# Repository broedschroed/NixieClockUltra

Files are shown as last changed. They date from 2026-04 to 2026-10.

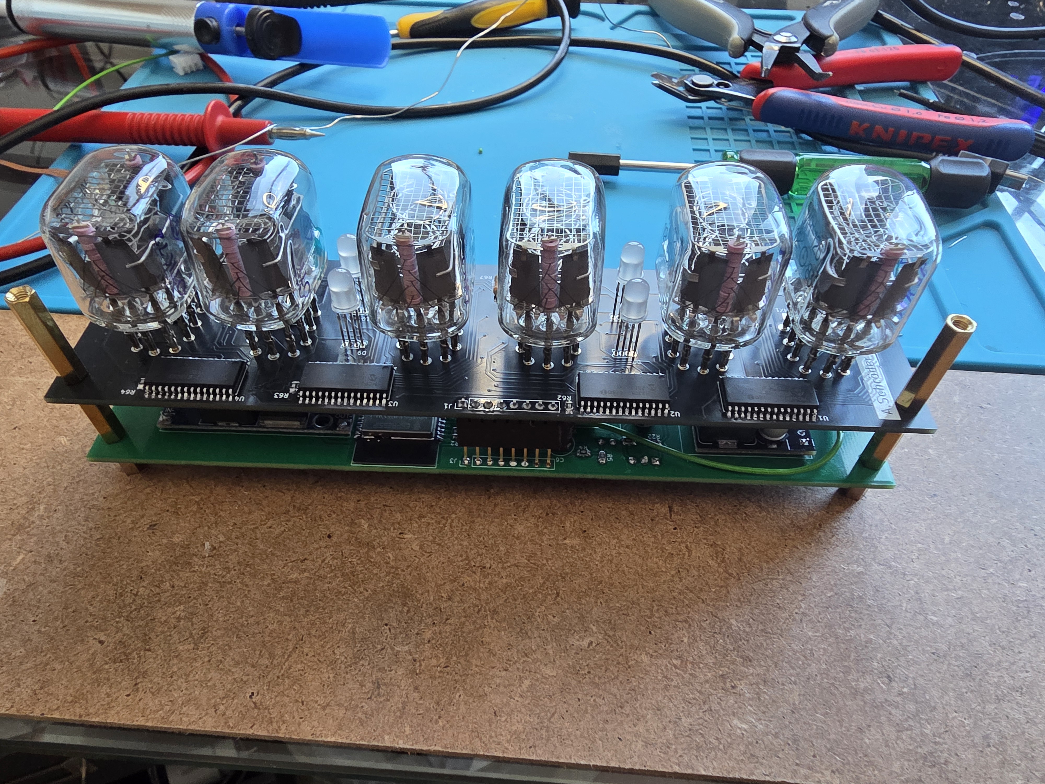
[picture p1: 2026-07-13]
docs/website/img/gallery/10 Chassis montiert.jpg

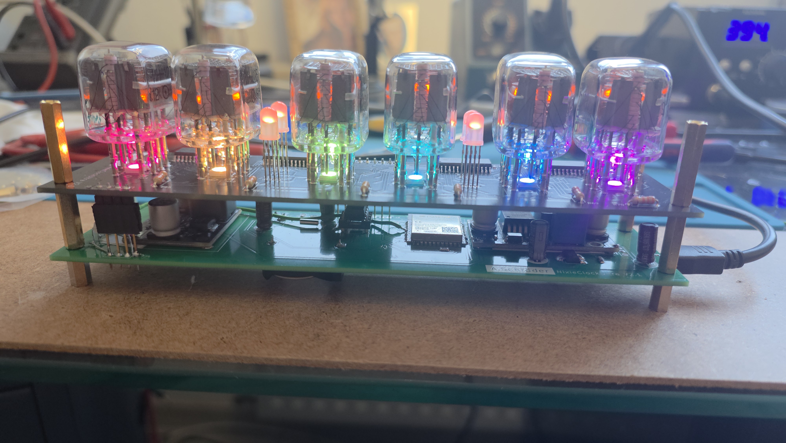
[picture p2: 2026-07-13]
docs/website/img/gallery/16 Chassis im Betrieb 3.jpg

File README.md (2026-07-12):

# Nixie Clock Ultra

A handcrafted Nixie tube clock built around an ESP32-S3, combining the warm,
unmistakable glow of six IN-12A Nixie tubes with modern connectivity: a full
web interface, IR remote, RGB ambient lighting, and automatic NTP time sync.

**🌐 Project website:** https://broedschroed.github.io/NixieClockUltra/

## Highlights

- **Direct drive, zero ghosting** — every cathode is switched by its own
  transistor (via MCP23017 I/O expanders), so there's no multiplexing and no
  flicker or ghosting between digits.
- **Web interface** — full control from any browser on the local network, no
  app required.
- **IR remote** — seven learnable functions (set time, brightness, animation,
  slot effect, colon toggle, ...).
- **RGB ambient lighting** — 10x WS2812B NeoPixels with rainbow, static, and
  pulse animation modes, plus a slot-machine digit-shuffle effect.
- **Night mode** — dims the tubes via hardware PWM on the anode voltage,
  triggered by a schedule or an onboard light sensor (LDR).
- **Soft digit transitions** — smooth crossfade between digits instead of an
  abrupt switch.
- **DS1302 RTC** with automatic NTP sync when connected to WiFi.

## Hardware

- ESP32-S3 (native USB)
- 6x IN-12A Nixie tubes, driven directly through 4x MCP23017 I2C expanders
- ~170V HV supply for the tubes, switched via a TLP627 opto-coupler for
  hardware-PWM dimming
- DS1302 RTC
- 10x WS2812B NeoPixels
- VS1838 IR receiver
- 4 physical buttons (Set / Up / Down / Light)

KiCad sources for the logic board and the Nixie display board are included
under `docs/system/`.

## Repository layout

- `*.ino` / `*.h` — firmware (Arduino/ESP32 sketch)
- `test/` — host-side unit tests for the fade math
- `docs/manual/` — user manual
- `docs/system/` — system documentation and KiCad hardware sources
- `docs/website/` — source of the project website (deployed via GitHub Pages)

## Building

Open the sketch in the Arduino IDE (or arduino-cli) with the ESP32 core
installed, board set to an ESP32-S3 module with **USB CDC on Boot: Enabled**,
and the required libraries (ArduinoJson, ESPAsyncWebServer, IRremoteESP8266,
Adafruit NeoPixel). Flash and connect to the `NixieClockCS` WiFi hotspot (or
your home network once configured) to reach the web interface.

## License

Released under the [MIT License](LICENSE).

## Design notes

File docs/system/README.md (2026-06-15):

# Nixie Clock Ultra – Systemdokumentation

Die Nixie Clock Ultra ist eine ESP32-S3-basierte Röhrenuhr mit 6 IN-12A Nixie-Röhren.
Die Hardware verteilt sich auf zwei Platinen: das **Logic Board** (ESP32-S3, RTC, HV-Versorgung)
und das **Nixie Display Board** (4× MCP23017 I²C-Expander, 60 NPN-Transistoren, NeoPixel-LEDs).
Die Nixie-Röhren werden direkt ohne Multiplexing angesteuert — jede Kathode hat einen
eigenen Transistor, was Ghosting vollständig eliminiert.

## Zweiplatinenübersicht

| Platine | KiCAD-Projekt | Hauptfunktion |
|---|---|---|
| Logic Board | nixieclocklogic_V2 | ESP32-S3, DS1302 RTC, HV-Modul, Taster, IR, USB |
| Nixie Display Board | nixieclockin12_V2 | 4× MCP23017, 6× IN-12A, 60× NPN, WS2812B |

Die Boards sind über zwei Steckverbinder verbunden:
- **J3 ↔ J1** (8-polig „Logic"): 3,3 V, GND, I²C (SDA/SCL), NeoPixel-Daten
- **J4 ↔ J2** (4-polig „HV"): ~170 V Anodenversorgung + HV-GND

## Systemblockschaltbild

```mermaid
flowchart TD
    subgraph PWR["Stromversorgung"]
        USB["5V USB / Netzteil"]
        LDO["AMS1117 → 3,3V"]
        HV["HV-MOD → ~170V DC"]
    end

    subgraph LB["Logic Board – ESP32-S3-WROOM-1"]
        ESP["ESP32-S3 Kern"]
        RTC_IC["DS1302 RTC\nIO=GPIO4 CLK=GPIO5 CE=GPIO2"]
        IR_IC["VS1838B IR-Empfänger\nGPIO48"]
        BTNS["Taster SET/UP/DOWN/LIGHT\nGPIO13–16"]
        NVS["NVS Flash\nPreferences"]
        WIFI["WiFi-Stack AP + STA"]
    end

    subgraph DB["Nixie Display Board"]
        MCP["4× MCP23017\nI²C-Adressen 0x20–0x23"]
        NPN["60× SMBTA42 NPN\nKathodenschalter"]
        NX["6× IN-12A Nixie-Röhren"]
        NEO["10× WS2812B NeoPixel\nGPIO21"]
    end

    NTP["NTP pool.ntp.org"]
    BROWSER["Web-Browser\nhttp://192.168.4.1"]

    USB --> LDO & HV
    LDO --> LB & DB
    HV -- "Anoden ~170V (via J4↔J2)" --> NX

    ESP -- "I²C SDA=GPIO8 SCL=GPIO9\n(via J3↔J1)" --> MCP
    MCP -- "64 GPIO-Ausgänge\n(je 16 pro IC)" --> NPN
    NPN -- "Kathoden auf GND ziehen" --> NX
    ESP -- "GPIO21 NeoPixel-Daten\n(via J3↔J1)" --> NEO
    ESP <-->|"ThreeWire"| RTC_IC
    IR_IC -->|"demoduliertes IR-Signal"| ESP
    BTNS -->|"INPUT_PULLUP"| ESP
    ESP <--> NVS
    ESP <--> WIFI
    WIFI -->|"einmalig bei STA-Verbindung"| NTP
    WIFI <-->|"HTTP /api/*"| BROWSER
```

## Bibliotheksabhängigkeiten

Alle Bibliotheken über den Arduino Library Manager installieren:

| Bibliothek | Autor / Quelle | Zweck |
|---|---|---|
| Adafruit NeoPixel  | Adafruit | WS2812B-Ansteuerung (GRB + RGB) |
| Rtc by Makuna | Michael C. Miller | DS1302 RTC über ThreeWire |
| AsyncTCP | me-no-dev | Async-TCP-Basis für ESP32 |
| ESPAsyncWebServer  | me-no-dev | Nicht-blockierender HTTP-Server |
| ArduinoJson | Benoit Blanchon | JSON-Serialisierung (v6.x, nicht v7) |
| IRremoteESP8266 | David Conran | IR-Empfang (NEC, Samsung, RC5 …) |

## Weiterführende Dokumente

- **Hardware-Details:** [hardware.md](hardware.md)
- **Firmware-Architektur:** [firmware.md](firmware.md)
- **Bedienungsanleitung:** [../manual/nixie-clock-ultra-bedienungsanleitung.html](../manual/nixie-clock-ultra-bedienungsanleitung.html)

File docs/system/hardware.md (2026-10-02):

# Hardware-Dokumentation

## PCB 1 – Logic Board

**KiCAD-Projekt:** `nixieclocklogic_V2-2` · Rev 2.1 · 2026-07-25

Das Logic Board beherbergt den Mikrocontroller, die Echtzeituhr, die Hochspannungserzeugung
und alle Nutzerschnittstellen (Taster, IR, USB). Es versorgt das Nixie Display Board
über zwei dedizierte Steckverbinder.

### Hauptkomponenten

| Ref  | Bauteil | Funktion |
|---|---|---|
| U1 | ESP32-S3-WROOM-1 | Mikrocontroller, WiFi/BT, 4 MB Flash |
| U2 | DS1302N+ (DIP-8) | Batteriegepufferte Echtzeituhr |
| U3 | VS1838B | IR-Empfänger/-Demodulator 38 kHz |
| U4 | HV-MOD | Boost-Converter, erzeugt ~170 V DC für Nixie-Anoden |
| U5 | AMS1117-3.3 (SOT-223)| LDO-Linearregler 5V → 3,3V |
| U7 | TLP627 (DIP-4) | Optokoppler schaltet Anodenspannung per Hardware-PWM (Nacht-Modus-Dimmung) |
| U22  | USBLC6-2SC6 (SOT-23-6)| USB-ESD-/TVS-Schutz |
| BT1  | CR2032 | RTC-Backup-Batterie |
| Y1 | 32,768 kHz Quarz | RTC-Taktquelle |
| SW1  | SET | Taster: Einstellmodus starten / Zeit speichern  |
| SW2  | UP | Taster: Wert erhöhen |
| SW3  | DOWN | Taster: Wert verringern |
| SW4  | LIGHT | Taster: Helligkeit / Trennpunkte |
| SW5  | BOOT | ESP32-Bootmodus (Programmierung) |
| J2 | USB Micro-B | 5V-Einspeisung und Firmware-Upload |
| J3 | Logic (8-polig) | Inter-Board: Logik-Signale → Nixie Display |
| J4 | HV (4-polig) | Inter-Board: ~170V Anodenversorgung → Display |
| J5 | LDR (2-polig) | Helligkeitssensor, bestückt: LDR→VCC, 100 kΩ→GND, Messung an GPIO6 |

### Versorgungsschienen

| Schiene | Spannung  | Quelle | Verbraucher |
|---|---|---|---|
| VCC | 5V | J2 USB | U4 HV-MOD, U5 AMS1117 |
| +3,3V | 3,3V | U5 | ESP32-S3, DS1302, VS1838B, Pull-ups  |
| HV | ~170V DC  | U4 | Nixie-Anoden (via J4) |
| HVgnd | GND (HV)  | U4 | HV-Rückleiter (galvanisch getrennt)  |

---

## PCB 2 – Nixie Display Board

**KiCAD-Projekt:** `nixieclockin12_V2-1` · Rev 2.01 · 2026-07-25

Das Display Board enthält die eigentliche Anzeigeelektronik. Die vier MCP23017 treiben
je 16 NPN-Transistoren, die die Nixie-Kathoden individuell auf GND schalten. Die Anoden
aller Röhren liegen gemeinsam an der über J4 eingespeisten Hochspannung (~170V), die
auf dem Logic Board per TLP627-Hardware-PWM gedimmt werden kann (siehe Nacht-Modus in
[firmware.md](firmware.md)).

**Optional:** Statt des einen gemeinsamen Schalters auf dem Logic Board kann jede Anode
über einen eigenen TLP627-Schalter auf dem Display Board unabhängig gedimmt werden
(6× TLP627 statt 1×, siehe Komponententabelle unten). Das ermöglicht einen weichen
Ziffernwechsel pro Röhre, bei dem unveränderte Ziffern nicht mitblinken. Aktiviert wird
das per `HV_PER_TUBE_DIMMER`-Compile-Switch in der Firmware
([firmware.md](firmware.md#wichtige-defines)) — ohne bestückte Zusatzschalter bleibt der
gemeinsame Schalter aktiv. Der gemeinsame Logic-Board-Schalter sollte bei dieser Umrüstung
entfernt oder dauerhaft überbrückt werden; die Firmware hält sein Steuersignal (GPIO7) bei
aktiviertem HV_PER_TUBE_DIMMER zur Sicherheit dauerhaft auf HIGH (offen), falls er nicht
ausgebaut wird.

### Hauptkomponenten

| Ref | Bauteil | Anzahl | Funktion |
|---|---|---|---|
| U1–U4 | MCP23017-E/SO (SOIC-28) | 4 | 16-bit I²C GPIO-Expander; je 16 Ausgänge |
| Q1–Q60 | SMBTA42 (TSOT-23) | 60 | NPN-Transistor 300V als Kathoden-Schalter |
| NX1–NX6  | IN-12A | 6 | Numerische Nixie-Röhre (Aufsicht, 10 Kathoden)  |
| D1 | WS2812B-SMD (×6) | 6 | Hintergrundbeleuchtung (Pixel 0–5, GRB) |
| D2–D6 | WS2812B-SMD | 5 | Zusätzliche LEDs / Trennpunkte (SMD) |
| D7–D9 | WS2812B-THT (YF923)  | 3 | Trennpunkt-LEDs (Durchsteck, RGB) |
| R1–R64 | 3,3 kΩ (0805) | 64 | Basis-Vorwiderstände für Q1–Q60 |
| R65–R70  | 22 kΩ (THT, axial) | 6 | Anodenwiderstände (Strombegrenzung je Röhre, ~1,5 mA bei ~175 V) — nicht kleiner wählen, sonst steigt die 5-V-Stromaufnahme über 1 A (Brownouts) |
| C1–C4 | 100 nF (0805) | 4 | Abblockkondensatoren je MCP23017 |
| J1 | Logic (8-polig) | 1 | Inter-Board: Logik-Signale ← Logic Board |
| J2 | HV (4-polig) | 1 | Inter-Board: ~170V ← Logic Board |
| U5–U10 | TLP627 (DIP-4) | 6 (optional) | Pro-Röhre-Anodenschalter — ersetzt bei Bestückung den gemeinsamen Logic-Board-Schalter für unabhängiges Dimmen jeder Röhre |

### MCP23017 I²C-Adressen und Röhrenzuordnung

Die Adresspins A2, A1, A0 der MCP23017 sind durch Pull-ups auf GND oder VCC verdrahtet:

| IC  | I²C-Adresse | A2 | A1 | A0 | Zuständige Röhre(n) |
|-----|---|----|----|----|---|
| U1  | 0x20 | 0  | 0  | 0  | Tube 0 (Stundenzehner), Tube 1 Bits 10–15 |
| U2  | 0x21 | 0  | 0  | 1  | Tube 1 Bits 0–3, Tube 2 (Minutenzehner) |
| U3  | 0x22 | 0  | 1  | 0  | Tube 3 (Minuteneiner), Tube 4 Bits 10–15|
| U4  | 0x23 | 0  | 1  | 1  | Tube 4 Bits 0–3, Tube 5 (Sekundeneiner) |

Jeder MCP23017 hat 16 Ausgänge (GPA0–7, GPB0–7). Die Tube-zu-Bit-Zuordnung ist
im Firmware-Modul `nixie_driver.ino` als `digitPin[6][10]`-Lookup-Tabelle implementiert
(→ [firmware.md](firmware.md#nixie-ansteuerung)).

### WS2812B NeoPixel-Konfiguration

Die 10 LEDs sind als verkettete Kette an GPIO21 angeschlossen:

| Pixel | Typ | Position | Farbreihenfolge |
|---|---|---|---|
| 0–5 | WS2812B-SMD | Röhrenhintergrund | GRB |
| 6–9 | WS2812B-THT | Trennpunkte | RGB |

> Die unterschiedliche Farbreihenfolge (GRB vs. RGB) der SMD- und THT-Varianten
> wird in der Firmware durch separate Farbberechnungen berücksichtigt.

---

## Inter-Board-Verbindungen

### J3 (Logic Board) ↔ J1 (Nixie Display Board) — 8-polig „Logic"

> Exakte Pin-Reihenfolge aus `nixieclocklogic_V2_BPHL.pdf` verifizieren.

| Signal  | Richtung | Beschreibung |
|---|---|---|
| VCC | Logic → Display | 3,3V Logikversorgung |
| GND | — | Digitalmasse |
| SDA | ESP32 ↔ MCP23017  | I²C Daten (GPIO8) |
| SCL | ESP32 → MCP23017  | I²C Takt (GPIO9) |
| NEO | ESP32 → D1 | WS2812B Datenleitung (GPIO21) |
| — | — | (reserviert) |

### J4 (Logic Board) ↔ J2 (Nixie Display Board) — 4-polig „HV"

| Signal | Richtung | Beschreibung |
|---|---|---|
| HV | Logic → Display | ~170V DC Anodenversorgung (×2 Pins) |
| HVgnd  | — | HV-Rückleiter (×2 Pins) |

---

## ESP32-S3 Pin-Belegung (vollständig)

| GPIO | Signal | Peripheral / Funktion |
|---|---|---|
| 2 | RTC_CE | DS1302 Chip Enable (ThreeWire) |
| 4 | RTC_IO | DS1302 Data (ThreeWire) |
| 5 | RTC_CLK | DS1302 Clock (ThreeWire) |
| 6 | LDR_ADC | LDR-Helligkeitssensor (ADC1, LDR→VCC, 100 kΩ→GND) |
| 7 | HV_SWITCH | TLP627-Optokoppler: Hardware-PWM (100 Hz, LEDC) schaltet Anodenspannung für Nacht-Modus-Dimmung |
| 8 | I2C_SDA | I²C Daten → 4× MCP23017 |
| 9 | I2C_SCL | I²C Takt → 4× MCP23017 |
| 10 | BTN_LIGHT | Taster LIGHT (INPUT_PULLUP, aktiv LOW) |
| 11 | BTN_DOWN  | Taster DOWN (INPUT_PULLUP, aktiv LOW)  |
| 12 | BTN_UP | Taster UP (INPUT_PULLUP, aktiv LOW) |
| 13 | BTN_SET | Taster SET (INPUT_PULLUP, aktiv LOW) |
| 15 | HV_TUBE_PIN_2 | *(optional)* Pro-Röhre-TLP627 Minutenzehner (nur bei `HV_PER_TUBE_DIMMER`) |
| 16 | HV_TUBE_PIN_3 | *(optional)* Pro-Röhre-TLP627 Minuteneiner (nur bei `HV_PER_TUBE_DIMMER`) |
| 17 | HV_TUBE_PIN_4 | *(optional)* Pro-Röhre-TLP627 Sekundenzehner (nur bei `HV_PER_TUBE_DIMMER`) |
| 18 | HV_TUBE_PIN_5 | *(optional)* Pro-Röhre-TLP627 Sekundeneiner (nur bei `HV_PER_TUBE_DIMMER`) |
| 21 | NEO_DATA  | WS2812B DIN (10 LEDs in Kette) |
| 38 | HV_TUBE_PIN_0 | *(optional)* Pro-Röhre-TLP627 Stundenzehner (nur bei `HV_PER_TUBE_DIMMER`) |
| 47 | HV_TUBE_PIN_1 | *(optional)* Pro-Röhre-TLP627 Stundeneiner (nur bei `HV_PER_TUBE_DIMMER`) |
| 48 | IR_RECV | VS1838B demodulierter Ausgang |

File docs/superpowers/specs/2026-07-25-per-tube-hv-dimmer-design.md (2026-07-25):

# Design: Pro-Röhre-HV-Dimmer für weichen Ziffernwechsel

## Kontext

Die IN-12-Leiterkarte wird so umgebaut, dass jede der 6 Nixie-Anoden optional
einen eigenen TLP627-Optokoppler-Schalter bekommt, statt sich (wie heute) einen
einzigen gemeinsamen Schalter (`HV_SWITCH_PIN`, GPIO7) zu teilen. Die neue
Bestückung ist optional — bestehende, unmodifizierte Uhren müssen sich nach
dem Firmware-Update exakt wie zuvor verhalten.

**Heutiges Verhalten:** Beim weichen Ziffernwechsel (`digit_fade.ino`) wird die
gemeinsame Anodenspannung aller 6 Röhren ab- und wieder aufgeblendet — auch für
Röhren, deren Ziffer sich gar nicht ändert (z. B. blinken beim Sekundentakt
Stunden/Minuten sichtbar mit).

**Ziel:** Mit den 6 separaten Schaltern soll nur die Röhre abblenden, deren
Ziffer sich tatsächlich ändert; unveränderte Röhren bleiben durchgehend hell.
Der weiche Übergang soll außerdem auch im gedimmten Nacht-Modus laufen (aktuell
nur bei `NIGHT_NORMAL`), dort zwischen Minimal-Duty und der reduzierten
Ziel-Helligkeit (`hvDimPct`) statt bis 100 %.

Ein Compile-Time-`#define` schaltet zwischen Alt- und Neu-Verhalten, da die
Hardware optional bestückt wird.

## 1. Pin-Belegung

Neue Defines in `NixieClockUltra.ino`, nur wirksam wenn `HV_PER_TUBE_DIMMER`
aktiviert ist:

```cpp
// Bei bestücktem Pro-Röhre-HV-Schalter (6× TLP627) einkommentieren:
// #define HV_PER_TUBE_DIMMER
#define HV_TUBE_PIN_0  38   // Stundenzehner (HZ)
#define HV_TUBE_PIN_1  47   // Stundeneiner  (HE)
#define HV_TUBE_PIN_2  15   // Minutenzehner (MZ)
#define HV_TUBE_PIN_3  16   // Minuteneiner  (ME)
#define HV_TUBE_PIN_4  17   // Sekundenzehner(SZ)
#define HV_TUBE_PIN_5  18   // Sekundeneiner (SE)
```

Ausgewählt unter Vermeidung von: Strapping-Pins (0, 3, 45, 46), nativem USB
(19, 20), JTAG (39–42), PSRAM/Octal-Flash-Bereich (26–37), sowie GPIO 1 und 14
(vom Nutzer für einen externen USB-Treiber reserviert) und allen bereits
belegten Pins (RTC 2/4/5, LDR 6, HV_SWITCH_PIN 7, I²C 8/9, Buttons 10–13,
NeoPixel 21, IR 48).

**Offener Punkt:** Vor dem Verdrahten gegenchecken, dass die konkrete
WROOM-1-Variante keine PSRAM/Flash-Sonderfunktion auf einem der 6 vorgeschlagenen
Pins hat.

## 2. Hardware-Abstraktion (`hv_dimmer.ino`)

Zwei API-Funktionen statt bisher einer, mit `#ifdef`-Zweig komplett isoliert in
dieser einen Datei:

```cpp
#ifdef HV_PER_TUBE_DIMMER
static const uint8_t hvTubePin[6] = {
  HV_TUBE_PIN_0, HV_TUBE_PIN_1, HV_TUBE_PIN_2,
  HV_TUBE_PIN_3, HV_TUBE_PIN_4, HV_TUBE_PIN_5
};

void hvDimmerInit() {
  for (uint8_t i = 0; i < 6; i++) {
    ledcAttach(hvTubePin[i], HV_PWM_FREQ_HZ, 8);
    ledcWrite(hvTubePin[i], 255);
  }
}
void hvDimmerSetDutyAll(uint8_t duty) {
  for (uint8_t i = 0; i < 6; i++) ledcWrite(hvTubePin[i], duty);
}
void hvDimmerSetDutyTube(uint8_t tube, uint8_t duty) {
  ledcWrite(hvTubePin[tube], duty);
}

#else  // heutige Hardware: ein gemeinsamer Schalter
void hvDimmerInit() {
  ledcAttach(HV_SWITCH_PIN, HV_PWM_FREQ_HZ, 8);
  ledcWrite(HV_SWITCH_PIN, 255);
}
void hvDimmerSetDutyAll(uint8_t duty) { ledcWrite(HV_SWITCH_PIN, duty); }
void hvDimmerSetDutyTube(uint8_t /*tube*/, uint8_t duty) { ledcWrite(HV_SWITCH_PIN, duty); }
#endif
```

Im Alt-Zweig ignoriert `hvDimmerSetDutyTube()` den Röhrenindex und steuert den
gemeinsamen Schalter an — dadurch bleibt das heutige Verhalten (alle dimmen
gemeinsam bei jeder Änderung) automatisch erhalten, ohne dass `digit_fade.ino`
selbst ein `#ifdef` braucht.

LEDC-Kanäle: 1 (Alt-Zweig) bzw. 6 (Neu-Zweig), beide Zweige schließen sich
gegenseitig aus — bleibt klar unter dem Limit von 8 Kanälen des ESP32-S3.

## 3. Fade-Logik (`digit_fade.ino` + `digit_fade_math.h`)

Neue reine, host-testbare Helfer-Funktion in `digit_fade_math.h`:

```cpp
inline uint8_t computeChangedMask(const uint8_t oldDigits[6], const uint8_t newDigits[6]) {
  uint8_t mask = 0;
  for (uint8_t i = 0; i < 6; i++) if (oldDigits[i] != newDigits[i]) mask |= (1 << i);
  return mask;
}
```

`display.ino`s `commitDigits()` berechnet die Maske **vor** dem Überschreiben
von `displayDigits` und reicht sie an `startDigitFade(newDigits, mask, fadeMs)`
durch.

Fade-Zustand bleibt ein **gemeinsamer** Schritt-Zähler (kein Bedarf an 6
unabhängigen Timern, da alle aktuellen Trigger — Sekundentakt, manuelles
Setzen, Datumsanzeige — Ziffern immer gemeinsam committen). Zusätzlich zum
bisherigen Zustand:

- `fadeMask` — welche Röhren-Bits betroffen sind
- `fadeMaxDuty` — Ziel-Helligkeit oben, einmalig beim Fade-Start ermittelt:
  `255` bei `NIGHT_NORMAL`, `hvDimPct * 255 / 100` bei `NIGHT_DIM`

`updateDigitFade()`: iteriert pro Schritt nur über die in `fadeMask` gesetzten
Bits und ruft `hvDimmerSetDutyTube(i, duty)` auf — unveränderte Röhren werden
nie angefasst.

**Verhaltensänderung:** Die Trigger-Bedingung in `commitDigits()` wechselt von
`nightState == NIGHT_NORMAL` zu `nightState != NIGHT_DARK`, damit der weiche
Wechsel jetzt auch im Dimm-Modus läuft. In `NIGHT_DARK` bleibt es beim harten
Umschalten (Anodenspannung ist ohnehin aus, ein Fade wäre unsichtbar).

`cancelDigitFade()` / `fadeFinishImmediately()`: setzen beim vorzeitigen
Abbruch nur die Röhren aus der aktuellen `fadeMask` auf `fadeMaxDuty` zurück
(nicht mehr pauschal alle 6) — verhindert ein falsches Aufblitzen auf 100 % bei
einem Nacht-Modus-Wechsel während eines laufenden Fades.

## 4. Anpassungen bestehender Aufrufstellen

Reines Rename `hvDimmerSetDuty(...)` → `hvDimmerSetDutyAll(...)`, keine
Logikänderung, an:

- `NixieClockUltra.ino` — Nacht-Zustands-Switch (~Zeile 413–415)
- `tube_test.ino` — Röhrentest erzwingt volle Helligkeit (~Zeile 17) und eigener
  Nacht-Zustands-Switch (~Zeile 43–45)
- `web_server.ino` — Live-Update von `hvDimPct` während `NIGHT_DIM` (~Zeile 746)

## 5. Test-Plan

- `test/digit_fade_math_test.cpp` erweitert um Fälle für `computeChangedMask()`:
  keine Änderung (`mask == 0`), eine Röhre geändert, alle 6 geändert, Bit-Position
  entspricht Röhren-Index (0 = HZ … 5 = SE).
- Bestehende `fadeDutyForStep()`-Tests bleiben unverändert gültig.
- Hardware-Test auf echtem Board:
  1. `HV_PER_TUBE_DIMMER` **aus**: Sekunden-/Minuten-/Stundenwechsel, Nacht-Modus,
     Röhrentest durchklicken — nichts darf sich gegenüber heute verändert haben.
  2. `HV_PER_TUBE_DIMMER` **an** (mit bestückter Hardware): nur wechselnde
     Ziffern blenden ab, unveränderte bleiben durchgehend hell; Fade funktioniert
     auch im Dimm-Modus.

## 6. Doku-Updates

- `docs/system/hardware.md` — neuer Abschnitt zu den 6 optionalen TLP627 in der
  Pin-Belegungstabelle und bei „Nixie Display Board"; Hinweis auf Optionalität.
- `docs/system/firmware.md` — Modulübersicht (`hv_dimmer.ino`-Zeile), neue
  Defines, `hvDimmerSetDutyAll()`/`hvDimmerSetDutyTube()` statt
  `hvDimmerSetDuty()`, Nacht-Modus-Logik-Abschnitt.
- `docs/manual/nixie-clock-ultra-bedienungsanleitung.html` — Hinweis im
  Hardware-Kapitel, dass der weiche Ziffernwechsel bei bestückter
  Pro-Röhre-Option jetzt nur die wechselnde Ziffer abblendet (ohne
  Bauteilnamen im Fließtext, gemäß bisherigem Schreibstil).
- `docs/website/aufbau.html` / `docs/website/features.html` — TLP627-Erwähnung
  um „optional pro Röhre nachrüstbar" ergänzen, Feature-Beschreibung des weichen
  Ziffernwechsels aktualisieren.

## Out of Scope

- Keine Laufzeit-Umschaltung (NVS/Web-UI) zwischen Alt- und Neu-Hardware —
  bewusst Compile-Time-`#define`, da die Hardware-Variante pro gebauter Uhr fest
  ist.
- Keine unabhängigen Timer pro Röhre — aktuell kein Anwendungsfall, der
  zeitlich versetzte Fades einzelner Röhren bräuchte.

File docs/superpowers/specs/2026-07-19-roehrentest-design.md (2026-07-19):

# NixieClockUltra – Röhrentest

**Datum:** 2026-07-19
**Status:** Genehmigt
**Branch:** neu anzulegen von `master`

---

## Überblick

Diagnose-Feature für die Nixie-Röhren: Ein Web-UI-Button zeigt auf
allen 6 Röhren gleichzeitig nacheinander jede Ziffer 0–9 für je 2
Sekunden an (20s Gesamtlaufzeit). Zweck: optisch prüfen, ob jede
Ziffer in jeder Röhre sauber leuchtet (defekte Kathode, kalte
Lötstelle an Transistor/MCP23017) – die bestehende Slot-Machine-
Animation reicht dafür nicht, da sie pro Röhre nur kurz durchrollt
und nie alle Röhren synchron auf derselben Ziffer stehen bleiben.

Kein neues physisches Bedienelement, keine IR-Anbindung – ausschließlich
über die Web-UI, ergänzt in der bestehenden Karte "Slot-Animation".

---

## 1. State-Machine (neues Modul `tube_test.ino`)

Analog zu `updateSlotAnimation()` / `updateDigitFade()`: non-blocking,
angetrieben von `updateTubeTest()` in `loop()`.

```cpp
bool     tubeTestActive    = false;
uint8_t  tubeTestDigit     = 0;      // 0–9, aktuell angezeigte Ziffer
uint32_t tubeTestStepStart = 0;
#define  TUBE_TEST_STEP_MS 2000

void startTubeTest() {
  cancelDigitFade();
  slotActive     = false;   // laufende Slot-Animation abbrechen
  dateShowActive = false;   // laufende Datumsanzeige abbrechen
  editState      = EDIT_NONE;   // Einstellmodus verlassen

  tubeTestActive    = true;
  tubeTestDigit     = 0;
  tubeTestStepStart = millis();

  hvDimmerSetDuty(255);   // volle Helligkeit erzwingen, unabhängig von Nacht-Modus

  uint8_t d[6] = {0,0,0,0,0,0};
  memcpy(displayDigits, d, 6);
  nixieWrite(displayDigits);   // sofort hart, kein Fade
}

void updateTubeTest() {
  if (!tubeTestActive) return;
  if (millis() - tubeTestStepStart < TUBE_TEST_STEP_MS) return;

  tubeTestDigit++;
  if (tubeTestDigit > 9) {
    stopTubeTest();
    return;
  }
  tubeTestStepStart = millis();
  uint8_t d[6] = {tubeTestDigit, tubeTestDigit, tubeTestDigit,
                  tubeTestDigit, tubeTestDigit, tubeTestDigit};
  memcpy(displayDigits, d, 6);
  nixieWrite(displayDigits);
}

void stopTubeTest() {
  if (!tubeTestActive) return;
  tubeTestActive = false;

  // HV-Duty passend zum aktuellen Nacht-Modus-Zustand wiederherstellen
  switch (nightState) {
    case NIGHT_DARK:   hvDimmerSetDuty(0);                    break;
    case NIGHT_DIM:    hvDimmerSetDuty(hvDimPct * 255 / 100); break;
    case NIGHT_NORMAL: hvDimmerSetDuty(255);                  break;
  }
  prevNightState = nightState;   // verhindert doppelte Duty-Anwendung im nächsten loop()

  setDisplayTime(curHour, curMin, curSec);   // Uhrzeit sofort wieder anzeigen
}
```

**Re-Start-Verhalten:** Aufruf von `startTubeTest()` während der Test
bereits läuft ist erlaubt und setzt ihn einfach auf Ziffer 0 zurück
(kein Fehlerfall). `stopTubeTest()` ohne aktiven Test ist ein No-op.

**Doppelte Nacht-Modus-Duty-Anwendung:** `NixieClockUltra.ino::loop()`
erkennt Nacht-Modus-Wechsel über `nightState != prevNightState` und
setzt dann die Duty. `stopTubeTest()` setzt `prevNightState` explizit
mit, damit dieser Vergleich direkt danach nicht erneut anschlägt und
die gerade gesetzte Duty nicht überschreibt.

---

## 2. Integration `NixieClockUltra.ino::loop()`

Bestehende Blöcke werden um `!tubeTestActive`-Guards ergänzt, damit
die normale Uhr während des Tests nicht dazwischenschreibt:

```cpp
// RTC-Lese-Block: Sekundentakt-Update / Slot-Trigger nur außerhalb Test
if (editState == EDIT_NONE && millis() - lastRtcRead >= 500) {
  lastRtcRead = millis();
  readRTC();
  if (curSec != lastSec) {
    lastSec = curSec;
    if (!tubeTestActive) {
      // ... bestehende Slot-Trigger-/setDisplayTimeSoft-Logik unverändert
    }
  }
}

// Slot-Animation-Update: unverändert, da slotActive bereits durch
// startTubeTest() auf false gesetzt wird

// Einstellmodus: während des Tests pausiert, damit ein SET-Tastendruck
// nicht parallel den Editiermodus startet
if (!tubeTestActive) handleEditMode();

updateTubeTest();   // neu, an der Stelle von updateDigitFade()
```

Der bestehende `nightState != prevNightState`-Block (HV-Duty bei
Nacht-Modus-Wechsel) bleibt unverändert – er greift während des Tests
nicht, weil `stopTubeTest()` `prevNightState` synchron mitführt (siehe
oben); ein Nacht-Modus-Wechsel *während* eines laufenden Tests würde
aber weiterhin die Duty umschalten (Testabbruch durch Nacht-Modus ist
nicht vorgesehen – vernachlässigbarer Edge-Case, Test läuft nur 20s
und wird typischerweise manuell direkt am Gerät ausgelöst).

---

## 3. Web-UI

### 3.1 Karte (bestehende "🎰 Slot-Animation", umbenannt)

```html
<div class="card">
  <h2>🎰 Slot-Animation &amp; Röhrentest</h2>
  <!-- ... bestehende Slot-Intervall/Geschwindigkeit/Trigger-Reihen unverändert ... -->

  <div class="row">
    <button id="tubeTestBtn" onclick="toggleTubeTest()">Röhrentest starten</button>
    <span class="badge" id="tubeTestStatus">bereit</span>
  </div>
</div>
```

### 3.2 JavaScript

```js
let tubeTestRunning = false;

async function toggleTubeTest(){
  if (tubeTestRunning) await api('/api/tubetest/stop', {});
  else                 await api('/api/tubetest/start', {});
}
```

`refreshClock()` (bestehendes 1s-Polling von `/api/status`) wird
erweitert:

```js
if (d.tubeTest !== undefined) {
  tubeTestRunning = d.tubeTest;
  document.getElementById('tubeTestBtn').textContent =
    tubeTestRunning ? 'Abbrechen' : 'Röhrentest starten';
  document.getElementById('tubeTestStatus').textContent =
    tubeTestRunning ? `Ziffer ${d.tubeTestDigit}/9` : 'bereit';
}
```

### 3.3 Neue Endpunkte (`web_server.ino`)

```cpp
server.on("/api/tubetest/start", HTTP_POST, [](AsyncWebServerRequest *req){
  startTubeTest();
  req->send(200, "application/json", "{\"ok\":true}");
});

server.on("/api/tubetest/stop", HTTP_POST, [](AsyncWebServerRequest *req){
  stopTubeTest();
  req->send(200, "application/json", "{\"ok\":true}");
});
```

### 3.4 `/api/status` Erweiterung

```cpp
doc["tubeTest"]      = tubeTestActive;
doc["tubeTestDigit"] = tubeTestDigit;
```

`StaticJsonDocument<384>` auf `448` erhöhen (zwei zusätzliche Felder).

---

## 4. Nicht Teil dieser Änderung

- Kein physischer Tasten- oder IR-Trigger (nur Web-UI).
- Keine Konfigurierbarkeit der Anzeigedauer (fest 2s) oder Ziffernfolge
  über die Web-UI.
- Kein automatischer Abbruch bei Nacht-Modus-Wechsel während eines
  laufenden Tests (siehe Edge-Case-Hinweis in Abschnitt 2).
- Keine Änderung an NeoPixel-Verhalten während des Tests.

---

## 5. Testplan (manuell, auf Hardware)

- **Normalablauf:** Röhrentest starten → alle 6 Röhren zeigen
  synchron 0,1,2…9 für je ~2s, danach automatische Rückkehr zur
  aktuellen Uhrzeit. Button-Beschriftung/Badge wechseln währenddessen
  korrekt zwischen "Röhrentest starten"/"Abbrechen" und
  "bereit"/"Ziffer n/9".
- **Abbruch:** Während des Tests auf "Abbrechen" klicken → sofortige
  Rückkehr zur Uhrzeit, kein Hängenbleiben.
- **Neustart während laufendem Test:** Start-Endpoint erneut aufrufen
  → Test beginnt sichtbar wieder bei Ziffer 0.
- **Interaktion Nacht-Modus:** Test im `NIGHT_DIM`/`NIGHT_DARK`-Zustand
  starten → Röhren leuchten während des Tests mit voller Helligkeit;
  nach Testende kehrt die Dimmung korrekt zum vorherigen Zustand
  zurück (kein dauerhaftes "hängenbleiben" bei 100%).
- **Interaktion Einstellmodus/Slot:** Test während laufender
  Slot-Animation bzw. während SET-Taste gedrückt/Editiermodus aktiv
  auslösen → beide werden sauber abgebrochen, kein doppeltes
  Beschreiben der Röhren.

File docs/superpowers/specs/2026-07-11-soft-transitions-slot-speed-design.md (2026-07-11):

# NixieClockUltra – Weicher Ziffernwechsel & Slot-Machine-Geschwindigkeit

**Datum:** 2026-07-11
**Status:** Genehmigt
**Branch:** neu anzulegen von `master` (nach Commit `0516472`)

---

## Überblick

Zwei unabhängige, kleine Firmware-Erweiterungen, gemeinsam auf einem
Branch umgesetzt:

1. **Weicher Ziffernwechsel** – nutzt den bestehenden HV-Dimmer
   (`hv_dimmer.ino`, TLP627 auf `HV_SWITCH_PIN`) für einen kurzen
   Crossfade der gesamten Anodenspannung beim Wechsel zwischen
   Zeit- und Datumsanzeige, sowie optional bei jedem Sekundentakt.
2. **Slot-Machine-Geschwindigkeit** – ein Web-UI-Regler skaliert die
   Roll- und Stopp-Zeiten der bestehenden Slot-Animation
   (`updateSlotAnimation()`).

Beide Features sind per Web-UI ein-/ausschaltbar bzw. einstellbar und
persistieren ihre Einstellung in NVS (`Preferences`), analog zu allen
bestehenden Einstellungen im Projekt.

---

## 1. Weicher Ziffernwechsel

### 1.1 Scope

- Betrifft **ausschließlich** zwei Übergänge, jeweils per eigenem
  Web-UI-Toggle:
  - **Sekundentakt** (`softFadeSecondEnabled`, NVS-Key `sfSecEn`,
    Default `false`): jeder reguläre Zeit-Update-Aufruf
    (`curSec != lastSec`, außerhalb Slot-Animation/Datumsanzeige).
    Fade-Dauer: **100ms**.
  - **Zeit↔Datum-Wechsel** (`softFadeDateEnabled`, NVS-Key `sfDateEn`,
    Default `false`): Übergang Slot-Ende→Datumsanzeige und
    Datumsanzeige-Ende→Zeit. Fade-Dauer: **200ms**.
- **Nicht** betroffen: Slot-Machine-Animation selbst (rollt bereits
  schneller als eine Fade-Dauer), Editiermodus-Blinken
  (`buttons.ino`, ruft `nixieWrite()` direkt), Initialisierung/NTP-Sync.
- Der Effekt ist **nur im Zustand `NIGHT_NORMAL`** aktiv (volle
  Anodenspannung). Im Dimm-/Dunkel-Zustand bleibt der Ziffernwechsel
  hart, wie bisher – wird zentral erzwungen, nicht nur an den
  Aufrufstellen geprüft (siehe 1.3).
- Minimalhelligkeit während des Fades: **5%** Duty (≈13 von 255),
  fest codiert (`#define DIGIT_FADE_MIN_DUTY 13`).

### 1.2 Warum ein globaler Fade (kein Pro-Röhre-Crossfade)

Der TLP627 dimmt die Anodenspannung aller 6 Röhren gemeinsam über
einen einzigen LEDC-Kanal – es gibt keine Pro-Röhre-Dimmung. Ein Fade
betrifft daher immer das komplette Display, nicht nur die sich
ändernde Ziffer. Eine echte Pro-Röhre-Überblendung (zwei Kathoden
gleichzeitig an einer Röhre, Duty-Cycle-Verschiebung) wurde als
Alternative erwogen, aber verworfen: sie erfordert eine Prüfung, ob
der Anoden-Vorwiderstand doppelten Kathodenstrom verträgt, und
nähert sich konzeptionell der Mehrfach-Ansteuerung an, die beim
Anti-Ghosting-Umbau (Mai/Juni 2026) bewusst vermieden wurde. Nicht
Teil dieser Spec.

### 1.3 Neues Modul `digit_fade.ino`

Non-blocking State-Machine, angetrieben von `updateDigitFade()` in
`loop()` (wie `updateSlotAnimation()`):

```cpp
#define DIGIT_FADE_MIN_DUTY   13   // ~5% von 255
#define DIGIT_FADE_STEP_MS    5    // Schrittintervall

enum FadeState { FADE_IDLE, FADE_DOWN, FADE_UP };
static FadeState fadeState = FADE_IDLE;
static uint8_t   fadeTargetDigits[6];
static uint32_t  fadeLastStepMs;
static uint8_t   fadeStepsTotal;
static uint8_t   fadeStepsDone;

// Schließt einen laufenden Fade sofort ab (Zielziffern schreiben,
// Duty auf 255). Wird aufgerufen, wenn ein neuer Fade angefordert
// wird während einer noch läuft, oder wenn sich nightState während
// eines Fades ändert (verhindert Race mit der Nacht-Modus-Duty-
// Steuerung in NixieClockUltra.ino).
static void fadeFinishImmediately();

void startDigitFade(uint8_t newDigits[6], uint16_t fadeMs);
void updateDigitFade();   // in loop() aufrufen
void cancelDigitFade();   // von NixieClockUltra.ino bei nightState-Wechsel aufgerufen
```

**Ablauf pro Fade:**
1. `fadeStepsTotal = max(1, (fadeMs / 2) / DIGIT_FADE_STEP_MS)`
   (100ms → 10 Schritte runter + 10 rauf; 200ms → 20 + 20).
2. `FADE_DOWN`: pro Schritt Duty linear von 255 auf 13 interpolieren,
   `hvDimmerSetDuty()`.
3. Bei letztem Runter-Schritt: `nixieWrite(fadeTargetDigits)` (Ziffer
   bei Minimalhelligkeit umschalten), Zustand → `FADE_UP`.
4. `FADE_UP`: Duty linear von 13 zurück auf 255, letzter Schritt setzt
   exakt 255 und Zustand → `FADE_IDLE`.

### 1.4 Integration `display.ino`

`setDisplayTime()`/`setDisplayDate()` bleiben unverändert als
"sofort hart schreiben"-Funktionen (Startup, Editiermodus-Bestätigung
etc. nutzen weiterhin genau diese, unverändertes Verhalten). Beide
Funktionen und ihre neuen Soft-Varianten laufen über eine gemeinsame
interne Funktion:

```cpp
static void commitDigits(uint8_t newDigits[6], uint16_t fadeMs) {
  bool changed = memcmp(newDigits, displayDigits, 6) != 0;
  memcpy(displayDigits, newDigits, 6);
  if (!changed) return;
  if (fadeMs > 0 && nightState == NIGHT_NORMAL) {
    startDigitFade(newDigits, fadeMs);
  } else {
    nixieWrite(displayDigits);
  }
}

void setDisplayTime(uint8_t h, uint8_t m, uint8_t s);              // commitDigits(d, 0)
void setDisplayTimeSoft(uint8_t h, uint8_t m, uint8_t s, uint16_t fadeMs);
void setDisplayDate();                                              // commitDigits(d, 0)
void setDisplayDateSoft(uint16_t fadeMs);
```

### 1.5 Aufrufstellen `NixieClockUltra.ino`

Drei Stellen in `loop()` werden angepasst (fadeMs jeweils `0`, wenn
das zugehörige Toggle aus ist – identisch zum heutigen Verhalten):

- Sekundentakt (aktuell `setDisplayTime(curHour, curMin, curSec)`
  im `if (!slotActive && !dateShowActive)`-Zweig) →
  `setDisplayTimeSoft(curHour, curMin, curSec, softFadeSecondEnabled ? 100 : 0)`.
- Slot-Ende → Datumsanzeige (aktuell `setDisplayDate()`) →
  `setDisplayDateSoft(softFadeDateEnabled ? 200 : 0)`.
- Datumsanzeige-Ende → Zeit (aktuell `setDisplayTime(curHour, curMin, curSec)`) →
  `setDisplayTimeSoft(curHour, curMin, curSec, softFadeDateEnabled ? 200 : 0)`.

Zusätzlich: im bestehenden `nightState != prevNightState`-Block
(vor dem Setzen der nacht-modus-abhängigen Duty) wird
`cancelDigitFade()` aufgerufen, damit ein laufender Fade nicht mit
der Nacht-Modus-Duty-Steuerung kollidiert.

### 1.6 Web-UI & NVS

Neue Karte "Weicher Ziffernwechsel" mit zwei Checkboxen
("Bei Sekundentakt", "Bei Zeit/Datum-Wechsel"). Neuer Endpunkt
`/api/softfade`, GET (Status) + POST (Toggle setzen), Muster analog
zu `/api/nightmode`:

```cpp
server.on("/api/softfade", HTTP_GET, [](AsyncWebServerRequest *req) {
  // JSON: { sec: bool, date: bool }
});
server.on("/api/softfade", HTTP_POST, ...,
  // { sec?: bool, date?: bool } – nur übergebene Felder ändern
  // prefs.putBool("sfSecEn", ...) / prefs.putBool("sfDateEn", ...)
);
```

Laden beim Boot in `setup()` (analog zu `hvDimPct`):
```cpp
softFadeSecondEnabled = prefs.getBool("sfSecEn", false);
softFadeDateEnabled   = prefs.getBool("sfDateEn", false);
```

---

## 2. Slot-Machine-Geschwindigkeit

### 2.1 Scope

Neuer Regler in der Web-UI (bestehende Animations-Karte, neben
"Slot-Intervall"), Bereich **20%–100%**, Default **100%** (= aktuelles
Verhalten unverändert). Werte unter 100% verlangsamen die Animation,
keine Beschleunigung über die heutige Geschwindigkeit hinaus.

### 2.2 Variable & Persistenz

```cpp
uint8_t slotSpeedPct = 100;   // 20–100, NVS-Key "slotSpeed"
```

Laden in `setup()`:
```cpp
slotSpeedPct = (uint8_t)constrain((int)prefs.getUChar("slotSpeed", 100), 20, 100);
```

### 2.3 Anwendung in `display.ino`

Die beiden heute fest codierten Timing-Konstanten in
`updateSlotAnimation()` (Roll-Intervall 60ms, Stopp-Zeitplan
`600 + i*180`ms) werden **einmalig bei Animationsstart** skaliert und
zwischengespeichert – nicht pro Frame neu berechnet, damit ein
Reglerwechsel während einer laufenden Animation diese nicht
"ruckeln" lässt. Die neue Geschwindigkeit greift erst bei der
nächsten Animation.

```cpp
uint16_t slotRollIntervalMs;   // = 60 * 100 / slotSpeedPct
uint16_t slotStopMs[6];        // = (600 + i*180) * 100 / slotSpeedPct

void startSlotAnimation(uint8_t h, uint8_t m, uint8_t s) {
  slotRollIntervalMs = 60UL * 100 / slotSpeedPct;
  for (int i = 0; i < 6; i++) slotStopMs[i] = (600UL + i * 180) * 100 / slotSpeedPct;
  // ... bestehender Rest unverändert (slotTarget/slotCurrent/slotActive/slotStartMs)
}

void updateSlotAnimation() {
  // ... elapsed wie bisher
  // stopTime = slotStopMs[i]  statt  600 + i*180
  // Rollbedingung: (millis() % slotRollIntervalMs) < (slotRollIntervalMs / 2)
  //   statt  (millis() % 60) < 30
}
```

Bei 20%: Roll-Intervall 300ms, letzte Röhre stoppt nach 7,5s statt
1,5s. Bei 100%: unverändert.

### 2.4 Web-UI & NVS

Neuer Regler (`<input type="range" min="20" max="100">`), Endpunkt
`/api/slotspeed` (POST `{val}`), Muster analog zu `/api/neobright`.
Aktueller Wert zusätzlich in `/api/status` (`doc["slotSpeed"]`),
damit der Regler beim Laden der Seite korrekt initialisiert wird.

```cpp
server.on("/api/slotspeed", HTTP_POST, [](AsyncWebServerRequest *req){}, ...,
  [](AsyncWebServerRequest *req, uint8_t *data, size_t len, ...) {
    // JSON {val: int}
    slotSpeedPct = (uint8_t)constrain(doc["val"].as<int>(), 20, 100);
    prefs.putUChar("slotSpeed", slotSpeedPct);
    req->send(200, "application/json", "{\"ok\":true}");
  });
```

---

## 3. Testplan (manuell, auf Hardware)

- **Weicher Ziffernwechsel Sekundentakt:** Toggle an, `NIGHT_NORMAL`,
  beobachten dass jede Sekunde ein kurzes Abdunkeln/Aufhellen aller
  Röhren sichtbar ist (~100ms). Toggle aus → sofortiger Wechsel wie
  bisher.
- **Weicher Ziffernwechsel Zeit/Datum:** Slot-Intervall auf `SLOT_10S`
  stellen, warten bis Slot-Animation endet und Datumsanzeige startet
  → 200ms-Fade beobachten; nach 5s Rückwechsel zur Zeit → ebenfalls
  200ms-Fade.
- **Interaktion mit Nacht-Modus:** Während eines Sekundentakt-Fades
  in den Dimm-Zustand wechseln (LDR abdecken oder Zeitbereich
  triggern) → kein hängender Zwischenzustand, Duty landet korrekt auf
  Dimm-Helligkeit.
- **Slot-Speed:** Regler auf 20% stellen, Slot-Animation auslösen
  (manueller Trigger-Button in Web-UI) → deutlich langsameres Rollen,
  letzte Röhre stoppt nach ~7,5s. Regler zurück auf 100% → Verhalten
  wie vor dieser Änderung.
- Reboot nach jedem Test: alle vier neuen Einstellungen
  (`sfSecEn`, `sfDateEn`, `slotSpeed`, und ggf. Regler-Position in der
  UI) bleiben erhalten (NVS-Persistenz).

---

## Nicht Teil dieser Änderung

- Pro-Röhre-Crossfade (Dual-Kathoden-Technik, siehe 1.2).
- Konfigurierbarkeit von Fade-Dauer (100/200ms) oder Minimalhelligkeit
  (5%) über die Web-UI – fest codiert.
- Geschwindigkeiten über 100% (schneller als heute) für die
  Slot-Animation.

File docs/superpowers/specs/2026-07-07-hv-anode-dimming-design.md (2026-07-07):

# NixieClockUltra – Hardware-Dimmung der Anodenspannung (TLP627)

**Datum:** 2026-07-07
**Status:** Genehmigt
**Branch:** `feature/hv-anode-dimming` (abgezweigt von `master` nach Commit `a50de45`)

---

## Überblick

Ersatz der bisherigen Software-PWM-Dimmung der Nixie-Röhren (zyklisches
Kathoden-Blanking über die MCP23017, nur im Nacht-Modus aktiv) durch
echtes Hardware-PWM auf der Anodenspannung. Ein neuer GPIO steuert über
einen TLP627-Optokoppler direkt die Anodenspannung – der
Photodarlington-Ausgang des TLP627 ist laut Datenblatt
(„Recommended Operating Conditions“, Supply Voltage max. 200V) für die
~170V-Anodenspannung ausreichend spannungsfest, ein zusätzlicher
HV-Schalter ist nicht nötig.

**Scope:** Ausschließlich Ersatz von `NIGHT_DIM`/`NIGHT_DARK` für die
Nixie-Röhren. Volle Helligkeit (`NIGHT_NORMAL`) bleibt fest an. Die
NeoPixel-Dimmung im Nacht-Modus (`NIGHT_DIM_NEO_PCT`, per-Pixel
`scaleColor()`) ist unverändert und nicht Teil dieser Änderung.

Bereits in der Nacht-Modus-Spec vom 2026-06-21 als Option B vermerkt
(„Hardware-PWM für Nixie – kann später nachgerüstet werden“).

---

## 1. Hardware-Interface

### 1.1 GPIO

```cpp
#define HV_SWITCH_PIN  7   // unbenutzt, kein Strapping-Pin, neben LDR (GPIO6)
```

### 1.2 Signal-Vertrag

- **Aktiv-Pegel:** HIGH-Duty = Anode an (nicht invertiert).
- **PWM:** ESP32-S3 LEDC-Hardware-Peripherie, 8-Bit-Auflösung (Duty 0–255).
- **Frequenz:** 200 Hz (`#define HV_PWM_FREQ_HZ 200`) – deutlich über der
  Flimmerschwelle, aber im Bereich, den ein TLP627-getriebener
  HV-Schalter (Photodarlington-Schaltzeiten typisch einige zehn µs)
  sauber nachbilden kann. Bei Bedarf nach Hardware-Aufbau per
  Oszilloskop verifizieren und `#define` anpassen.

### 1.3 Downstream-Hinweis (nicht Teil dieser Firmware-Änderung)

Der TLP627-Photodarlington-Ausgang liegt direkt in Reihe mit der
Anodenspannung (kein zusätzlicher HV-Schalter nötig). Zwei Punkte, die
bei der analogen Dimensionierung zu beachten sind (Hardware-Sache des
Users, nicht Gegenstand dieser Spec):
- **Collector Current max. 120mA** – Summe des Anodenstroms aller 6
  Röhren muss darunter bleiben.
- **Forward Current typ. 16mA** – bestimmt den Vorwiderstand von
  GPIO7 zur TLP627-LED.

---

## 2. Neues Modul `hv_dimmer.ino`

```cpp
void hvDimmerInit();                      // ledcAttach(HV_SWITCH_PIN, HV_PWM_FREQ_HZ, 8) + volle Helligkeit
void hvDimmerSetDuty(uint8_t duty0to255); // ledcWrite(HV_SWITCH_PIN, duty0to255)
```

Kapselt die LEDC-Details (Core-3.x-API: `ledcAttach(pin, freq, resolution)`
statt der alten `ledcSetup()`/`ledcAttachPin()`-Kombination) an einer
Stelle.

`hvDimmerInit()` wird in `setup()` nach `strip.begin()`-Block aufgerufen
und setzt initial volle Helligkeit (Duty 255).

---

## 3. Integration in Nacht-Modus (`NixieClockUltra.ino`)

### 3.1 Entfernter Code

Der komplette bisherige Software-PWM-Block in `loop()` entfällt:
- `nixiePwmOn` (Variable + Logik)
- `lastPwmToggle`
- zyklisches `nixieWrite(blank)` / `nixieWrite(displayDigits)`-Umschalten
- `#define NIGHT_DIM_PWM_PERIOD` und `#define NIGHT_DIM_DUTY_PCT`

Die Röhren zeigen im Nacht-Modus durchgehend die echten Ziffern
(`nixieWrite(displayDigits)` wie tagsüber) – ohne Anodenspannung
leuchtet nichts, ein Blank-Schreiben ist überflüssig.

### 3.2 Neue Logik beim Zustandswechsel

```cpp
if (nightState != prevNightState) {
  prevNightState = nightState;
  switch (nightState) {
    case NIGHT_DARK:   hvDimmerSetDuty(0);                     break;
    case NIGHT_DIM:    hvDimmerSetDuty(hvDimPct * 255 / 100);  break;
    case NIGHT_NORMAL: hvDimmerSetDuty(255);                   break;
  }
}
```

### 3.3 Neue Konfigurationsvariable

```cpp
uint8_t hvDimPct = 25;   // Dimm-Helligkeit in %, NVS-Key "hvDimPct", Range 5–95
```

Ersetzt die feste `NIGHT_DIM_DUTY_PCT`-Konstante. Wird zusätzlich neu
angewendet, wenn der Slider im Web-UI während `nightState == NIGHT_DIM`
verändert wird (kein Zustandswechsel nötig).

---

## 4. Web-UI (`web_server.ino`)

### 4.1 Karte „🌙 Nacht-Modus“ – neues Element

Neuer Slider zwischen „Modus“-Dropdown und „Lichtsensor aktiv“:

```html
<div class="row"><label>Dimm-Helligkeit</label>
  <input type="range" id="hvDimPct" min="5" max="95" value="25"
    oninput="document.getElementById('hvDimPctVal').textContent=this.value">
  <span id="hvDimPctVal">25</span>%</div>
```

Wird wie die übrigen Nacht-Modus-Felder beim Klick auf „Übernehmen“ per
`saveNightMode()` mitgeschickt.

### 4.2 API-Erweiterung

**`GET /api/nightmode`** – zusätzliches Feld `"hvDimPct": 25`.

**`POST /api/nightmode`** – akzeptiert zusätzlich `hvDimPct` (uint8,
5–95, `constrain()`), persistiert via `prefs.putUChar("hvDimPct", ...)`.

### 4.3 NVS-Keys (Namespace `"nixie"`, Ergänzung zur bestehenden Tabelle)

| Key | Typ | Bedeutung |
|---|---|---|
| `hvDimPct`| uint8 | Röhren-Dimm-Helligkeit in % (5–95)  |

---

## 5. Dateien-Übersicht

| Datei | Änderung |
|---|---|
| `hv_dimmer.ino` | **Neu** – LEDC-Kapselung (`hvDimmerInit()`, `hvDimmerSetDuty()`) |
| `NixieClockUltra.ino`  | `HV_SWITCH_PIN`/`HV_PWM_FREQ_HZ` #defines, `hvDimPct` Global + NVS-Laden, `hvDimmerInit()` in `setup()`, Software-PWM-Block in `loop()` entfernt und durch `hvDimmerSetDuty()`-Aufrufe ersetzt |
| `web_server.ino` | Neuer Slider in Nacht-Modus-Karte, `/api/nightmode` GET+POST um `hvDimPct` erweitert |

---

## 6. Verifikation

Kein Compiler/Hardware-Zugriff in dieser Umgebung verfügbar – die
Implementierung ist code-vollständig, aber ungetestet abzunehmen.
Manueller Testablauf nach Hardware-Aufbau:

1. **Isoliert (ohne HV):** GPIO7-Signal mit Oszilloskop/Logic-Analyzer
   prüfen – 200 Hz, korrekter Duty bei jedem `nightState`-Übergang
   (0 / `hvDimPct` / 255) und bei Slider-Änderung.
2. **TLP627-Stufe separat:** LED-Vorwärtsstrom und sauberes Schalten
   der Anodenspannung am TLP627-Ausgang messen, bevor die Röhren
   dranhängen.
3. **Am fertigen Gerät:** Nacht-Modus-Zeitfenster testweise aktivieren,
   `hvDimPct`-Slider 5–95% durchfahren → sichtbares, flackerfreies
   Dimmen. Dunkel-Modus prüfen → Röhren komplett aus, kein Nachglühen.
4. **Regressionscheck:** `NIGHT_NORMAL` weiterhin volle, stabile
   Helligkeit; Taster/IR-Bedienung unverändert; NeoPixel-Nachtdimmung
   (unverändert im Code) weiterhin korrekt.

---

## 7. Nicht im Scope

- Mehrstufige/stufenlose Röhren-Helligkeit außerhalb des Nacht-Modus
  (der Web-UI-„Nixie-Helligkeit“-Dropdown bleibt wirkungslos für die
  Röhren, wie bisher).
- Änderungen an der NeoPixel-Dimmung.
- Dimensionierung des LED-Vorwiderstands am GPIO7/TLP627 sowie Prüfung
  des Anodenstroms gegen die 120mA-Collector-Current-Grenze – reine
  Hardware-Aufgabe des Users.
- Nicht-blockierendes WiFi-Connect (separates, bereits besprochenes Thema).

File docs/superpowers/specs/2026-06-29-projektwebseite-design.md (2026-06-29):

# Design-Spec: Nixie Clock Ultra – Projektwebseite

**Datum:** 2026-06-29
**Status:** Genehmigt, bereit zur Implementierung

---

## Ziel

Mehrseitige, lokale Projektwebseite für die Nixie Clock Ultra. Technologie: reines
HTML/CSS/JS (statisch, kein Build-Schritt). Steampunk-Ästhetik: dunkel-industriell,
Messing-/Goldakzente, Nixie-Orangeglühen, gravierte Typografie. Später direkt auf
Webserver oder GitHub Pages übertragbar.

---

## Dateistruktur

```
docs/website/
├── index.html            Startseite
├── features.html         Features & Werbetext
├── aufbau.html           Hardware-Aufbau, PCBs, Schematics
├── geschichte.html       Entwicklungshistorie & Problemlösungen
├── dokumentation.html    Downloads (Systemdoku, Anleitung)
├── galerie.html          Fotogalerie
├── css/
│   └── style.css         Globales Stylesheet (Steampunk-Theme)
├── js/
│   ├── nav.js            Gemeinsamer Header + Footer (per JS injiziert)
│   └── lightbox.js       Galerie-Lightbox (Vanilla JS)
├── img/
│   ├── hero.jpg          Hero-Foto Startseite (vom Nutzer bereitgestellt)
│   ├── gallery/          Alle Galeriefotos (vom Nutzer bereitgestellt)
│   └── pcb/              PCB-Bilder (symlink/kopie aus docs/system/assets/)
└── downloads/
    ├── NixieClockUltra-Systemdokumentation.odt
    ├── NixieClockUltra-Systemdokumentation.pdf
    └── NixieClockUltra-Bedienungsanleitung.pdf
```

---

## Design-System

### Farbpalette (CSS Custom Properties)

```css
--bg-base:        #0e0a05   /* Seitenhintergrund, tiefstes Schwarz-Braun */
--bg-panel:       #1c1408   /* Inhalts-Panels, leicht erhöht */
--bg-panel-hover: #241a0a   /* Panel-Hover-Zustand */
--text-primary:   #e8d5a3   /* Haupttext, Pergament-Creme */
--text-muted:     #a08c6a   /* Gedämpfter Text, Beschriftungen */
--accent-gold:    #c8961a   /* Primärakzent, Messing-Gold */
--accent-copper:  #cd7f32   /* Sekundärakzent, Kupfer */
--accent-nixie:   #ff8c00   /* Nixie-Glühen, für Highlights */
--border-dim:     #3a2a10   /* Ruhige Rahmenlinie */
--border-gold:    #6b4f12   /* Goldener Rahmen */
```

### Typografie

- **Überschriften:** Cinzel (Google Fonts) — graviert-klassisch
- **Fließtext:** Crimson Text (Google Fonts) — warm, antiquarisch
- **Code/Technisch:** Liberation Mono / Courier New

### Dekorelemente

- **Zahnrad-Divider:** SVG-Inline-Elemente als horizontale Trennlinien zwischen Sektionen
- **Niet-Ecken:** CSS-Pseudo-Elemente (::before / ::after) an Panel-Ecken als kleine Kreise
- **Nav-Tabs:** Rechteckige Messing-Schilde, aktive Seite gold hinterlegt
- **Download-Buttons:** Geniete Metallplatten-Optik, Hover-Effekt mit Kupfer-Glow

---

## Globales Layout

Jede Seite besteht aus vier Zonen, die `nav.js` per `innerHTML` injiziert:

```
<body>
  <div id="site-header">  ← nav.js injiziert
  <nav id="site-nav">     ← nav.js injiziert, aktive Seite per data-page markiert
  <main id="content">     ← seitenspezifischer Inhalt
  <footer id="site-footer"> ← nav.js injiziert
```

**Header:** Schmales dunkles Band. Links kleines Zahnrad-SVG, mittig
„NIXIE CLOCK ULTRA" in Cinzel 28pt gold, darunter „broed digital media · 2026"
in Crimson Text 11pt gedämpft, rechts spiegelverkehrtes Zahnrad-SVG.

**Navigation:** Horizontale Leiste direkt unter Header. Sechs Tabs:
Startseite · Features · Aufbau · Geschichte · Dokumentation · Galerie.
Aktiver Tab: goldener Hintergrund, schwarzer Text. Hover: Kupfer-Glow.
Auf Mobilgeräten (< 768px): Hamburger-Icon, aufklappbares Dropdown.

**Content-Bereich:** max-width 1100px, zentriert, padding 2rem.

**Footer:** Schmale dunkle Leiste. Oben ein Niet-Separator (horizontale Linie
mit kleinen Kreisen). Text: „© 2026 broed digital media · Nixie Clock Ultra".

---

## Seiten im Detail

### 1. Startseite (`index.html`)

**Hero-Sektion (volle Viewport-Breite):**
- Hintergrundbild: `img/hero.jpg`, `object-fit: cover`, Höhe 70vh
- Dunkles Overlay: `rgba(0,0,0,0.55)` gradient
- Darüber zentriert:
  - „NIXIE CLOCK ULTRA" — Cinzel 52pt, gold
  - „wenn Zeit leuchtet" — Crimson Text 18pt, italic, kupfer
  - „→ Mehr erfahren"-Button (Link auf features.html)

**Highlight-Kacheln (3 Stück, Flex-Row):**
Unter dem Hero, jede Kachel: dunkles Panel, goldene Überschrift, ein Satz Text.
Inhalte: „Direct Drive — kein Ghosting", „WiFi & Web-Interface",
„Nacht-Modus & Lichtsensor".

**Teaser-Text:**
Erster Absatz aus Werbetext (`NixieClockUltra-Werbetext.odt`), max 250 Wörter.
Abschluss: Link „Alle Features →" zu features.html.

---

### 2. Features (`features.html`)

**Seitentitel:** „Features" in Cinzel h1, Zahnrad-Divider darunter.

**Fließtext-Block:** Vollständiger Werbetext (alle fünf Absätze).

**Feature-Gruppen:** Fünf dunkle Panels untereinander:
- Anzeige · Beleuchtung · Konnektivität & Bedienung · Nacht-Modus · Technik
- Jedes Panel: goldene Gruppenüberschrift (h3), Bullet-Liste mit „›"-Bullet in
  Nixie-Orange, Text in Crimson Text.

---

### 3. Aufbau (`aufbau.html`)

**Seitentitel:** „Aufbau & Hardware"

**Abschnitt Logic Board:**
Zweispaltig (auf Mobile einspaltig): links `img/pcb/logic_sch-1.png` +
`img/pcb/logic_pcb-1.png` als klickbare Thumbnails (öffnen Lightbox),
rechts Text: Rev 2.1, Komponenten-Highlights (ESP32-S3, DC-DC, HV-MOD, LDR),
USB-CDC-Warnung als farbige Hinweisbox.

**Abschnitt Nixie Display Board:**
Gleiche Zweispalten-Struktur mit `nixie_sch-1.png` + `nixie_pcb-1.png`,
Text: MCP23017 Direct Drive, 60 SMBTA42-Transistoren, kein Ghosting.

**Abschnitt Spannungsversorgung:**
SVG-Flussdiagramm: USB 5V → DC-DC (U6) → 10V → HV-MOD (U4) → 170V (Nixie-Anoden)
                    USB 5V → AMS1117 (U5) → 3,3V (Logik)
Goldene Pfeile, dunkle Beschriftungsboxen.

---

### 4. Geschichte (`geschichte.html`)

**Seitentitel:** „Entwicklungsgeschichte"

**Timeline-Layout:**
Vertikale goldene Linie mittig (auf Desktop links-mittig), Messing-Punkte als
Meilenstein-Marker. Jeder Eintrag: Datum in Nixie-Orange, Titel in Cinzel,
Kurztext in Crimson Text. Basis: Inhalt aus `docs/ENTWICKLUNGSHISTORIE.md`,
manuell als HTML aufbereitet.

**Probleme & Lösungen:**
CSS-only Akkordeon (checkbox-hack): Überschrift mit „▶"-Pfeil, Klick klappt
Lösungstext auf. Keine JS-Abhängigkeit.

---

### 5. Dokumentation (`dokumentation.html`)

**Seitentitel:** „Dokumentation & Downloads"

**Zwei Download-Karten** (Flex-Row, auf Mobile gestapelt):

*Karte 1 — Systemdokumentation:*
Icon (Zahnrad-SVG), Titel, Kurztext (2 Sätze), zwei Buttons:
„ODT herunterladen" + „PDF herunterladen" → `downloads/`

*Karte 2 — Bedienungsanleitung:*
Icon (Buch-SVG), Titel, Kurztext (2 Sätze), Button:
„PDF herunterladen" → `downloads/`

**Hinweis-Box:** „ODT-Dateien können mit LibreOffice geöffnet werden."

---

### 6. Galerie (`galerie.html`)

**Seitentitel:** „Galerie"

**Masonry-Grid:** CSS columns (3 Spalten Desktop, 2 Tablet, 1 Mobile).
Jedes Bild: dunkler Rahmen 3px `--border-gold`, leichter Box-Shadow,
Hover: leicht aufhellen + Kupfer-Glow.

**Lightbox (`lightbox.js`):**
- Klick auf Bild → Overlay mit schwarzem Hintergrund, Bild zentriert, max 90vw/90vh
- Navigation: Pfeil links/rechts (Tastatur + Klick)
- Schließen: Klick außerhalb oder ESC-Taste
- Kein externes Framework, ~60 Zeilen JS

---

## Responsive Breakpoints

| Breakpoint | Verhalten |
|---|---|
| > 1100px  | Volle Breite, max-width 1100px zentriert |
| 768–1100px | Zweispalten-Layouts bleiben, kleinere Schrift |
| < 768px | Alles einspaltig, Hamburger-Nav, Hero 50vh |

---

## Assets die vom Nutzer bereitgestellt werden

- `img/hero.jpg` — Hauptfoto der fertigen Uhr (für Hero-Sektion)
- `img/gallery/*.jpg` — Alle Galeriefotos

PCB-Bilder werden aus `docs/system/assets/` in `img/pcb/` kopiert.
Downloads werden aus bestehenden Docs-Ordnern in `downloads/` kopiert.

---

## Nicht im Scope

- Kein Server-Side-Rendering
- Kein CMS
- Kein CSS-Framework (Bootstrap, Tailwind etc.)
- Kein TypeScript / Build-Tool
- Keine Suchfunktion
- Keine Mehrsprachigkeit

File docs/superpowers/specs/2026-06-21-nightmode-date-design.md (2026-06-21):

# NixieClockUltra – Nacht-Modus & Datum-Anzeige

**Datum:** 2026-06-21  
**Status:** Genehmigt

---

## Überblick

Zwei unabhängige Erweiterungen, die zusammen implementiert werden:

1. **Nacht-Modus** – Nixie-Röhren und NeoPixel gedimmt oder abgeschaltet, ausgelöst durch Zeitfenster und/oder LDR-Sensor.
2. **Datum-Anzeige** – DS1302 liefert volles Datum; Anzeige für 5 Sekunden nach jeder Slot-Animation; editierbar per Taster und Web-UI.

---

## 1. Nacht-Modus

### 1.1 Zustände

```
enum NightState { NIGHT_NORMAL, NIGHT_DIM, NIGHT_DARK };
NightState nightState = NIGHT_NORMAL;
```

### 1.2 Trigger-Logik (Priorität: Zeitbereich > LDR)

**Zeitbereich** (konfigurierbar via Web-UI):
- `nightTimeEnabled` (bool)
- `nightStart`, `nightEnd` (uint8_t, 0–23)
- `nightTimeMode` (uint8_t, 0 = DIM, 1 = DARK)
- Mitternacht-Übergang wird unterstützt: `nightStart > nightEnd` → Bereich gilt wenn `h >= nightStart || h < nightEnd`

**LDR-Sensor** (nur DIM, nie DARK):
- `ldrEnabled` (bool)
- `ldrThreshold` (uint16_t, 0–4095; höherer Wert = Dimmen bei hellerer Umgebung)
- Pin: GPIO 6 (ADC1-Channel 5, funktioniert mit WiFi)
- Abtastung alle 500 ms, 4 ADC-Samples gemittelt
- ADC-Wert ≤ ldrThreshold → Dimmen (niedriger ADC-Wert = dunkle Umgebung, LDR hochohmig, Spannung am Pin sinkt)

**Priorität:**
```
if (nightTimeEnabled && timeInRange(curHour))
    nightState = (nightTimeMode == 1) ? NIGHT_DARK : NIGHT_DIM;
else if (ldrEnabled && ldrReading <= ldrThreshold)
    nightState = NIGHT_DIM;
else
    nightState = NIGHT_NORMAL;
```

### 1.3 Nixie-Dimming (Software-PWM)

Definiert in `NixieClockUltra.ino`:

```cpp
#define NIGHT_DIM_DUTY_PCT    25   // Nixie Ein-Anteil in % (~25 % Helligkeit)
#define NIGHT_DIM_PWM_PERIOD  20   // PWM-Periode in ms (= 50 Hz)
#define NIGHT_DIM_NEO_PCT     15   // NeoPixel-Helligkeit im Dimm-Modus in % der Normalhelligkeit
```

PWM-Gate in `loop()` (nur aktiv wenn `nightState == NIGHT_DIM`):
- `nixiePwmOn` toggled via `millis()`-Vergleich
- Toggle-Zeitpunkte: `lastPwmToggle + (nixiePwmOn ? onTime : offTime)`
  - `onTime  = NIGHT_DIM_PWM_PERIOD * NIGHT_DIM_DUTY_PCT / 100`
  - `offTime = NIGHT_DIM_PWM_PERIOD - onTime`
- Bei Toggle → `nixieWrite(displayDigits)` oder `nixieWrite(blank[6]={10,…})`

Bei `NIGHT_DARK`: einmalig `nixieWrite(blank)` beim Zustandswechsel.

### 1.4 NeoPixel-Dimming

In `updateNeoPixel()` vor der Pixel-Berechnung temporäre Skalierung (kein NVS-Schreiben):
- `NIGHT_NORMAL`: `neoBright` / `colonBright` unverändert
- `NIGHT_DIM`:    `neoBright * NIGHT_DIM_NEO_PCT / 100`, `colonBright * NIGHT_DIM_NEO_PCT / 100`
- `NIGHT_DARK`:   `neoBright = 0`, `colonBright = 0` (lokal, Original bleibt erhalten)

### 1.5 Neue Datei: `night_mode.ino`

Enthält:
- Globale Variablen (Konfiguration + Zustand)
- `updateNightMode()` – wird in `loop()` aufgerufen

### 1.6 NVS-Keys (Namespace `"nixie"`)

| Key | Typ | Bedeutung |
|---|---|---|
| `ntEn` | bool | Zeitbereich aktiv |
| `ntFrom` | uint8 | Startzeit (Stunde) |
| `ntTo` | uint8 | Endzeit (Stunde) |
| `ntMode` | uint8 | 0 = DIM, 1 = DARK |
| `ldrEn`  | bool | LDR aktiv |
| `ldrThr` | uint16  | ADC-Schwellwert (0–4095) |

### 1.7 Web-UI – Neue Karte „🌙 Nacht-Modus"

Position: zwischen Slot-Animation und IR-Fernbedienung.

Elemente:
- Toggle: Zeitbereich aktiv
- Zahlenfeld: Von (0–23), Bis (0–23)
- Dropdown: Modus (Gedimmt / Dunkel)
- Toggle: LDR-Sensor aktiv
- Slider: Schwellwert (0–4095; 0 = nur bei Totaldunkel dimmen, 4095 = immer gedimmt)
- Badge: aktueller Zustand (Normal / Gedimmt / Dunkel) – aus `/api/status`

### 1.8 Neue API-Endpunkte

**`GET /api/nightmode`** – liefert alle Nacht-Modus-Parameter.

**`POST /api/nightmode`** – setzt Parameter:
```json
{ "ntEn": true, "ntFrom": 23, "ntTo": 7, "ntMode": 1,
  "ldrEn": true, "ldrThr": 512 }
```

**`GET /api/status`** – erhält zusätzlich `"nightState": 0/1/2`.

---

## 2. Datum-Anzeige

### 2.1 Neue globale Variablen

```cpp
uint8_t curDay = 1, curMonth = 1, curYear = 24;  // Jahr zweistellig (00–99)
```

### 2.2 RTC-Anpassungen (`rtc.ino`)

**`readRTC()`**: liest zusätzlich `Day()`, `Month()`, `Year() % 100`.

**`writeRTC()`**: ersetzt hardcodierten `2024-1-1` durch `curDay`, `curMonth`, `curYear + 2000`.

### 2.3 Datum-Anzeige-Funktion (`display.ino`)

```cpp
void setDisplayDate() {
    displayDigits[0] = curDay   / 10;
    displayDigits[1] = curDay   % 10;
    displayDigits[2] = curMonth / 10;
    displayDigits[3] = curMonth % 10;
    displayDigits[4] = curYear  / 10;
    displayDigits[5] = curYear  % 10;
    nixieWrite(displayDigits);
}
```

Format: **TT MM JJ** (Tag-Monat-Jahr zweistellig), von links nach rechts.

### 2.4 Datum-Anzeige nach Slot-Animation

Neue Variablen in `NixieClockUltra.ino`:
```cpp
bool     dateShowActive = false;
uint32_t dateShowStart  = 0;
#define  DATE_SHOW_MS   5000
```

Ablauf in `loop()`:
- Wenn `slotActive` → false wechselt: `dateShowActive = true; dateShowStart = millis();`
- Solange `dateShowActive && millis() - dateShowStart < DATE_SHOW_MS`: `setDisplayDate()` aufrufen (alle 500 ms, synchron mit RTC-Read-Takt)
- Danach: `dateShowActive = false` → zurück zur Uhrzeitanzeige

`dateShowActive` verhindert gleichzeitig, dass ein neuer Slot oder RTC-Update das Display überschreibt.

### 2.5 Taster-Editiermodus – Erweiterung

```cpp
enum EditState {
    EDIT_NONE,
    EDIT_HOUR, EDIT_MIN, EDIT_SEC,
    EDIT_DAY, EDIT_MONTH, EDIT_YEAR
};
```

Erweiterte Sequenz:
```
SET → Stunde → SET → Minute → SET → Sekunde →
SET → Tag    → SET → Monat  → SET → Jahr    → SET (speichern)
```

- Tag: 1–31, Monat: 1–12, Jahr: 0–99 (zweistellig)
- Blinken der aktiven Stelle wie bei Uhrzeit (Röhrenpaar blinkt aus)
- `writeRTC()` wird erst beim letzten SET aufgerufen

### 2.6 Web-UI – Erweiterung der Zeit-Karte

Karte umbenannt: **„⏱ Zeit & Datum stellen"**

Neue Felder:
- Tag (1–31), Monat (1–12), Jahr (0–99)

„Browser-Zeit"-Button synchronisiert zusätzlich `new Date().getDate()`, `.getMonth()+1`, `.getFullYear() % 100`.

**`POST /api/settime`** – erweitert um optionale Felder `d`, `mo`, `y` (rückwärtskompatibel; wenn nicht übergeben bleibt das Datum unverändert).

**`GET /api/status`** – erhält zusätzlich `"date": "TT.MM.JJ"`.

### 2.7 NTP-Sync

Bereits korrekt: `RtcDateTime ntpTime(year, month, day, ...)` setzt volles Datum. Nach dem Sync liest `readRTC()` das Datum zurück (sobald es date-fähig ist).

---

## 3. Dateien-Übersicht

| Datei | Änderung |
|---|---|
| `NixieClockUltra.ino`  | Neue Globals, #defines, NVS-Ladevorgänge, Loop-Erweiterungen |
| `night_mode.ino` | **Neu** – Night-Mode-Logik, LDR-Abtastung, `updateNightMode()`  |
| `rtc.ino` | `readRTC()` + `writeRTC()` mit Datum |
| `display.ino` | `setDisplayDate()`, dateShowActive-Logik |
| `buttons.ino` | EditState um EDIT_DAY/MONTH/YEAR erweitert |
| `neo_animation.ino` | Temporäre Helligkeitsskalierung per NightState |
| `web_server.ino` | Neue Karte, neue API-Endpunkte, Status-Erweiterungen |

---

## 4. Nicht im Scope

- Wochentag-Anzeige
- Sommerzeit-Umschaltung (läuft bereits über NTP_TZ)
- Alarm-Funktion
- Hardware-PWM für Nixie (kann später als Option B nachgerüstet werden)

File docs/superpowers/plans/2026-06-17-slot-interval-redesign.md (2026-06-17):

# Slot-Machine Intervall & Animationstrennung — Implementierungsplan

> **For agentic workers:** REQUIRED SUB-SKILL: Use superpowers:subagent-driven-development (recommended) or superpowers:executing-plans to implement this plan task-by-task. Steps use checkbox (`- [ ]`) syntax for tracking.

**Goal:** `ANIM_SLOTS` aus dem Animationsmodus entfernen, Slot-Machine-Intervall als eigenständige Einstellung (Aus/10Sek/1Min/15Min/1Std) einführen, colonBright-Default von 15 auf 80 anheben.

**Architecture:** `SlotInterval`-Enum als neue globale Variable neben `animMode`. NeoPixel-Slot-Effekt als Override-Schicht nach dem Animations-Switch. Web-UI bekommt ein separates Intervall-Dropdown in der Slot-Karte.

**Tech Stack:** Arduino/ESP32-S3, Adafruit NeoPixel, ESPAsyncWebServer, ArduinoJson, Preferences (NVS)

**Compile-Befehl:** Arduino IDE → Sketch → Verify/Compile (Strg+R). Kein Unit-Test-Framework verfügbar; Verifikation erfolgt durch Compile-Check + Hardware-Test nach dem Flashen.

---

## Betroffene Dateien

| Datei | Was ändert sich |
|---|---|
| `NixieClockUltra.ino` | `AnimMode` kürzen, `SlotInterval` enum + Variable, NVS-Laden, Loop-Trigger, colonBright-Default |
| `neo_animation.ino` | `ANIM_SLOTS` case entfernen, Slot-Override-Block hinzufügen |
| `web_server.ino` | HTML: Slot-Card + Animation-Select; C++: `/api/status`, neuer `/api/slotinterval` Endpoint; JS: `setSlotInterval()`, `refreshClock()` |

---

## Task 1: Datenmodell & Loop-Logik (NixieClockUltra.ino)

**Files:**
- Modify: `NixieClockUltra.ino`

- [ ] **Schritt 1: AnimMode kürzen**

Zeile 121 — `ANIM_SLOTS` entfernen:

```cpp
// ALT:
enum AnimMode { ANIM_RAINBOW, ANIM_STATIC, ANIM_PULSE, ANIM_SLOTS, ANIM_COUNT };

// NEU:
enum AnimMode { ANIM_RAINBOW, ANIM_STATIC, ANIM_PULSE, ANIM_COUNT };
```

- [ ] **Schritt 2: SlotInterval-Enum und Variable einfügen**

Direkt nach der `AnimMode`-Zeile (nach Zeile 122) einfügen:

```cpp
enum SlotInterval { SLOT_OFF, SLOT_10S, SLOT_1MIN, SLOT_15MIN, SLOT_1HR };
SlotInterval slotInterval = SLOT_OFF;
```

- [ ] **Schritt 3: NVS-Laden in setup() anpassen**

Zeile 240 — `animMode`-Laden ersetzen und `slotInterval` + Migration hinzufügen:

```cpp
// ALT:
animMode    = (AnimMode)prefs.getUChar("animMode", 0);

// NEU:
uint8_t savedAnim = prefs.getUChar("animMode", 0);
animMode     = (savedAnim < (uint8_t)ANIM_COUNT) ? (AnimMode)savedAnim : ANIM_RAINBOW;
slotInterval = (SlotInterval)prefs.getUChar("slotIval", 0);
```

- [ ] **Schritt 4: colonBright-Default anheben**

Zeile 239 — Default von 15 auf 80:

```cpp
// ALT:
colonBright = prefs.getUChar("colonBright", 15);

// NEU:
colonBright = prefs.getUChar("colonBright", 80);
```

- [ ] **Schritt 5: Loop-Trigger ersetzen**

Zeilen 325–330 — alten Slot-Trigger ersetzen:

```cpp
// ALT:
if (animMode == ANIM_SLOTS && curSec % 10 == 0) {
  // Alle 10 Sekunden Slot-Animation
  startSlotAnimation(curHour, curMin, curSec);
} else if (!slotActive) {
  setDisplayTime(curHour, curMin, curSec);
}

// NEU:
bool triggerSlot = false;
switch (slotInterval) {
  case SLOT_10S:   triggerSlot = (curSec % 10 == 0); break;
  case SLOT_1MIN:  triggerSlot = (curSec == 0); break;
  case SLOT_15MIN: triggerSlot = (curSec == 0 && curMin % 15 == 0); break;
  case SLOT_1HR:   triggerSlot = (curSec == 0 && curMin == 0); break;
  default: break;
}
if (triggerSlot && !slotActive) startSlotAnimation(curHour, curMin, curSec);
else if (!slotActive) setDisplayTime(curHour, curMin, curSec);
```

- [ ] **Schritt 6: Compile-Check**

Arduino IDE → Strg+R. Erwartetes Ergebnis: keine Fehler, keine Warnings zu `ANIM_SLOTS`.

- [ ] **Schritt 7: Commit**

```bash
git add NixieClockUltra.ino
git commit -m "feat: SlotInterval enum, AnimMode ohne ANIM_SLOTS, colonBright-Default 80"
```

---

## Task 2: NeoPixel-Override-Schicht (neo_animation.ino)

**Files:**
- Modify: `neo_animation.ino`

- [ ] **Schritt 1: ANIM_SLOTS case entfernen**

Den gesamten `case ANIM_SLOTS:` Block (Zeilen 66–84) löschen:

```cpp
// ENTFERNEN — komplett löschen:
    case ANIM_SLOTS: {
      if (slotActive) {
        uint32_t col = strip.ColorHSV((millis() / 5) % 65536, 255, 255);
        for (int i = 0; i < 6; i++) strip.setPixelColor(i, scaleColor(col, neoBright));
        for (int i = 6; i < 10; i++) strip.setPixelColor(i, rgbSwap(scaleColor(col, colonBright)));
      } else {
        for (int i = 0; i < 6; i++) {
          uint8_t hue = neoHue + i * 40;
          strip.setPixelColor(i, scaleColor(strip.ColorHSV(hue * 256, neoSat, 255), neoBright));
        }
        neoHue++;
        bool colonOn = colonAlwaysOn || (curSec % 2 == 0);
        uint32_t colonColor = colonOn
          ? strip.ColorHSV((neoHue + 128) * 256, 200, 255)
          : strip.Color(0, 0, 0);
        for (int i = 6; i < 10; i++) strip.setPixelColor(i, rgbSwap(scaleColor(colonColor, colonBright)));
      }
      break;
    }
```

- [ ] **Schritt 2: Slot-Override-Block einfügen**

Nach dem `switch`-Block, direkt vor dem `colonStatic`-Block (vor Zeile 89) einfügen:

```cpp
  // Slot-Effekt überschreibt Hintergrundanimation solange slotActive
  if (slotActive) {
    uint32_t col = strip.ColorHSV((millis() / 5) % 65536, 255, 255);
    for (int i = 0; i < 6;  i++) strip.setPixelColor(i, scaleColor(col, neoBright));
    for (int i = 6; i < 10; i++) strip.setPixelColor(i, rgbSwap(scaleColor(col, colonBright)));
  }
```

Die Datei soll danach so aussehen (Struktur nach dem switch):

```cpp
    default: break;
  }

  // Slot-Effekt überschreibt Hintergrundanimation solange slotActive
  if (slotActive) {
    uint32_t col = strip.ColorHSV((millis() / 5) % 65536, 255, 255);
    for (int i = 0; i < 6;  i++) strip.setPixelColor(i, scaleColor(col, neoBright));
    for (int i = 6; i < 10; i++) strip.setPixelColor(i, rgbSwap(scaleColor(col, colonBright)));
  }

  // Statischer Modus: Trennpunkte unabhängig von Animation warmweiß überschreiben
  if (colonStatic) {
```

- [ ] **Schritt 3: Compile-Check**

Arduino IDE → Strg+R. Erwartetes Ergebnis: keine Fehler.

- [ ] **Schritt 4: Commit**

```bash
git add neo_animation.ino
git commit -m "feat: Slot-Effekt als Override-Schicht, ANIM_SLOTS case entfernt"
```

---

## Task 3: Web UI — HTML & JavaScript (web_server.ino)

**Files:**
- Modify: `web_server.ino` (PROGMEM-String und Script-Block)

- [ ] **Schritt 1: "Slot-Machine"-Option aus Animations-Select entfernen**

Im PROGMEM-HTML-String die Zeile mit `value="3"` löschen:

```html
<!-- ENTFERNEN: -->
      <option value="3">Slot-Machine</option>
```

Der Select soll danach so aussehen:

```html
    <select id="anim" onchange="setAnim()">
      <option value="0">Rainbow</option>
      <option value="1">Statisch Warmweiß</option>
      <option value="2">Puls</option>
    </select>
```

- [ ] **Schritt 2: Slot-Karte um Intervall-Dropdown erweitern**

Den bisherigen Slot-Card-Block:

```html
<div class="card">
  <h2>🎰 Slot-Animation starten</h2>
  <div class="row">
    <button onclick="triggerSlot()">Slot-Machine!</button>
    <span class="badge" id="slotStatus">bereit</span>
  </div>
</div>
```

ersetzen durch:

```html
<div class="card">
  <h2>🎰 Slot-Animation</h2>
  <div class="row">
    <label>Automatisch</label>
    <select id="slotIval" onchange="setSlotInterval()">
      <option value="0">Aus</option>
      <option value="1">10 Sek</option>
      <option value="2">1 Min</option>
      <option value="3">15 Min</option>
      <option value="4">1 Std</option>
    </select>
  </div>
  <div class="row">
    <button onclick="triggerSlot()">Slot-Machine!</button>
    <span class="badge" id="slotStatus">bereit</span>
  </div>
</div>
```

- [ ] **Schritt 3: refreshClock() erweitern**

In `refreshClock()` nach der Zeile `if(d.anim!==undefined)...` einfügen:

```js
  if(d.slotIval!==undefined) document.getElementById('slotIval').value=d.slotIval;
```

Die Funktion soll danach so aussehen (relevanter Ausschnitt):

```js
  if(d.anim!==undefined) document.getElementById('anim').value=d.anim;
  if(d.slotIval!==undefined) document.getElementById('slotIval').value=d.slotIval;
  if(d.colonOn!==undefined)document.getElementById('colonOn').checked=d.colonOn;
```

- [ ] **Schritt 4: setSlotInterval()-Funktion hinzufügen**

Nach der `setAnim()`-Funktion einfügen:

```js
async function setSlotInterval(){
  let v=parseInt(document.getElementById('slotIval').value);
  await api('/api/slotinterval',{interval:v});
}
```

- [ ] **Schritt 5: Compile-Check**

Arduino IDE → Strg+R. Erwartetes Ergebnis: keine Fehler.

- [ ] **Schritt 6: Commit**

```bash
git add web_server.ino
git commit -m "feat: Web-UI Slot-Intervall-Dropdown, Animation-Select ohne Slot-Option"
```

---

## Task 4: Web API (web_server.ino — C++ setupWebServer)

**Files:**
- Modify: `web_server.ino` (C++-Teil, `setupWebServer()`-Funktion)

- [ ] **Schritt 1: slotIval zu /api/status hinzufügen**

Im `/api/status`-Handler nach `doc["slot"] = slotActive;` einfügen:

```cpp
doc["slotIval"] = (int)slotInterval;
```

Der Block soll danach so aussehen:

```cpp
doc["bright"]    = brightLevel;
doc["neoBright"] = neoBright;
doc["anim"]      = (int)animMode;
doc["slot"]      = slotActive;
doc["slotIval"]  = (int)slotInterval;
doc["colonOn"]     = colonAlwaysOn;
```

Hinweis: `StaticJsonDocument<256>` reicht für das eine zusätzliche Feld.

- [ ] **Schritt 2: /api/slotinterval Endpoint hinzufügen**

Nach dem `/api/slot`-Handler (nach Zeile ~406) einfügen:

```cpp
  server.on("/api/slotinterval", HTTP_POST, [](AsyncWebServerRequest *req){},
    nullptr,
    [](AsyncWebServerRequest *req, uint8_t *data, size_t len, size_t, size_t) {
      StaticJsonDocument<64> doc;
      if (!deserializeJson(doc, data, len)) {
        int v = constrain((int)doc["interval"], 0, 4);
        slotInterval = (SlotInterval)v;
        prefs.putUChar("slotIval", v);
        req->send(200, "application/json", "{\"ok\":true}");
      } else {
        req->send(400, "application/json", "{\"ok\":false}");
      }
    }
  );
```

- [ ] **Schritt 3: Compile-Check**

Arduino IDE → Strg+R. Erwartetes Ergebnis: keine Fehler, keine Warnungen.

- [ ] **Schritt 4: Commit**

```bash
git add web_server.ino
git commit -m "feat: /api/slotinterval Endpoint, slotIval in /api/status"
```

---

## Task 5: Flash & Hardware-Verifikation

**Files:** keine Codeänderungen

- [ ] **Schritt 1: Flashen**

Arduino IDE → Strg+U (Upload). ESP32-S3 ggf. vorher in Download-Mode: BOOT gedrückt halten → RST drücken → BOOT loslassen.

- [ ] **Schritt 2: Animationsmodi prüfen**

Web-UI öffnen (`192.168.4.1`). Im Dropdown "Animation" darf "Slot-Machine" nicht mehr erscheinen. Alle drei Modi (Rainbow, Statisch Warmweiß, Puls) umschalten — jeder muss funktionieren.

- [ ] **Schritt 3: Slot-Intervall 10 Sek testen**

Intervall auf "10 Sek" setzen. Nach spätestens 10 Sekunden muss die Slot-Animation automatisch starten. Während der Animation soll der Regenbogen-Flash-Effekt auf den Hintergrund-Pixeln laufen.

- [ ] **Schritt 4: Manuellen Slot-Button testen**

Intervall auf "Aus" setzen. Den "Slot-Machine!"-Button drücken — Animation muss sofort starten.

- [ ] **Schritt 5: NVS-Persistenz prüfen**

Intervall auf "1 Min" setzen, ESP32-S3 per RST neu starten. Web-UI öffnen — Dropdown muss noch "1 Min" zeigen.

- [ ] **Schritt 6: Hintergrundanimation während Slot prüfen**

Animation auf "Puls" setzen, dann Slot-Button drücken. Während der Röhren-Animation soll der Regenbogen-Flash erscheinen (Hintergrundanimation wird überschrieben). Nach Ende der Slot-Animation soll Puls wieder laufen.

- [ ] **Schritt 7: Abschluss-Commit (falls keine Fixes nötig)**

```bash
git tag v$(date +%Y%m%d)-slot-interval
```

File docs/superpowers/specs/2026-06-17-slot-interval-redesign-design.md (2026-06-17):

# Design: Slot-Machine Intervall & Animationstrennung

**Datum:** 2026-06-17  
**Status:** Genehmigt

## Zusammenfassung

Drei Änderungen in einem Schritt:

1. `ANIM_SLOTS` wird aus dem Animationsmodus-Enum entfernt — Hintergrundbeleuchtung und Slot-Machine sind konzeptuell getrennte Einstellungen.
2. Ein neues `SlotInterval`-Enum ersetzt die hart kodierte 10-Sekunden-Logik mit fünf wählbaren Stufen (Aus / 10 Sek / 1 Min / 15 Min / 1 Std).
3. `colonBright`-Default wird von 15 auf 80 angehoben (war kaum sichtbar).

## Datenmodell

### AnimMode (NixieClockUltra.ino)

```cpp
enum AnimMode { ANIM_RAINBOW, ANIM_STATIC, ANIM_PULSE, ANIM_COUNT };
```

`ANIM_SLOTS` (Wert 3) entfällt. `ANIM_COUNT` ist jetzt 3.  
**Migration:** Beim Laden aus NVS — falls gespeicherter Wert `>= ANIM_COUNT`, wird er auf 0 (RAINBOW) zurückgesetzt.

### SlotInterval (NixieClockUltra.ino)

```cpp
enum SlotInterval { SLOT_OFF, SLOT_10S, SLOT_1MIN, SLOT_15MIN, SLOT_1HR };
SlotInterval slotInterval = SLOT_OFF;
```

NVS-Key: `"slotIval"` (uint8_t, Default 0 = OFF).

### colonBright-Default

```cpp
colonBright = prefs.getUChar("colonBright", 80);  // war: 15
```

## Loop-Trigger-Logik (NixieClockUltra.ino)

Ersetzt den bisherigen `if (animMode == ANIM_SLOTS && curSec % 10 == 0)` Block:

```cpp
bool triggerSlot = false;
switch (slotInterval) {
  case SLOT_10S:   triggerSlot = (curSec % 10 == 0); break;
  case SLOT_1MIN:  triggerSlot = (curSec == 0); break;
  case SLOT_15MIN: triggerSlot = (curSec == 0 && curMin % 15 == 0); break;
  case SLOT_1HR:   triggerSlot = (curSec == 0 && curMin == 0); break;
  default: break;
}
if (triggerSlot && !slotActive) startSlotAnimation(curHour, curMin, curSec);
```

`!slotActive` verhindert Neustart einer laufenden Animation bei mehrfachem RTC-Read in derselben Sekunde.

## NeoPixel-Animation (neo_animation.ino)

`case ANIM_SLOTS` wird vollständig entfernt.

Nach dem `switch`-Block, vor `colonStatic`-Override, neuer Slot-Effekt-Block:

```cpp
// Slot-Effekt überschreibt Hintergrundanimation solange slotActive
if (slotActive) {
  uint32_t col = strip.ColorHSV((millis() / 5) % 65536, 255, 255);
  for (int i = 0; i < 6;  i++) strip.setPixelColor(i, scaleColor(col, neoBright));
  for (int i = 6; i < 10; i++) strip.setPixelColor(i, rgbSwap(scaleColor(col, colonBright)));
}
```

Der Regenbogen-Flash-Effekt während der Slot-Animation bleibt damit erhalten und funktioniert mit jedem Hintergrundmodus.

## Web UI (web_server.ino)

### Animations-Select

Option "Slot-Machine" (value=3) wird entfernt. Nur noch:
- 0 = Rainbow
- 1 = Statisch Warmweiß
- 2 = Puls

### Karte "Slot-Animation"

Neue Zeile mit Intervall-Dropdown (oberhalb des manuellen Buttons):

```html
<div class="row">
  <label>Automatisch</label>
  <select id="slotIval" onchange="setSlotInterval()">
    <option value="0">Aus</option>
    <option value="1">10 Sek</option>
    <option value="2">1 Min</option>
    <option value="3">15 Min</option>
    <option value="4">1 Std</option>
  </select>
</div>
```

### API

**Neuer Endpoint** `POST /api/slotinterval` mit Body `{interval: 0–4}`:
- Setzt `slotInterval`, speichert in NVS als `"slotIval"`.

**Erweiterung** `GET /api/status`:
- Liefert zusätzlich `"slotIval": <0–4>`.

**`refreshClock()`** liest `d.slotIval` und setzt `document.getElementById('slotIval').value`.

### JavaScript

```js
async function setSlotInterval() {
  let v = parseInt(document.getElementById('slotIval').value);
  await api('/api/slotinterval', {interval: v});
}
```

## Trennpunkt-Bug

Die Trennpunkt-Pixel (6–9) reagieren nicht auf Software-Einstellungen — auch nicht bei maximaler Helligkeit und aktivem `colonStatic`. Das deutet auf einen Hardware-Fehler hin (THT WS2812 vermutlich falsch herum eingelötet: VCC↔GND oder DIN↔DOUT vertauscht). Die Software-seitige Anhebung des Defaults auf 80 verbessert die Sichtbarkeit nach der Hardware-Korrektur.

## Betroffene Dateien

| Datei | Änderungen |
|---|---|
| `NixieClockUltra.ino` | `AnimMode` kürzen, `SlotInterval` enum + Variable, NVS-Laden/-Speichern, Loop-Trigger-Logik, colonBright-Default |
| `neo_animation.ino` | `ANIM_SLOTS` case entfernen, Slot-Override-Block hinzufügen |
| `web_server.ino` | HTML (Select + Dropdown), `/api/status` Response, neuer `/api/slotinterval` Endpoint, JS `setSlotInterval()` + `refreshClock()` |

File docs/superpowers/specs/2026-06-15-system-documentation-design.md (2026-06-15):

# Design-Spec: Systemdokumentation Nixie Clock Ultra

**Datum:** 2026-06-15
**Status:** Freigegeben

---

## Ziel

Technische Systemdokumentation für Entwickler und Dritte, die das System verstehen
oder weiterentwickeln möchten. Kein Nachbau-Guide, keine BOM, keine Fertigungsinfos.

---

## Format

- Drei Markdown-Dateien unter `docs/system/`
- Diagramme als Mermaid-Blöcke (GitHub-rendert sie automatisch)
- Tabellen für alle tabellarischen Daten (Pins, APIs, Komponenten)
- Sprache: Deutsch

---

## Dateistruktur

```
docs/system/
├── README.md      ← Einstieg, Systemübersicht, Blockschaltbild
├── hardware.md    ← PCB-Beschreibungen, Inter-Board-Verbindungen, Pin-Belegung
└── firmware.md    ← Firmware-Module, Ablauf, State, API, Persistenz
```

Das bestehende `blockschaltbild.md` im Repo-Root wird durch einen Redirect-Hinweis
auf `docs/system/README.md` ersetzt (nicht gelöscht, um Git-History zu erhalten).

---

## Datei 1: `docs/system/README.md`

### Abschnitte

#### 1.1 Systembeschreibung (3–5 Sätze)
Kurze Einführung: ESP32-S3-basierte Nixie-Röhrenuhr, Zweiplatinendesign,
direkte Ansteuerung via MCP23017, WiFi + Web-UI, IR-Fernbedienung.

#### 1.2 Zweiplatinenübersicht (Tabelle)

| Platine | KiCAD-Projekt | Funktion |
|---|---|---|
| Logic Board | nixieclocklogic_V2 | ESP32-S3, RTC, HV-Modul, Taster, IR, USB |
| Nixie Display Board | nixieclockin12_V2 | 4× MCP23017, 6× IN-12A, 60× NPN, WS2812B |

#### 1.3 Systemblockschaltbild (Mermaid)

Aktualisiertes Blockschaltbild (ersetzt das veraltete `blockschaltbild.md`,
das noch Mux-Timer ISR enthielt). Zeigt:
- Spannungsversorgung (5V USB → AMS1117 3.3V + HV-MOD ~170V)
- ESP32-S3 mit WiFi-Stack (AP + STA), NVS Flash
- I²C-Bus → 4× MCP23017 → 60× SMBTA42 → 6× IN-12A Nixie
- DS1302 RTC (ThreeWire: IO=GPIO4, CLK=GPIO5, CE=GPIO2)
- 10× WS2812B NeoPixel (GPIO21)
- VS1838B IR-Empfänger (GPIO48)
- 4× Taster SET/UP/DOWN/LIGHT (GPIO13–16)
- NTP (pool.ntp.org, nur bei STA-Verbindung)
- Web-Browser → HTTP API (192.168.4.1)

#### 1.4 Bibliotheksabhängigkeiten (Tabelle)

| Bibliothek | Quelle | Zweck |
|---|---|---|
| Adafruit NeoPixel  | Arduino Lib Mgr | WS2812B-Ansteuerung |
| Rtc by Makuna | Arduino Lib Mgr | DS1302 RTC |
| AsyncTCP | me-no-dev | Async TCP für ESP32 |
| ESPAsyncWebServer  | me-no-dev | HTTP-Server |
| ArduinoJson | Benoit Blanchon | JSON-Serialisierung (v6+) |
| IRremoteESP8266 | David Conran | IR-Empfang (NEC, Samsung …)  |

---

## Datei 2: `docs/system/hardware.md`

### Abschnitte

#### 2.1 PCB 1 – Logic Board (`nixieclocklogic_V2`, Rev 0.9, 2026-05-07)

Hauptkomponenten-Tabelle:

| Ref  | Wert / Teil | Funktion |
|---|---|---|
| U1 | ESP32-S3-WROOM-1 | Mikrocontroller, WiFi/BT |
| U2 | DS1302N+ | Batteriegepufferte Echtzeituhr (DIP-8) |
| U3 | VS1838B | IR-Empfänger 38 kHz |
| U4 | HV-MOD | Boost-Converter, erzeugt ~170 V DC |
| U5 | AMS1117-3.3 | LDO-Regler 5V → 3.3V |
| U22  | USBLC6-2SC6 | USB-ESD-Schutz |
| BT1  | CR2032 | RTC-Backup-Batterie |
| SW1–4| Taster | SET, UP, DOWN, LIGHT |
| J2 | USB Micro-B | 5V-Einspeisung und Programmierung |
| J3 | Logic (8-pin) | Inter-Board: I²C + Versorgung → Display |
| J4 | HV (4-pin) | Inter-Board: ~170V + HVgnd → Display |

Versorgungsschienen: +3.3V (Logik), VCC (pull-ups/RTC), GND, HV (~170V), HVgnd.

#### 2.2 PCB 2 – Nixie Display Board (`nixieclockin12_V2`, Rev 2.01, 2026-04-06)

Hauptkomponenten-Tabelle:

| Ref | Wert / Teil | Anzahl | Funktion |
|---|---|---|---|
| U1–U4 | MCP23017-E/SO | 4 | I²C GPIO-Expander, je 16 Ausgänge (SOIC-28)  |
| Q1–Q60 | SMBTA42 | 60 | NPN-Transistor (300V) als Kathodenschalter |
| NX1–NX6  | IN-12A | 6 | Nixie-Röhren (numerisch, Aufsicht) |
| D1 | 6× WS2812B-SMD | 6 | Hintergrundbeleuchtung (Pixel 0–5) |
| D2–D6 | WS2812B-SMD | 5 | Trennpunkt-LEDs (SMD) |
| D7–D9 | WS2812B (THT) | 3 | Trennpunkt-LEDs (Durchsteck, YF923) |
| J1 | Logic (8-pin) | 1 | Inter-Board: I²C + Versorgung ← Logic Board  |
| J2 | HV (4-pin) | 1 | Inter-Board: ~170V ← Logic Board |

MCP23017 I²C-Adressen (A2=0, A1=0/1, A0=0/1):

| IC  | Adresse | A2 | A1 | A0 | Zuständige Röhren |
|-----|---|----|----|----|---|
| U1  | 0x20 | 0  | 0  | 0  | Tube 0 (HZ), Tube 1 (HE) Bits 10–15 |
| U2  | 0x21 | 0  | 0  | 1  | Tube 1 (HE) Bits 0–3, Tube 2 (MZ) |
| U3  | 0x22 | 0  | 1  | 0  | Tube 3 (ME), Tube 4 (SZ) Bits 10–15 |
| U4  | 0x23 | 0  | 1  | 1  | Tube 4 (SZ) Bits 0–3, Tube 5 (SE) |

Jeder MCP23017 steuert 16 NPN-Transistoren (über 3.3kΩ Basiswiderstände),
die jeweils eine Nixie-Kathode auf GND ziehen. Die Anoden aller Röhren
liegen permanent an HV (~170V). Digit-Wert 10 = alle Bits aus = Röhre blank.

#### 2.3 Inter-Board-Verbindungen

J3 (Logic Board) ↔ J1 (Nixie Display Board), 8-polig:

> Exakte Pin-Nummern aus Schaltplan-PDF `nixieclocklogic_V2_BPHL.pdf` verifizieren.

| Pin | Signal | Richtung | Beschreibung |
|-----|---|---|---|
| — | VCC | Logic → Display  | 3.3V Logikversorgung |
| — | GND | — | Digitalmasse |
| — | SDA | ESP32 ↔ MCP23017 | I²C Daten (GPIO8) |
| — | SCL | ESP32 → MCP23017 | I²C Takt (GPIO9) |
| — | NEO | ESP32 → D1 | WS2812B Datenleitung (GPIO21) |
| — | — | — | (reserviert / nicht belegt) |

J4 (Logic Board) ↔ J2 (Nixie Display Board), 4-polig:

| Pin | Signal | Richtung | Beschreibung |
|-----|---|---|---|
| 1–2 | HV | Logic → Display | ~170V Anodenversorgung |
| 3–4 | HVgnd  | — | HV-Rückleiter |

#### 2.4 ESP32-S3 Pin-Belegung

| GPIO | Funktion | Modul/Peripheral |
|---|---|---|
| 2 | RTC_CE | DS1302 Chip Enable |
| 4 | RTC_IO | DS1302 Data |
| 5 | RTC_CLK | DS1302 Clock |
| 8 | I2C_SDA | MCP23017 ×4 (Daten) |
| 9 | I2C_SCL | MCP23017 ×4 (Takt) |
| 13 | BTN_SET | Taster SET (aktiv LOW) |
| 14 | BTN_UP | Taster UP (aktiv LOW) |
| 15 | BTN_DOWN | Taster DOWN (aktiv LOW) |
| 16 | BTN_LIGHT | Taster LIGHT (aktiv LOW) |
| 21 | NEO_DATA | WS2812B DIN (10 LEDs) |
| 48 | IR_RECV | VS1838B Ausgang |

---

## Datei 3: `docs/system/firmware.md`

### Abschnitte

#### 3.1 Modulübersicht

| Datei | Zeilen | Inhalt |
|---|---|---|
| `NixieClockUltra.ino` | 359  | Globals, `setup()`, `loop()`, Edit-Mode-FSM, Slot-Anim  |
| `nixie_driver.ino`  | 91 | `nixieInit()`, `nixieWrite()`, MCP23017-Abstraktion |
| `display.ino` | 47 | Fade-In/Out, `setDisplayTime()`, Digit-Mapping |
| `buttons.ino` | 119 | Entprell-FSM für 4 Taster, Kurz-/Langdruck-Erkennung |
| `rtc.ino` | 15 | `readRTC()`, `writeRTC()` via DS1302/ThreeWire |
| `neo_animation.ino` | 99 | Rainbow, Statisch, Puls, Slot-Machine, Trennpunkt-Blinken|
| `web_server.ino` | 559 | HTML/JS (embedded), alle API-Handler, WiFi-Setup, NTP |

#### 3.2 Setup-Ablauf

Nummerierte Liste der `setup()`-Schritte:
1. Serial (115200)
2. `nixieInit()` — I²C + MCP23017 initialisieren, alle Pins als Output, alle Bits 0
3. NeoPixel-Objekt initialisieren, Helligkeit setzen
4. RTC lesen (`readRTC()`), Zeit in `curHour/curMin/curSec` laden
5. Taster-Pins konfigurieren (INPUT_PULLUP)
6. IR-Empfänger starten (`IrReceiver.begin()`)
7. NVS laden (Helligkeit, Animation, WiFi-Creds, IR-Codes, colonAlwaysOn)
8. `setupWifi()` — AP starten + ggf. STA verbinden
9. `setupWebServer()` — alle Routes registrieren, server.begin()
10. NTP konfigurieren (nur wenn STA verbunden)
11. Fade-In-Sequenz starten (`startFadeIn = true`)

#### 3.3 Globale State-Variablen

| Variable | Typ | Beschreibung |
|---|---|---|
| `displayDigits`  | `uint8_t[6]` | Aktuell angezeigte Ziffern (0–9, 10=blank) |
| `brightLevel` | `uint8_t` | Helligkeitsstufe 0–3 (Index in BRIGHTNESS_LEVELS[]) |
| `neoBright` | `uint8_t` | NeoPixel-Feinwert 10–255 (Hintergrund) |
| `colonBright` | `uint8_t` | NeoPixel-Feinwert (Trennpunkte) |
| `neoHue` | `uint8_t` | Auto-inkrement für Rainbow-Animation |
| `animMode` | `AnimMode` | ANIM_RAINBOW / ANIM_STATIC / ANIM_PULSE / ANIM_SLOTS |
| `editState` | `EditState` | EDIT_NONE / EDIT_HOUR / EDIT_MIN / EDIT_SEC  |
| `colonAlwaysOn`  | `bool` | Trennpunkt-LEDs dauerhaft an (kein Blinken)  |
| `irCodes[]` | `uint64_t[7]` | Angelernte IR-Codes, Index = IrAction-enum |
| `wifiStaConnected`| `bool` | STA-Verbindung aktiv |
| `ntpSynced` | `bool` | NTP-Synchronisierung erfolgt |

#### 3.4 Nixie-Ansteuerung (nixie_driver.ino)

Direktansteuerung ohne Multiplexing:
- `nixieInit()`: Wire.begin(SDA=8, SCL=9), alle 4 MCP23017 auf Output, alle Bits 0
- `nixieWrite(digits[6])`: Berechnet für jede Röhre das zugehörige MCP-Bit anhand
  der `digitPin[tube][digit]`-Lookup-Tabelle, schreibt nur geänderte MCPs
  (Shadow-Register `mcpState[]`), geschützt durch FreeRTOS-Mutex
- Digit-Wert 10 → kein Bit gesetzt → Röhre blank

Tube-zu-MCP-Bit-Zuordnung (kompakt):

| Tube | Funktion | MCP  | Bits (GPA/GPB) |
|---|---|---|---|
| 0 | Stundenzehner| 0x20 | Bits 0–9 |
| 1 | Stundeneiner | 0x20 | Bits 10–15, 0x21 Bits 0–3 |
| 2 | Minutenzehner| 0x21 | Bits 4–13 |
| 3 | Minuteneiner | 0x22 | Bits 0–9 |
| 4 | Sekundenzehner| 0x22 | Bits 10–15, 0x23 Bits 0–3 |
| 5 | Sekundeneiner | 0x23 | Bits 4–13 |

#### 3.5 Web-API-Endpunkte

| Pfad | Methode | Body / Parameter | Funktion |
|---|---|---|---|
| `/` | GET | — | Liefert eingebettetes HTML/JS/CSS |
| `/api/status` | GET | — | Zeit, Helligkeit, Anim, WiFi, NTP |
| `/api/settime` | POST | `{h, m, s}` | Zeit in RTC schreiben |
| `/api/bright` | POST | `{level}` (0–3) | Helligkeitsstufe setzen |
| `/api/neobright`  | POST | `{value}` (10–255) | NeoPixel-Feinwert setzen |
| `/api/anim` | POST | `{mode}` (0–3) | Animationsmodus setzen |
| `/api/colonbright`| POST | `{value}` | Trennpunkt-Helligkeit |
| `/api/colonon` | POST | `{on}` (bool) | Trennpunkte dauerhaft an/aus |
| `/api/colonstatic`| POST | `{static}` (bool) | Trennpunkte statisch (kein Blinken)|
| `/api/slot` | POST | — | Slot-Machine-Animation auslösen |
| `/api/wifi` | GET | — | WiFi-Status (AP+STA IP, NTP) |
| `/api/wifi` | POST | `{ssid, password}` | STA-Verbindung einrichten |
| `/api/wifi/scan`  | GET | — | WLAN-Netzwerke scannen |
| `/api/ir/status`  | GET | — | Aktuelle IR-Code-Belegung |
| `/api/ir/learn` | POST | `{action}` (0–6) | IR-Lernmodus starten |
| `/api/ir/clear` | POST | `{action}` (0–6) | IR-Code löschen |

#### 3.6 NVS-Persistenz (Preferences)

Alle Einstellungen werden bei Änderung in den ESP32-NVS-Flash geschrieben
und beim Start automatisch geladen:

| Schlüssel | Typ | Inhalt |
|---|---|---|
| `brightLevel` | uint8  | Helligkeitsstufe (0–3) |
| `neoBright` | uint8  | NeoPixel-Feinwert (10–255) |
| `animMode` | uint8  | Animationsmodus (0–3) |
| `colonAlwaysOn`| bool  | Trennpunkte dauerhaft an |
| `colonStatic` | bool | Kein Blinken der Trennpunkte |
| `wifiSSID` | String | Heimnetz SSID |
| `wifiPass` | String | Heimnetz Passwort |
| `irCode_0`…`irCode_6` | uint64 | Angelernte IR-Codes je Funktion |

---

## Ausgabedateien

- `docs/system/README.md`
- `docs/system/hardware.md`
- `docs/system/firmware.md`
- `blockschaltbild.md` → Hinweis auf `docs/system/README.md` (kein Delete)

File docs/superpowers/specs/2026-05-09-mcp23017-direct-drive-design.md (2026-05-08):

# Design: MCP23017 Direct Drive (Nixie ohne Multiplexing)

**Datum:** 2026-05-09  
**Projekt:** NixieClockUltra  
**Status:** Genehmigt

---

## Ausgangssituation

Die bisherige Firmware steuert 6 Nixie-Röhren per Multiplexing über einen Hardware-Timer-ISR. Alle Röhren teilen 10 gemeinsame Kathoden-Pins am ESP32 — das führt zu unlösbarem Ghosting. Der Hardware-Umbau ersetzt dieses Konzept durch direkte Ansteuerung: Jede Röhre bekommt eigene Kathoden-Transistoren (SMBTA42), die von 4 MCP23017 Port-Expandern geschaltet werden. Die Anoden sind permanent mit HV verbunden.

---

## Hardware

### I2C
- SDA: GPIO 8  
- SCL: GPIO 9  
- Adressen: 0x20, 0x21, 0x22, 0x23

### Taster (neu)
- SET: GPIO 13  
- UP:  GPIO 14  
- DOWN: GPIO 15  
- LIGHT: GPIO 16

### MCP23017 Pin-Belegung

Jeder MCP23017-Ausgang schaltet den Basis-Eingang eines SMBTA42, der die jeweilige Nixie-Kathode auf GND zieht (LOW-aktiv).  
Digit-Reihenfolge im User-Spec: erst 1–8 (oder 1–6/1–4), dann 9, dann 0.

| MCP | Port | Bit  | Tube | Digit |
|---|---|---|---|---|
| 0x20  | GPA  | 0–7  | HZ | 1–8 |
| 0x20  | GPB  | 0 | HZ | 9 |
| 0x20  | GPB  | 1 | HZ | 0 |
| 0x20  | GPB  | 2–7  | HE | 1–6 |
| 0x21  | GPA  | 0–2  | HE | 7–9 |
| 0x21  | GPA  | 3 | HE | 0 |
| 0x21  | GPA  | 4–7  | MZ | 1–4 |
| 0x21  | GPB  | 0–4  | MZ | 5–9 |
| 0x21  | GPB  | 5 | MZ | 0 |
| 0x22  | GPA  | 0–7  | ME | 1–8 |
| 0x22  | GPB  | 0 | ME | 9 |
| 0x22  | GPB  | 1 | ME | 0 |
| 0x22  | GPB  | 2–7  | SZ | 1–6 |
| 0x23  | GPA  | 0–2  | SZ | 7–9 |
| 0x23  | GPA  | 3 | SZ | 0 |
| 0x23  | GPA  | 4–7  | SE | 1–4 |
| 0x23  | GPB  | 0–4  | SE | 5–9 |
| 0x23  | GPB  | 5 | SE | 0 |

Nicht belegte Bits (MCP 0x21 GPB6–7, MCP 0x23 GPB6–7): dauerhaft LOW (Output, 0).

---

## Software-Architektur

### Dateien

| Datei | Aktion | Inhalt |
|---|---|---|
| `mux_timer.ino` | **löschen** | ISR, Hardware-Timer — entfällt komplett |
| `nixie_driver.ino` | **neu** | MCP23017-Init, Shadow-Register, nixieWrite() |
| `NixieClockUltra.ino` | **anpassen** | Pins, Globals, setup() |
| `display.ino` | **anpassen** | nixieWrite() statt displayDigits[]+timerMux |
| `buttons.ino` | unverändert | — |
| `rtc.ino` | unverändert | — |
| `neo_animation.ino` | unverändert | — |
| `ir_remote.ino` | unverändert | — |
| `web_server.ino` | unverändert | — |

### nixie_driver.ino

```
nixieInit()
  - Wire.begin(8, 9)
  - Für jede MCP-Adresse: IODIRA=0x00, IODIRB=0x00 (alle Pins Output)
  - mcpState[4] = {0,0,0,0}
  - Alle Outputs LOW schreiben

nixieWrite(uint8_t digits[6])
  - Neuen mcpState aus digitPin-Lookup berechnen:
    Für jeden Tube i (0–5):
      Tube-Maske löschen (alle Bits dieses Tubes in betroffenen MCPs auf 0)
      Wenn digits[i] <= 9: Bit für (tube, digit) setzen
      (digits[i] == 10 → Röhre blank)
  - Für jeden MCP 0–3: wenn neuer Wert != mcpState[j], OLATA+OLATB schreiben
  - mcpState aktualisieren
```

**Lookup-Tabelle:**  
`DigitPin digitPin[6][10]` mit `{uint8_t mcp, uint8_t bit}` — kompilierzeit-konstant im Flash.

**Tube-Masken** (welche 16-Bit-Felder pro Tube zu löschen sind):

| Tube | MCP-Index | Maske (16 Bit) |
|---|---|---|
| HZ | 0 | 0x03FF |
| HE | 0, 1 | 0xFC00, 0x000F |
| MZ | 1 | 0x3FF0 |
| ME | 2 | 0x03FF |
| SZ | 2, 3 | 0xFC00, 0x000F |
| SE | 3 | 0x3FF0 |

### Änderungen NixieClockUltra.ino

**Entfernt:**
- `CATHODE_PIN[]`, `ANODE_PIN[]`
- `DRAM_ATTR`, `driver/gpio.h`
- `volatile displayDigits[]`, `fadeBrightness[]`, `muxIndex`, `inBlank`
- `hw_timer_t *muxTimer`, `portMUX_TYPE timerMux`
- Forward-Deklaration `void IRAM_ATTR onMuxTimer()`
- Timer-Setup in `setup()`

**Geändert:**
- `BTN_SET=13`, `BTN_UP=14`, `BTN_DOWN=15`, `BTN_LIGHT=16`
- `#include <Wire.h>` hinzufügen
- `setup()`: `nixieInit()` aufrufen (nach WiFi, analog bisherigem Timer-Start)
- `displayDigits[]` bleibt als nicht-volatile uint8_t[6] als Staging-Buffer

### Änderungen display.ino

- `setDisplayTime()`: schreibt in `displayDigits[]`, ruft `nixieWrite(displayDigits)` auf
- `updateSlotAnimation()`: schreibt `displayDigits[i]` direkt, ruft `nixieWrite(displayDigits)` am Ende auf
- `handleEditMode()`: `portENTER_CRITICAL`/`portEXIT_CRITICAL` entfernen, `nixieWrite(displayDigits)` am Ende

---

## Nixie-Helligkeit

Die bisherige `brightLevel`-Stufenschaltung (Taster LIGHT, Web-UI) wirkt ausschließlich auf NeoPixel — bleibt unverändert. Nixie-Röhren laufen bei direkter Ansteuerung ohne PWM immer bei voller Helligkeit.

---

## Nicht geändert

- NeoPixel-Animationen, Farben, Helligkeit
- RTC-Lesen/Schreiben
- Einstellmodus (FSM), Timeout
- Slot-Machine-Animation (Logik bleibt, nur Ausgabe via nixieWrite)
- IR-Fernbedienung und Lernmodus
- Web-Interface (alle API-Endpunkte)
- WiFi AP + STA, NTP-Sync
- Preferences / NVS-Persistenz
- Power-Save (NeoPixel dimmen)
- Trennpunkt-LEDs (colonAlwaysOn, colonStatic)

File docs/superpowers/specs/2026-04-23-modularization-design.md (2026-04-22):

# Modularisierung NixieClockUltra – Design-Spec

**Projekt:** NixieClockUltra  
**Datum:** 2026-04-23  
**Status:** Freigegeben

---

## Ziel

Die monolithische `NixieClockUltra.ino` (~1527 Zeilen) wird in 8 thematisch abgegrenzte `.ino`-Dateien aufgeteilt. Der Code wird dabei nicht inhaltlich verändert – es ist ein reines Refactoring zur Verbesserung der Übersichtlichkeit und Wartbarkeit.

---

## Architektur

Arduino IDE fügt alle `.ino`-Dateien eines Sketch-Ordners alphabetisch hinter der Haupt-`.ino`-Datei zu einer einzigen Übersetzungseinheit zusammen. Damit gilt:

- Alle globalen Variablen und Funktionen sind in allen Dateien direkt sichtbar.
- `#include`-Direktiven und `#define`-Makros stehen ausschließlich in `NixieClockUltra.ino`.
- Keine `extern`-Deklarationen nötig.
- Alphabetische Reihenfolge der Dateien ist unkritisch, da Arduino IDE für `.ino`-Dateien automatisch Forward-Deklarationen erzeugt.

---

## Dateistruktur

| Datei | Verantwortlichkeit | Enthält |
|---|---|---|
| `NixieClockUltra.ino` | Konfiguration, Globals, Einstiegspunkt | `#include`, Pin-Defines, Konstanten, alle globalen Variablen, `setup()`, `loop()` |
| `buttons.ino` | Tasteneingabe und Einstellmodus | `Button`-Struct, `updateButton()`, `handleEditMode()`, `handleBrightness()`, `handlePowerSave()` |
| `display.ino` | Anzeige-Logik | `setDisplayTime()`, `startSlotAnimation()`, `updateSlotAnimation()`, Fade-In-Logik |
| `ir_remote.ino` | IR-Fernbedienung | `IrAction`-Enum, IR-Globals (`irCodes[]`, `irLearnTarget`, `irMux` etc.), `executeAction()`, `dispatchIRAction()`, `handleIR()` |
| `mux_timer.ino` | Nixie-Multiplexing | `onMuxTimer()` ISR (IRAM_ATTR), Timer-Init-Hilfsfunktion |
| `neo_animation.ino` | NeoPixel-Beleuchtung | `updateNeoPixel()` |
| `rtc.ino` | Echtzeituhr | `readRTC()`, `writeRTC()` |
| `web_server.ino` | Web-Interface | `WEB_PAGE` PROGMEM-String, `setupWifi()`, `setupWebServer()` mit allen API-Endpunkten |

---

## Globale Variablen (bleiben in `NixieClockUltra.ino`)

Alle globalen Variablen verbleiben in der Haupt-Datei, damit ihre Definition eindeutig lokalisiert ist:

- `displayDigits[]`, `fadeBrightness[]`, `muxIndex`, `inBlank`
- `brightLevel`, `neoHue`, `neoSat`, `neoBright`, `animMode`
- `editState`, `curHour`, `curMin`, `curSec`
- `lastInteractionMs`, `powerSaveActive`, `powerSaveEnabled`
- `wifiStaConnected`, `ntpSynced`, `slotActive`, `startFadeIn`
- `muxTimer`, `timerMux` (portMUX_TYPE)
- `irCodes[]`, `irLearnTarget`, `irLearnStartMs`, `irMux` (portMUX_TYPE)
- Objekte: `rtcWire`, `Rtc`, `strip`, `server`, `prefs`, `irrecv`, `irResults`
- Button-Instanzen: `btnSet`, `btnUp`, `btnDown`, `btnLight`

---

## Randbedingungen

- **Kein inhaltlicher Code-Change:** Nur Verschiebung von Funktionen und Typdefinitionen zwischen Dateien. Kein Umschreiben, keine neuen Abstraktionen.
- **`IrAction`-Enum** wandert zusammen mit den IR-Globals nach `ir_remote.ino`, da es nur dort benötigt wird. Da die Arduino IDE alle Dateien zusammenfügt, ist der Typ trotzdem in der gesamten Sketch-Einheit sichtbar.
- **`Button`-Struct** wandert nach `buttons.ino`; die Button-Instanzen (`btnSet` etc.) bleiben als globale Variablen in `NixieClockUltra.ino`.
- **PROGMEM-String `WEB_PAGE`** gehört vollständig nach `web_server.ino`.
- Die Haupt-Datei `NixieClockUltra.ino` enthält nach dem Refactoring nur noch Includes, Defines, Globals, `setup()` und `loop()`.

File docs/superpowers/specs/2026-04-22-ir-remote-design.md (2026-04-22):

# IR-Fernbedienungssteuerung – Design-Spec

**Projekt:** NixieClockUltra  
**Datum:** 2026-04-22  
**Status:** Freigegeben

---

## Überblick

Erweiterung der NixieClockUltra-Firmware um IR-Fernbedienungsempfang sowie einen abschaltbaren Power-Save-Modus. Ein VS1838-IR-Empfänger auf Pin IO48 empfängt Signale beliebiger Fernbedienungen. Über das Web-Interface können Fernbedienungstasten den 7 Uhrzeit-Funktionen zugeordnet werden (Anlernmodus). Die Zuordnung wird persistent im NVS-Flash gespeichert.

---

## Hardware

- **Bauteil:** VS1838 (38-kHz-IR-Empfänger)
- **Pin:** `IR_RECV_PIN = 48`
- **Bibliothek:** `IRremoteESP8266` (Arduino Library Manager)

---

## Unterstützte Funktionen

| Funktions-ID | Beschreibung |
|---|---|
| `SET` | Einstellmodus ein / weiterschalten / speichern (identisch mit BTN_SET) |
| `UP` | Wert erhöhen im Einstellmodus (identisch mit BTN_UP) |
| `DOWN` | Wert verringern im Einstellmodus (identisch mit BTN_DOWN) |
| `BRIGHTNESS` | Helligkeitsstufe wechseln (identisch mit BTN_LIGHT) |
| `ANIM_NEXT` | Nächsten Animationsmodus aktivieren |
| `SLOT` | Slot-Machine-Animation auslösen |
| `POWER_SAVE_TOGGLE` | Power-Save-Modus ein- oder ausschalten |

---

## Architektur

### Initialisierung

```cpp
#define IR_RECV_PIN 48
IRrecv irrecv(IR_RECV_PIN);
decode_results irResults;

// in setup():
irrecv.enableIRIn();
```

### Empfang im loop()

```cpp
void handleIR() {
  if (irrecv.decode(&irResults)) {
    uint64_t code = irResults.value;
    irrecv.resume();

    if (irLearnTarget != IR_LEARN_NONE) {
      // Anlernmodus: Code der Zielfunktion zuweisen
      saveIRCode(irLearnTarget, code);
      irLearnTarget = IR_LEARN_NONE;
    } else {
      // Normalbetrieb: Funktion ausführen
      dispatchIRAction(code);
    }
  }
}
```

### NeoPixel-Konflikt vermeiden

`strip.show()` wird immer von `irrecv.pause()` / `irrecv.resume()` eingeschlossen:

```cpp
irrecv.pause();
strip.show();
irrecv.resume();
```

Hintergrund: Auch auf ESP32-S3 (RMT-Backend) kann das Timing von `strip.show()` IR-GPIO-Interrupts stören und zu korrumpierten Codes führen. Ein während des ~300 µs langen Schreibvorgangs eintreffendes Signal geht verloren – das ist akzeptabel.

### Anlernmodus

```cpp
enum IrAction {
  IR_LEARN_NONE = -1,
  IR_ACTION_SET,
  IR_ACTION_UP,
  IR_ACTION_DOWN,
  IR_ACTION_BRIGHTNESS,
  IR_ACTION_ANIM_NEXT,
  IR_ACTION_SLOT,
  IR_ACTION_POWER_SAVE_TOGGLE,
  IR_ACTION_COUNT
};

volatile IrAction irLearnTarget = IR_LEARN_NONE;
```

- Über `/api/ir/learn` setzt der Web-Server `irLearnTarget` auf die gewünschte Funktion.
- 10-Sekunden-Timeout: Wenn innerhalb von 10 s kein Code empfangen wird, wird `irLearnTarget` auf `IR_LEARN_NONE` zurückgesetzt.
- Der nächste empfangene Code (egal welches Protokoll) wird dieser Funktion zugewiesen.
- Repeat-Codes (`0xFFFFFFFF` bei NEC) werden beim Anlernen ignoriert.

### Aktionsausführung

```cpp
void dispatchIRAction(uint64_t code) {
  for (int i = 0; i < IR_ACTION_COUNT; i++) {
    if (irCodes[i] != 0 && irCodes[i] == code) {
      executeAction((IrAction)i);
      lastInteractionMs = millis();  // Power-Save zurücksetzen
      return;
    }
  }
}
```

`executeAction()` führt die Aktion direkt aus (modifiziert Zustandsvariablen), ohne Button-Strukturen zu simulieren. Beispiel: `BRIGHTNESS` ruft denselben Code auf wie `handleBrightness()` bei `btnLight.pressed`. Das vermeidet Seiteneffekte durch die Entprelllogik.

---

## Datenspeicherung (NVS)

7 Einträge für IR-Codes in Preferences, Namespace `"nixie"`:

| Schlüssel | Typ | Inhalt |
|---|---|---|
| `ir_SET` | `uint64_t` | Gespeicherter Code, 0 = nicht belegt |
| `ir_UP` | `uint64_t` | — |
| `ir_DOWN` | `uint64_t` | — |
| `ir_BRIGHTNESS` | `uint64_t` | — |
| `ir_ANIM_NEXT` | `uint64_t` | — |
| `ir_SLOT` | `uint64_t` | — |
| `ir_PSTOGGLE` | `uint64_t` | — |

Zusätzlich ein Flag für den Power-Save-Aktivierungszustand:

| Schlüssel | Typ | Inhalt |
|---|---|---|
| `psEnabled` | `bool` | `true` = Power-Save aktiv (Standard), `false` = dauerhaft deaktiviert |

Beim Start werden alle 7 IR-Codes in `uint64_t irCodes[IR_ACTION_COUNT]` geladen sowie `powerSaveEnabled` aus NVS.

---

## Web-Interface

### Änderung bestehende Karte: „💡 Helligkeit & Animation"

Ein Toggle-Schalter **„Power-Save"** wird am Ende der Karte ergänzt:
- Beschriftung: `Power-Save (Auto-Dimmen nach 120 s)`
- Zustand wird per `/api/powersave` gesetzt und beim Laden der Seite aus `/api/status` gelesen.

### Neue Karte: „📡 IR-Fernbedienung"

Eingefügt nach der Helligkeit-Karte, vor dem WLAN-Bereich.

**Tabellenaufbau:**

| Funktion | Gespeicherter Code | Aktionen |
|---|---|---|
| SET | `NEC 0xFFA25D` | [Anlernen] [✕] |
| UP | `—` | [Anlernen] [✕] |
| … | … | … |
| Power-Save Toggle | `—` | [Anlernen] [✕] |

- **[Anlernen]:** Startet POST `/api/ir/learn` → Zeile blinkt orange, Statustext „Taste drücken…" (10 s Timeout)
- **[✕]:** POST `/api/ir/clear` → Code wird gelöscht, Anzeige auf `—`
- Während Lernmodus aktiv: Frontend pollt `/api/ir/status` alle 500 ms. Sobald Code empfangen, Zeile aktualisiert sich und Lernmodus endet.

### Neue API-Endpunkte

| Endpunkt | Methode | Request | Response |
|---|---|---|---|
| `/api/ir/status` | GET | — | `{"learning":"SET","codes":{"SET":"NEC 0xFFA25D","UP":"","...":"..."}}` |
| `/api/ir/learn` | POST | `{"action":"SET"}` | `{"ok":true}` |
| `/api/ir/clear` | POST | `{"action":"SET"}` | `{"ok":true}` |
| `/api/powersave` | POST | `{"enabled":true}` | `{"ok":true}` |

`/api/status` wird um das Feld `"psEnabled": true/false` erweitert.

---

## Randbedingungen

- Repeat-Codes (z.B. NEC `0xFFFFFFFFFFFFFFFF`) werden im Normalbetrieb ignoriert (kein ungewolltes Auto-Repeat).
- `POWER_SAVE_TOGGLE` schaltet `powerSaveEnabled` um und speichert den neuen Wert in NVS. Wenn deaktiviert, greift `handlePowerSave()` nicht mehr – NeoPixel bleiben dauerhaft auf voller Helligkeit.
- Die IR-Verarbeitung greift auf dieselben Zustandsvariablen zu wie die physischen Taster – kein paralleler Einstellmodus möglich (IR und Taster arbeiten additiv, nicht gleichzeitig).
- `irrecv.pause()` / `irrecv.resume()` umschließen jeden `strip.show()`-Aufruf.
- Die Bibliothek `IRremoteESP8266` muss in der `platformio.ini` bzw. im Arduino Library Manager hinzugefügt werden.

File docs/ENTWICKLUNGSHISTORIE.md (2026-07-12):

# NixieClockUltra – Entwicklungshistorie

Chronologische Übersicht aller Entwicklungsschritte, Architekturentscheidungen und Problemlösungen.

---

## Phase 1 – Initiales Firmware-Grundgerüst (2026-04-22)

**Ausgangspunkt:** Neue Hardware auf Basis ESP32-S3 mit 6 Nixie-Röhren, WS2812B NeoPixel, DS1302 RTC und IR-Empfänger.

**Was entstand:**
- Vollständige Basis-Firmware in einer einzigen `.ino`-Datei
- Nixie-Ansteuerung via Multiplex-ISR (Hardware-Timer)
- NeoPixel-Animationen (Rainbow, Static, Pulse)
- Web-Interface (WiFi AP, AsyncWebServer)
- IR-Fernbedienung mit web-basiertem Anlernmodus (7 Funktionen)
- Power-Save-Toggle (später wieder entfernt)
- DS1302 RTC-Integration

---

## Phase 2 – Modularisierung (2026-04-23)

**Problem:** Die einzige `.ino`-Datei war unübersichtlich geworden.

**Lösung:** Code aufgeteilt in separate Module:
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

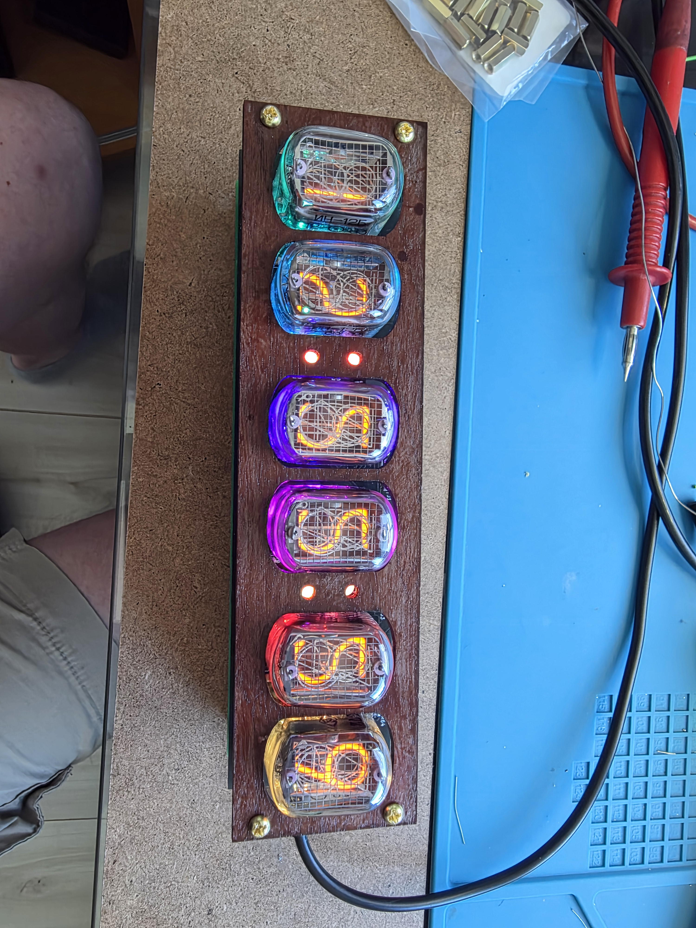
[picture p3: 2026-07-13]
docs/website/img/gallery/16 Chassis im Betrieb 4.jpg

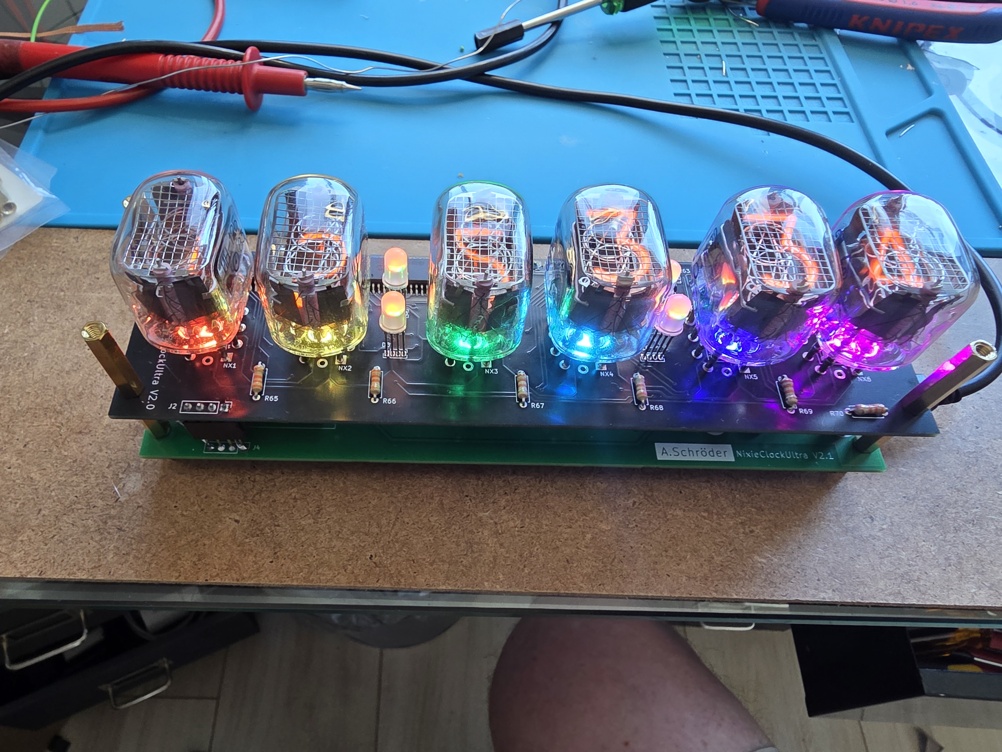
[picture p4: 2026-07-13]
docs/website/img/gallery/16 Chassis im Betrieb.jpg

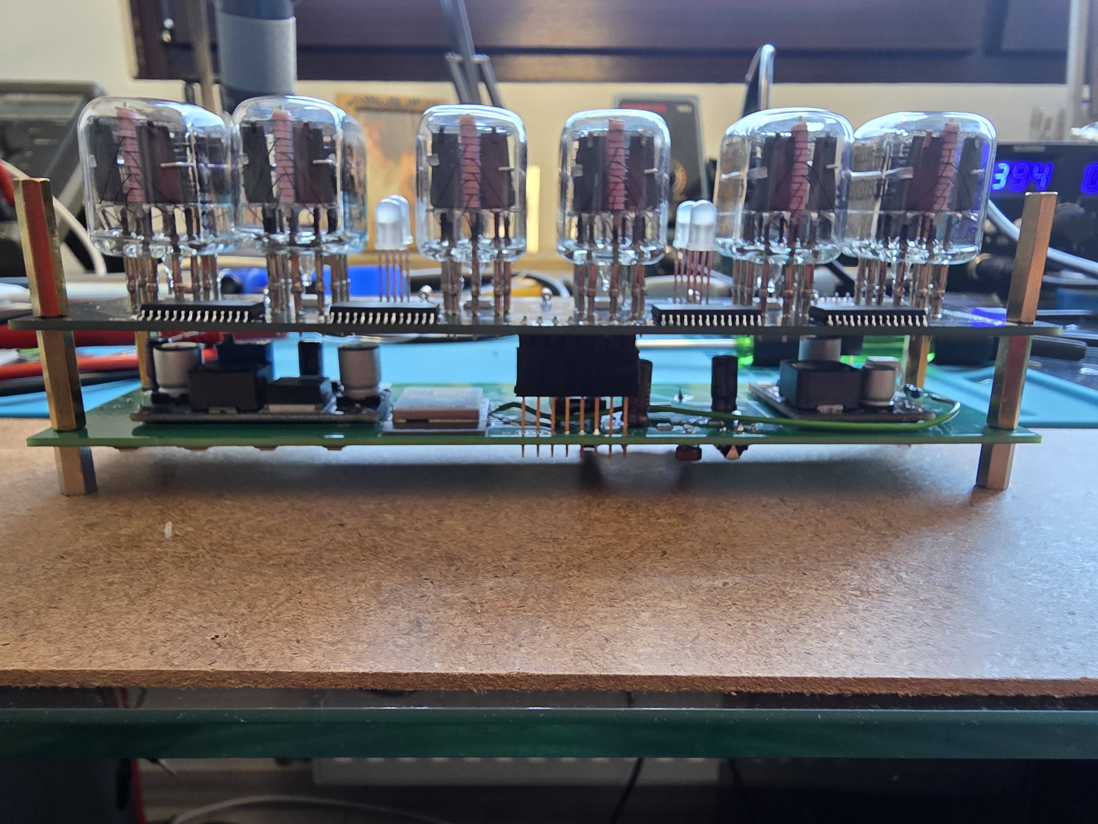
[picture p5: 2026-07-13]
docs/website/img/gallery/15 Chassis montiert 2.jpg

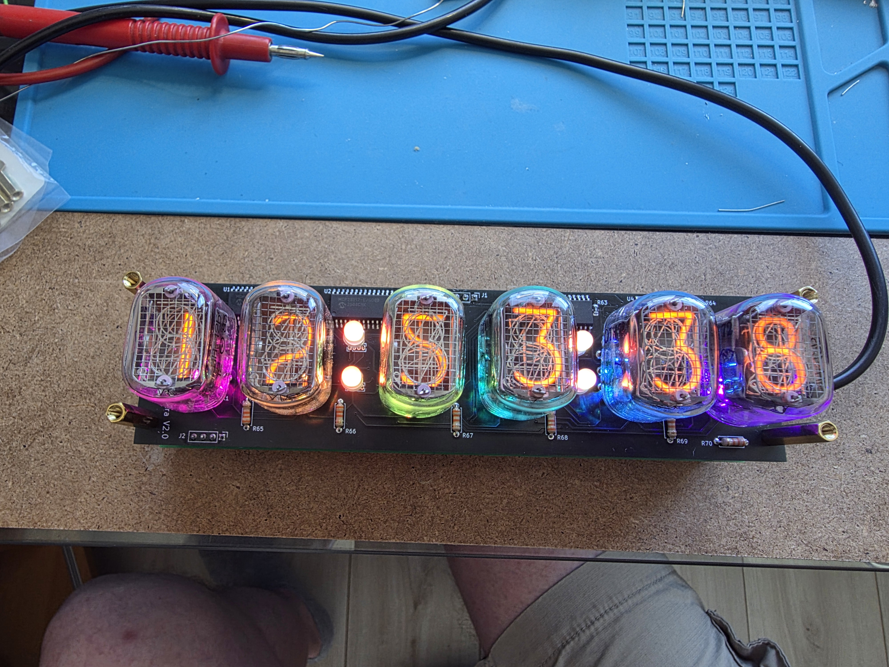
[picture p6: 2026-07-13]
docs/website/img/gallery/16 Chassis im Betrieb 2.jpg

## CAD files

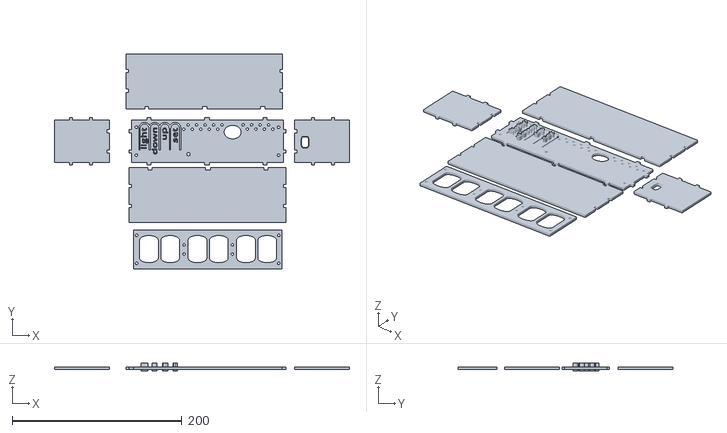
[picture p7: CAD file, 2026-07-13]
docs/Gehäuse/Source/NixieClockUtra.stl
348.0 x 253.3 x 10.0

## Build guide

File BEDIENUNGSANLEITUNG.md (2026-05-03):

# Nixie Clock Ultra – Bedienungsanleitung

## Übersicht

Die Nixie Clock Ultra ist eine Röhrenuhr auf Basis des ESP32-S3 mit 6 Nixie-Röhren, 10 NeoPixel-LEDs, einem Web-Interface zur Fernbedienung sowie einem IR-Empfänger für die Steuerung per Infrarot-Fernbedienung.

---

## Inbetriebnahme

1. Gerät mit Spannung versorgen
2. Die Nixie-Röhren starten mit einem sanften Fade-In
3. Die Uhr zeigt sofort die in der RTC gespeicherte Zeit an

> **Sicherheitshinweis:** Die Nixie-Hochspannung beträgt 170–180 V DC. Vor Arbeiten an der Schaltung unbedingt die Kondensatoren entladen. Nie unter Spannung an der Schaltung arbeiten.

---

## Tasten

Das Gerät besitzt vier Tasten:

| Taste | Kurzer Druck | Langer Druck |
|---|---|---|
| **SET** | Einstellmodus starten / nächste Stelle wählen / Zeit speichern | — |
| **UP** | Wert erhöhen | Wert erhöhen (Auto-Repeat) |
| **DOWN** | Wert verringern | Wert verringern (Auto-Repeat) |
| **LIGHT** | Helligkeit weiterschalten (4 Stufen) | Trennpunkt-LEDs dauerhaft an/aus |

---

## Zeit einstellen (Tasten)

1. **SET** drücken → Stunden blinken
2. Mit **UP** / **DOWN** Stunden einstellen
3. **SET** drücken → Minuten blinken
4. Mit **UP** / **DOWN** Minuten einstellen
5. **SET** drücken → Sekunden blinken
6. Mit **UP** / **DOWN** Sekunden einstellen
7. **SET** drücken → Zeit wird gespeichert, Normalanzeige

Die blinkende Stelle zeigt an, welcher Wert gerade eingestellt wird. Nach **15 Sekunden** ohne Eingabe wird der Einstellmodus automatisch beendet und die Zeit gespeichert.

---

## NeoPixel-Helligkeit (Taste LIGHT – kurzer Druck)

Jeder kurze Druck auf **LIGHT** schaltet zur nächsten NeoPixel-Helligkeitsstufe:

| Stufe | Beschreibung |
|---|---|
| 1 | Sehr dim |
| 2 | Dim |
| 3 | Hell |
| 4 | Voll (Standard) |

Die gewählte Stufe wird dauerhaft gespeichert.

---

## Trennpunkt-LEDs (Taste LIGHT – langer Druck)

Ein langer Druck auf **LIGHT** schaltet die vier Trennpunkt-LEDs zwischen zwei Modi um:

| Modus | Beschreibung |
|---|---|
| **Blinken** (Standard) | LEDs blinken sekundengenau im Takt der Uhr |
| **Dauerhaft an** | LEDs leuchten durchgehend ohne zu blinken |

Die Einstellung wird dauerhaft gespeichert und kann auch über IR oder das Web-Interface geändert werden.

---

## IR-Fernbedienung

Die Uhr kann mit einer beliebigen Infrarot-Fernbedienung gesteuert werden. Jede Taste der Fernbedienung kann einer Funktion zugewiesen werden (siehe [Fernbedienung anlernen](#fernbedienung-anlernen)).

### Verfügbare IR-Funktionen

| Funktion | Beschreibung |
|---|---|
| SET | Einstellmodus starten / nächste Stelle / Zeit speichern |
| UP | Wert erhöhen im Einstellmodus |
| DOWN | Wert verringern im Einstellmodus |
| BRIGHTNESS | Helligkeit weiterschalten (4 Stufen) |
| ANIM_NEXT | Nächsten Animationsmodus aktivieren |
| SLOT | Slot-Machine-Animation auslösen |
| COLON_TOGGLE | Trennpunkt-LEDs dauerhaft an/aus |

Nicht belegte Funktionen werden ignoriert. Repeat-Codes (Auto-Repeat der Fernbedienung) werden beim Empfang herausgefiltert.

---

## WLAN und Web-Interface

### Verbindung herstellen

Die Uhr startet immer als WLAN-Access-Point:

| Parameter  | Wert |
|---|---|
| SSID | `NixieClock`  |
| Passwort | `nixie1234` |
| IP-Adresse | `192.168.4.1` |

1. Mit dem WLAN `NixieClock` verbinden
2. Browser öffnen: `http://192.168.4.1`

### Heimnetz einrichten

Im Web-Interface unter **WLAN-Einrichtung**:

1. Auf **Scannen** klicken → verfügbare Netzwerke erscheinen
2. Gewünschtes Netzwerk auswählen
3. Passwort eingeben
4. **Verbinden** klicken → Uhr startet automatisch neu

Nach dem Neustart ist die Uhr sowohl über den eigenen Hotspot (`192.168.4.1`) als auch über das Heimnetz erreichbar. Die IP-Adresse im Heimnetz wird im Web-Interface angezeigt.

Zum Entfernen des Heimnetzes: SSID-Feld leer lassen und **Verbinden** klicken.

### NTP-Zeitsynchronisierung

Sobald die Uhr mit dem Heimnetz verbunden ist, synchronisiert sie die Zeit automatisch einmalig über NTP (`pool.ntp.org`). Die Zeitzone ist auf **Mitteleuropa (CET/CEST)** eingestellt. Der NTP-Status wird im Web-Interface angezeigt.

---

## Web-Interface – Funktionen

### Zeit stellen

- Stunden, Minuten und Sekunden manuell eingeben und **Übernehmen** klicken
- **Browser-Zeit** übernimmt automatisch die aktuelle Zeit des Geräts, von dem aus das Web-Interface geöffnet ist

### Helligkeit & Animation

| Einstellung | Beschreibung |
|---|---|
| NeoPixel-Helligkeit (Stufen) | 4 Stufen (entspricht kurzem Druck auf LIGHT) |
| NeoPixel-Helligkeit (Fein) | Schieberegler 10–255 |
| Animation | Animationsmodus wählen (siehe unten) |
| NeoPixel-Farbe (Hue) | Grundfarbe für statische Modi und Puls |
| Trennpunkte dauerhaft an | Trennpunkt-LEDs blinken oder leuchten dauerhaft |

### Animationsmodi

| Modus | Beschreibung |
|---|---|
| Rainbow | Farbverlauf wandert über die 6 Hintergrund-LEDs |
| Statisch Warmweiß | Alle Hintergrund-LEDs in warmweißem Orange |
| Puls | Sinusförmiges Auf- und Abdimmen der gesamten Beleuchtung |
| Slot-Machine | Schneller Farbwechsel während der Slot-Animation, sonst Rainbow |

Die Trennpunkt-LEDs (zwischen den Zifferngruppen) blinken in allen Modi sekundengenau – oder leuchten dauerhaft, wenn der entsprechende Toggle aktiviert ist.

### Slot-Machine-Animation

Klick auf **Slot-Machine!** lässt alle 6 Röhren ihre Ziffer schnell durchrollen. Jede Röhre stoppt nacheinander (mit ca. 180 ms Versatz) bei der aktuellen Uhrzeit.

Im Modus *Slot-Machine* wird die Animation außerdem automatisch **alle 10 Sekunden** ausgelöst.

### Fernbedienung anlernen

In der Karte **IR-Fernbedienung** werden alle 7 Funktionen als Tabelle dargestellt. Neben jeder Funktion steht der aktuell gespeicherte Code (z. B. `0xFFA25D`) oder `—` wenn noch kein Code hinterlegt ist.

**Anlernen:**
1. Auf **Anlernen** neben der gewünschten Funktion klicken
2. Die Zeile blinkt orange und zeigt „Taste auf Fernbedienung drücken…"
3. Beliebige Taste auf der Fernbedienung drücken → Code wird sofort gespeichert
4. Nach **10 Sekunden** ohne Eingabe bricht der Anlernmodus automatisch ab

**Code löschen:** Auf **✕** neben der Funktion klicken.

Es können beliebige IR-Fernbedienungen verwendet werden (NEC, Samsung, Sony, RC5 u. v. m.). Jede Funktion kann unabhängig belegt werden.

---

## Einstellungen-Persistenz

Folgende Einstellungen werden dauerhaft im Flash-Speicher gespeichert und nach einem Neustart automatisch wiederhergestellt:

- Nixie-Helligkeit
- NeoPixel-Helligkeit
- Animationsmodus
- Trennpunkt-LEDs dauerhaft an/aus
- WLAN-Zugangsdaten
- IR-Codes (alle 7 Funktionen)

---

## Technische Daten

| Eigenschaft | Wert |
|---|---|
| Mikrocontroller | ESP32-S3 |
| Nixie-Röhren | 6 Stück (Multiplexing) |
| NeoPixel | 10x WS2812B |
| Echtzeituhr | DS1302 |
| IR-Empfänger | VS1838 (38 kHz), Pin IO48 |
| Versorgungsspannung | 5 V (Logik) + HV für Nixies |
| Nixie-Hochspannung  | 170–180 V DC |
| Web-Interface | Port 80, HTTP |
| NTP-Zeitzone | CET-1CEST (Mitteleuropa) |

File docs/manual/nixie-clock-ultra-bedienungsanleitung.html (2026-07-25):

Nixie Clock Ultra

Bedienungsanleitung

Modell ESP32-S3 · 6 Nixie-Röhren IN-12

Version 2.1 · Juni 2026

Inhalt

I. Übersicht & Sicherheit 3

II. Inbetriebnahme 4

III. Tasten & Bedienung 5

IV. Zeit & Datum einstellen 6

V. Beleuchtung & Animationen 7

VI. IR-Fernbedienung 9

VII. WLAN & Web-Interface 11

VIII. Nacht-Modus 13

IX. Einstellungen & Persistenz 14

X. Technische Daten 15

Nixie Clock Ultra · Bedienungsanleitung ⚙ 3

Kapitel I

# Übersicht & Sicherheit

Die Nixie Clock Ultra ist eine Röhrenuhr auf Basis des ESP32-S3 mit 6 Nixie-Röhren IN-12, 10 NeoPixel-LEDs, einem Web-Interface sowie einem IR-Empfänger. Die Röhren zeigen die aktuelle Uhrzeit in direkter Ansteuerung ohne Multiplexing — für maximale Helligkeit und ghostingfreie Darstellung.

Sicherheitshinweis – Hochspannung

Die Nixie-Röhren werden mit 170–180 V DC betrieben. Diese Spannung ist bei Berührung hier zwar nicht lebensgefährlich (wegen minimaler Leistung) aber deutich unangenehm. Vor jeglichen Arbeiten an der Schaltung die Versorgungsspannung trennen und eine Minute warten. Nie unter Spannung an der Schaltung arbeiten.

## Lieferumfang

Die Uhr wird betriebsbereit geliefert. Eine Infrarot-Fernbedienung ist nicht im Lieferumfang enthalten — jede handelsübliche IR-Fernbedienung (NEC, Samsung, Sony, RC5 u.v.m.) kann angelernt werden.

Nixie Clock Ultra · Bedienungsanleitung ⚙ 4

Kapitel II

# Inbetriebnahme

Die Uhr ist nach dem Anschließen an die Spannungsversorgung (USB 5 Volt) sofort betriebsbereit.

1

Spannungsversorgung anschließen. Die Nixie-Röhren starten mit einem sanften Fade-In der NeoPixel-Beleuchtung.

2

Die Uhr zeigt sofort die im internen Uhr-Chip gespeicherte Uhrzeit an — auch ohne WLAN-Verbindung.

3

Alle gespeicherten Einstellungen (Helligkeit, Animation, IR-Codes, WLAN-Zugangsdaten, Nacht-Modus) werden automatisch geladen.

4

Der WLAN-Hotspot NixieClockCS (Passwort: nixie1234) ist sofort aktiv und unter 192.168.4.1 erreichbar. Im Heimnetz zusätzlich über http://nixieclockcs.local.

Ist die Uhrzeit nach dem ersten Start falsch, wurde der interne Uhr-Chip noch nicht eingestellt. Zeit und Datum lassen sich per Tastendruck (Kapitel IV) oder bequem über das Web-Interface (Kapitel VII) korrigieren. Sobald die Uhr mit einem Heimnetz verbunden ist, synchronisiert sie Uhrzeit und Datum automatisch mit einem Zeitserver.

Nixie Clock Ultra · Bedienungsanleitung ⚙ 5

Kapitel III

# Tasten & Bedienung

Das Gehäuse beherbergt vier Drucktaster, die alle wesentlichen Einstellungen direkt am Gerät ermöglichen. Jede Taste reagiert auf kurzen und — wo angegeben — auf langen Druck (≥ 600 ms gehalten).

Taste | Kurzer Druck | Langer Druck
SET | Einstellmodus starten · nächste Stelle (Zeit/Datum) · Speichern | —
UP | Wert erhöhen | Wert erhöhen (Auto-Repeat)
DOWN | Wert verringern | Wert verringern (Auto-Repeat)
LIGHT | Helligkeit weiterschalten (4 Stufen) | Trennpunkt-LEDs dauerhaft an/aus

Alle Tasteneinstellungen wirken sofort und werden dauerhaft gespeichert. Dieselben Funktionen stehen alternativ über die IR-Fernbedienung (Kapitel VI) und das Web-Interface (Kapitel VII) zur Verfügung.

Nixie Clock Ultra · Bedienungsanleitung ⚙ 6

Kapitel IV

# Zeit & Datum einstellen

Uhrzeit und Datum lassen sich direkt am Gerät per Tastendruck einstellen. Die blinkende Stelle zeigt an, welcher Wert gerade bearbeitet wird. Der vollständige Durchlauf umfasst sieben SET-Drücke für alle sechs Felder.

## Einstellreihenfolge

1

SET drücken → Stunden blinken auf.

2

Mit UP / DOWN die Stunden einstellen (0–23). Langer Druck aktiviert Auto-Repeat.

3

SET drücken → Minuten blinken auf. Einstellen (0–59).

4

SET drücken → Sekunden blinken auf. Einstellen (0–59).

5

SET drücken → Tag blinkt auf. Einstellen (1–31). Die Anzeige wechselt in das Datumsformat TT MM JJ.

6

SET drücken → Monat blinkt auf. Einstellen (1–12).

7

SET drücken → Jahr (2-stellig) blinkt auf. Einstellen (00–99).

8

SET drücken → alle Werte werden in der RTC gespeichert, Normalanzeige kehrt zurück.

Abkürzung: Wer nur die Uhrzeit korrigieren möchte, kann nach Schritt 4 (Sekunden) einfach 15 Sekunden warten — der Einstellmodus beendet sich automatisch und speichert die bisherigen Werte.

Netzwerk-Zeit (NTP): Sobald die Uhr mit dem Heimnetz verbunden ist, werden Uhrzeit und Datum automatisch synchronisiert — eine manuelle Eingabe ist dann nicht erforderlich.

Nixie Clock Ultra · Bedienungsanleitung ⚙ 7

Kapitel V

# Beleuchtung & Animationen

## NeoPixel-Helligkeit

Ein kurzer Druck auf LIGHT schaltet die Hintergrundbeleuchtung durch vier Helligkeitsstufen. Die Einstellung wird dauerhaft gespeichert.

Stufe | Beschreibung
1 | Sehr dim – minimale Hintergrundbeleuchtung
2 | Dim – dezente Beleuchtung
3 | Hell – angenehme Raumbeleuchtung
4 | Voll (Standard) – maximale Helligkeit

## Animationsmodi

Modus | Beschreibung
Rainbow | Farbverlauf wandert kontinuierlich über die 6 Hintergrund-LEDs
Statisch Warmweiß | Alle Hintergrund-LEDs leuchten in warmweißem Orange
Puls | Sinusförmiges Auf- und Abdimmen der gesamten Beleuchtung

## Slot-Animation & Datumsanzeige

Das Slot-Intervall bestimmt, wie häufig die Slot-Machine-Animation automatisch ausgelöst wird. Es ist unabhängig vom Animationsmodus einstellbar (aus, 10 Sek., 1 Min., 15 Min., 1 Std.). Im Anschluss an jede Slot-Animation zeigt die Uhr 5 Sekunden lang das Datum im Format TT MM JJ auf den Röhren an. Die Geschwindigkeit, mit der die Ziffern beim Rollen wechseln, lässt sich im Web-Interface stufenlos einstellen.

Während der Datumsanzeige leuchten ausschließlich die unteren Trennpunkt-LEDs in gedämpftem Warmweiß — alle Hintergrund-LEDs und die oberen Trennpunkte sind ausgeschaltet. Dieser Effekt hebt die Datumsanzeige optisch deutlich von der Uhrzeitanzeige ab.

## Weicher Ziffernwechsel

Statt hart umzuschalten, können die Röhren beim Ziffernwechsel sanft überblenden — kurz abdunkeln und mit der neuen Ziffer wieder aufhellen. Das lässt sich getrennt für zwei Situationen im Web-Interface unter Weicher Ziffernwechsel ein- und ausschalten: für den ganz normalen Sekundentakt und für den Wechsel zwischen Uhrzeit- und Datumsanzeige.

Bei Uhren mit der optionalen Pro-Röhre-Dimmoption (siehe Kapitel „Technische Daten") blendet dabei nur die Röhre ab, deren Ziffer sich tatsächlich ändert — unveränderte Ziffern bleiben durchgehend hell. Ohne diese Nachrüstung dimmen weiterhin alle Röhren gemeinsam.

## Trennpunkt-LEDs

Die vier LEDs zwischen den Zifferngruppen blinken standardmäßig sekundengenau. Ein langer Druck auf LIGHT schaltet sie in den Dauerleucht-Modus:

Modus | Beschreibung
Blinken (Standard) | LEDs blinken sekundengenau im Takt der Uhr
Dauerhaft an | LEDs leuchten durchgehend ohne zu blinken

Nixie Clock Ultra · Bedienungsanleitung ⚙ 9

Kapitel VI

# IR-Fernbedienung

Die Uhr lässt sich mit jeder handelsüblichen Infrarot-Fernbedienung steuern (NEC, Samsung, Sony, RC5 u.v.m.). Jede Taste kann frei einer der acht Funktionen zugewiesen werden.

## Verfügbare Funktionen

Funktion | Beschreibung
SET | Einstellmodus starten / nächste Stelle / Zeit speichern
UP | Wert erhöhen im Einstellmodus
DOWN | Wert verringern im Einstellmodus
BRIGHTNESS | Helligkeit weiterschalten (4 Stufen)
ANIM_NEXT | Nächsten Animationsmodus aktivieren
SLOT | Slot-Machine-Animation auslösen
COLON_TOGGLE | Trennpunkt-LEDs dauerhaft an/aus
DATUM | Datumsanzeige für 5 Sekunden einblenden

## Fernbedienung anlernen

Das Anlernen erfolgt über das Web-Interface unter IR-Fernbedienung:

1

Auf Anlernen neben der gewünschten Funktion klicken.

2

Die Zeile blinkt orange und zeigt »Taste auf Fernbedienung drücken…«

3

Beliebige Taste auf der Fernbedienung drücken → Code wird sofort gespeichert.

Nach 10 Sekunden ohne Eingabe bricht der Anlernmodus automatisch ab. Ein bestehender Code kann durch Klick auf ✕ gelöscht werden. Repeat-Codes (automatische Wiederholung der Fernbedienung) werden herausgefiltert.

Nixie Clock Ultra · Bedienungsanleitung ⚙ 11

Kapitel VII

# WLAN & Web-Interface

## Verbindung herstellen

Das Web-Interface ist ohne weitere Konfiguration sofort erreichbar:

SSID (Hotspot) | NixieClockCS
Passwort | nixie1234
IP-Adresse | 192.168.4.1
mDNS (im Heimnetz) | http://nixieclockcs.local

1

Mit dem WLAN NixieClockCS verbinden.

2

Browser öffnen und http://192.168.4.1 aufrufen.

## Heimnetz einrichten

1

SSID des Heimnetzes und Passwort eingeben.

2

Verbinden klicken → Uhr startet automatisch neu.

Nach dem Neustart ist die Uhr erreichbar. Heimnetz trennen: SSID-Feld leer lassen und Verbinden klicken.

## Web-Interface Funktionen

Funktion | Beschreibung
Zeit & Datum stellen | Stunden/Minuten/Sekunden und Tag/Monat/Jahr manuell eingeben oder Browser-Zeit übernehmen
NeoPixel-Helligkeit | Feinstufenregler 10–255 (die 4 Grundstufen werden weiterhin per Taster oder IR-Fernbedienung durchgeschaltet)
Animation | Animationsmodus (Rainbow / Warmweiß / Puls) und Slot-Intervall
Trennpunkte | Blinken, dauerhaft an, oder statisch warmweiß
Nacht-Modus | Zeitbereich und/oder Lichtsensor konfigurieren (siehe Kapitel VIII)
IR-Fernbedienung | 8 Funktionen anlernen und löschen (siehe Kapitel VI)
WLAN-Einrichtung | Heimnetz verbinden oder trennen

## Netzwerk-Zeitsynchronisierung

Sobald die Uhr mit einem Heimnetz verbunden ist, synchronisiert sie Uhrzeit und Datum einmalig automatisch über das Netz (NTP) (pool.ntp.org). Die Zeitzone ist auf Mitteleuropa (CET/CEST) voreingestellt.

## Röhrentest

Über die Schaltfläche Röhrentest zeigen alle 6 Röhren nacheinander gemeinsam jede Ziffer von 0 bis 9 an — praktisch, um nach dem Aufbau oder bei Verdacht auf eine defekte Stelle jede Ziffer auf jeder Röhre einmal zu prüfen. Der Durchlauf dauert rund 20 Sekunden und lässt sich über dieselbe Schaltfläche jederzeit abbrechen.

Nixie Clock Ultra · Bedienungsanleitung ⚙ 13

Kapitel VIII

# Nacht-Modus

Der Nacht-Modus dimmt oder schaltet Nixie-Röhren und Beleuchtung automatisch ab — entweder innerhalb eines festgelegten Zeitfensters oder in Abhängigkeit vom Umgebungslicht. Die Konfiguration erfolgt im Web-Interface unter Nacht-Modus.

## Helligkeitsstufen

Modus | Nixie-Röhren | NeoPixel
Normal | Volle Helligkeit (Einstellung) | Volle Helligkeit (Einstellung)
Gedimmt | 2–60 % einstellbar (Standard 25 %) | 15 % der eingestellten Helligkeit
Dunkel | Vollständig aus | Vollständig aus

## Zeitbereich

Innerhalb eines konfigurierbaren Zeitfensters wechselt die Uhr automatisch in den gewählten Modus (Gedimmt oder Dunkel):

Einstellung | Beschreibung
Zeitbereich aktiv | Zeitgesteuerten Nacht-Modus ein- oder ausschalten
Von / Bis | Start- und Endzeit (ganze Stunden 0–23). Mitternachtsübergang möglich, z. B. Von 23 Bis 7
Modus | Gedimmt oder Dunkel

## Lichtsensor

Der eingebaute Lichtsensor misst kontinuierlich die Umgebungshelligkeit. Fällt der Messwert unter den eingestellten Schwellwert, wechselt die Uhr automatisch in den Modus Gedimmt:

Einstellung | Beschreibung
Lichtsensor aktiv | Helligkeitsgesteuerten Nacht-Modus ein- oder ausschalten
Schwellwert (0–4095) | Grenzwert für den Sensorwert. Höherer Wert = Dimmen beginnt früher
Umgebungshelligkeit | Aktueller Messwert des Sensors (wird sekündlich aktualisiert)

Priorität: Der Zeitbereich hat Vorrang vor dem Lichtsensor. Greift ein konfiguriertes Zeitfenster, bleibt der Lichtsensor wirkungslos — unabhängig vom gemessenen Umgebungslicht. Der Lichtsensor ist nur im Modus Gedimmt wirksam; in den Dunkel-Modus kann er nicht schalten.

Nixie Clock Ultra · Bedienungsanleitung ⚙ 14

Kapitel IX

# Einstellungen & Persistenz

Folgende Einstellungen werden dauerhaft im Flash-Speicher des ESP32-S3 gespeichert und nach jedem Neustart automatisch wiederhergestellt:

Einstellung | Gespeicherter Wert
NeoPixel-Helligkeit | Stufe (1–4) und Feinwert (10–255)
Animationsmodus | Rainbow / Statisch Warmweiß / Puls
Slot-Intervall | Aus / 10 Sek. / 1 Min. / 15 Min. / 1 Std., inkl. Rollgeschwindigkeit
Weicher Ziffernwechsel | Sekundentakt und Zeit/Datum-Wechsel, je einzeln ein-/ausschaltbar
Trennpunkt-LEDs | Blinken, dauerhaft an oder statisch warmweiß
Nacht-Modus | Zeitbereich (Von/Bis/Modus), Dimm-Helligkeit (2–60 %) und Lichtsensor (aktiv/Schwellwert)
WLAN-Zugangsdaten | SSID und Passwort des Heimnetzes
IR-Codes | Alle 8 angelernten Funktionen

Uhrzeit und Datum werden in dem batteriegepufferten Uhr-Chip gespeichert und bleiben auch bei Stromausfall erhalten — vorausgesetzt, die Batterie (CR2032) ist nicht leer.

Nixie Clock Ultra · Bedienungsanleitung ⚙ 15

Kapitel X

# Technische Daten

Eigenschaft | Wert
Mikrocontroller | ESP32-S3
Nixie-Ansteuerung | 4× MCP23017 I²C Port-Expander (0x20–0x23), direkte Ansteuerung ohne Multiplexing
Nixie-Röhren | 6 Stück
Nixie-Hochspannung | 170–180 V DC
Anoden-Dimmung | TLP627-Optokoppler, Hardware-PWM ≈200 Hz (LEDC), GPIO7 (Standard); optional 6× TLP627 für unabhängiges Pro-Röhre-Dimmen, GPIO 15/16/17/18/38/47
Echtzeituhr | DS1302 (ThreeWire-Interface, batteriegepuffert)
NeoPixel | 10× WS2812B (6 Hintergrund + 4 Trennpunkte), GPIO21
IR-Empfänger | VS1838 (38 kHz), GPIO48
Lichtsensor | LDR an GPIO6 (ADC1), Spannungsteiler gegen GND
I²C-Bus | SDA = GPIO8, SCL = GPIO9
Taster | SET = GPIO13, UP = GPIO12, DOWN = GPIO11, LIGHT = GPIO10
Versorgungsspannung | 5 V (Logik) + HV-Netzteil für Nixies
Web-Interface | HTTP Port 80, AP + STA Dual-Mode, mDNS nixieclockcs.local
NTP-Zeitzone | CET-1CEST (Mitteleuropa, automatische Sommerzeit)

Nixie Clock Ultra · Version 2.1 · Juni 2026

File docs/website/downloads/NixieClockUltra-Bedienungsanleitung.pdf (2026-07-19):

# NIXIE CLOCK ULTRA

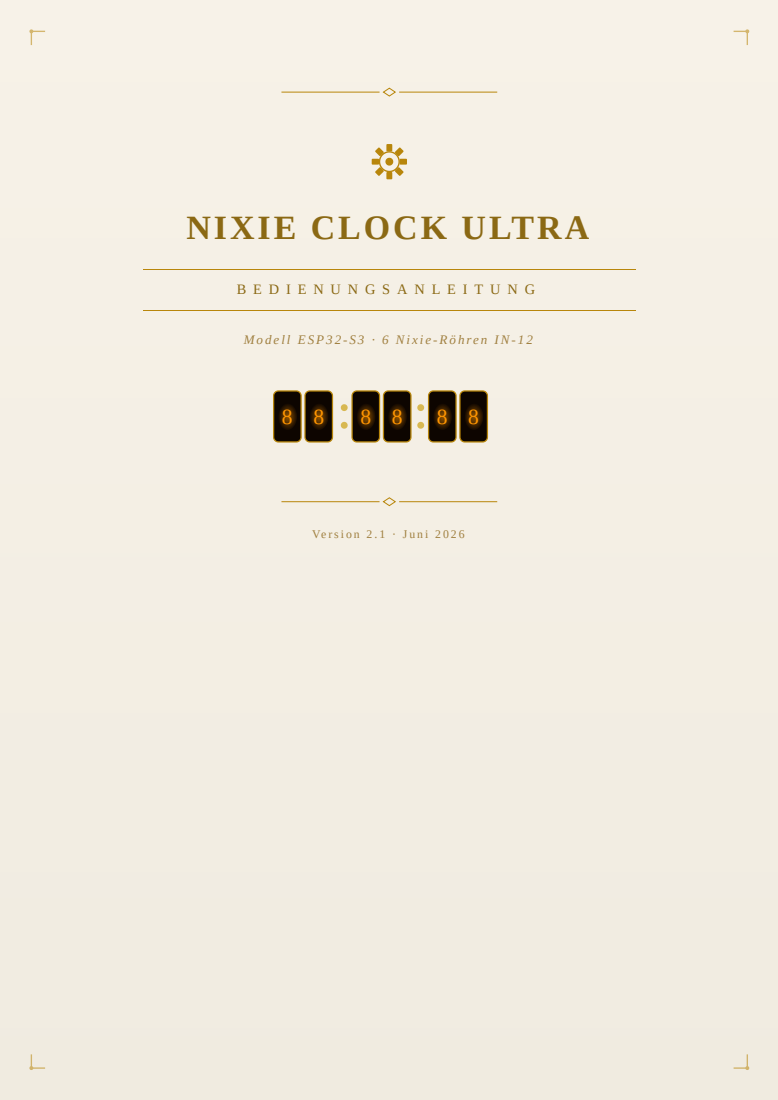
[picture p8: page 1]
Ve rsi o n 2 . 1 · J u n i 2 0 2 6

M o d e l l ESP3 2 - S 3 · 6 Ni x i e -Rö h r e n IN- 1 2

I N H A L T

I. | Übersicht & Sicherheit | 3
II. | Inbetriebnahme | 4
III. | Tasten & Bedienung | 5
IV. | Zeit & Datum einstellen | 6
V. | Beleuchtung & Animationen | 7
VI. | IR-Fernbedienung | 9
VII. | WLAN & Web-Interface | 11
VIII. Nacht-Modus | 13
IX. | Einstellungen & Persistenz | 14
X. | Technische Daten | 15

Nixie Clock Ultra · Bedienungsanleitung | ⚙ 3

K A P I T E L I

# Übersicht & Sicherheit

Die Nixie Clock Ultra ist eine Röhrenuhr auf Basis des ESP32-S3 mit 6 Nixie-Röhren IN-12, 10 NeoPixel-LEDs, einem Web-Interface sowie einem IR-Empfänger. Die Röhren zeigen die aktuelle Uhrzeit in direkter Ansteuerung ohne Multiplexing — für maximale Helligkeit und ghostingfreie Darstellung.

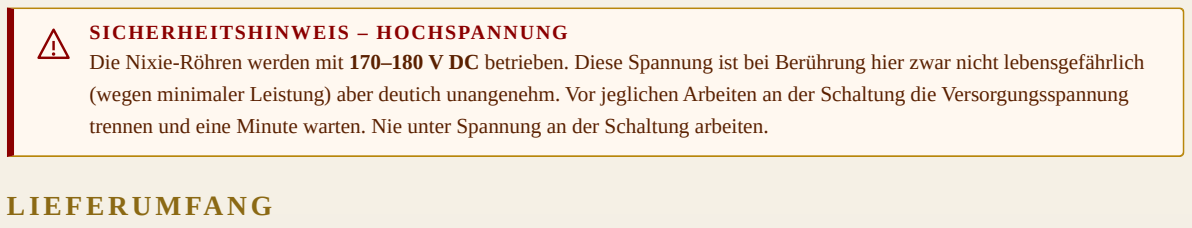
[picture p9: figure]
SICHERHEITSHINWEIS – HOCHSPANNUNG; LIEFERUMFANG

Die Nixie-Röhren werden mit 170–180 V DC betrieben. Diese Spannung ist bei Berührung hier zwar nicht lebensgefährlich (wegen minimaler Leistung) aber deutich unangenehm. Vor jeglichen Arbeiten an der Schaltung die Versorgungsspannung trennen und eine Minute warten. Nie unter Spannung an der Schaltung arbeiten.

Die Uhr wird betriebsbereit geliefert. Eine Infrarot-Fernbedienung ist nicht im Lieferumfang enthalten — jede handelsübliche IR-Fernbedienung (NEC, Samsung, Sony, RC5 u.v.m.) kann angelernt werden.

K A P I T E L I I

# Inbetriebnahme

Die Uhr ist nach dem Anschließen an die Spannungsversorgung (USB 5 Volt) sofort betriebsbereit.

1 | Spannungsversorgung anschließen. Die Nixie-Röhren starten mit einem sanften Fade-In der NeoPixel- Beleuchtung.
2 | Die Uhr zeigt sofort die im internen Uhr-Chip gespeicherte Uhrzeit an — auch ohne WLAN-Verbindung.
3 | Alle gespeicherten Einstellungen (Helligkeit, Animation, IR-Codes, WLAN-Zugangsdaten, Nacht-Modus) werden automatisch geladen.
4 | Der WLAN-Hotspot NixieClockCS (Passwort: nixie1234) ist sofort aktiv und unter 192.168.4.1 erreichbar. Im Heimnetz zusätzlich über http://nixieclockcs.local.
| Ist die Uhrzeit nach dem ersten Start falsch, wurde der interne Uhr-Chip noch nicht eingestellt. Zeit und Datum lassen sich per Tastendruck (Kapitel IV) oder bequem über das Web-Interface (Kapitel VII) korrigieren. Sobald die Uhr mit einem Heimnetz verbunden ist, synchronisiert sie Uhrzeit und Datum automatisch mit einem Zeitserver.

K A P I T E L I I I

# Tasten & Bedienung

Das Gehäuse beherbergt vier Drucktaster, die alle wesentlichen Einstellungen direkt am Gerät ermöglichen. Jede Taste reagiert auf kurzen und — wo angegeben — auf langen Druck (≥ 600 ms gehalten).

Taste | Kurzer Druck | Langer Druck
SET | Einstellmodus starten · nächste Stelle (Zeit/Datum) · Speichern | —
UP | Wert erhöhen | Wert erhöhen (Auto-Repeat)
DOWN | Wert verringern | Wert verringern (Auto-Repeat)
LIGHT | Helligkeit weiterschalten (4 Stufen) | Trennpunkt-LEDs dauerhaft an/aus

Alle Tasteneinstellungen wirken sofort und werden dauerhaft gespeichert. Dieselben Funktionen stehen alternativ über die IR-Fernbedienung (Kapitel VI) und das Web-Interface (Kapitel VII) zur Verfügung.

K A P I T E L I V

# Zeit & Datum einstellen

Uhrzeit und Datum lassen sich direkt am Gerät per Tastendruck einstellen. Die blinkende Stelle zeigt an, welcher Wert gerade bearbeitet wird. Der vollständige Durchlauf umfasst sieben SET-Drücke für alle sechs Felder.

EINSTELLREIHENFOLGE

1 | SET drücken → Stunden blinken auf.
2 | Mit UP / DOWN die Stunden einstellen (0–23). Langer Druck aktiviert Auto-Repeat.
3 | SET drücken → Minuten blinken auf. Einstellen (0–59).
4 | SET drücken → Sekunden blinken auf. Einstellen (0–59).
5 | SET drücken → Tag blinkt auf. Einstellen (1–31). Die Anzeige wechselt in das Datumsformat TT MM JJ.
6 | SET drücken → Monat blinkt auf. Einstellen (1–12).
7 | SET drücken → Jahr (2-stellig) blinkt auf. Einstellen (00–99).
8 | SET drücken → alle Werte werden in der RTC gespeichert, Normalanzeige kehrt zurück.
| Abkürzung: Wer nur die Uhrzeit korrigieren möchte, kann nach Schritt 4 (Sekunden) einfach 15 Sekunden warten — der Einstellmodus beendet sich automatisch und speichert die bisherigen Werte.
| Netzwerk-Zeit (NTP): Sobald die Uhr mit dem Heimnetz verbunden ist, werden Uhrzeit und Datum automatisch synchronisiert — eine manuelle Eingabe ist dann nicht erforderlich.

K A P I T E L V

# Beleuchtung & Animationen

NEOPIXEL-HELLIGKEIT

Ein kurzer Druck auf LIGHT schaltet die Hintergrundbeleuchtung durch vier Helligkeitsstufen. Die Einstellung wird dauerhaft gespeichert.

Stufe | Beschreibung

1 Sehr dim – minimale Hintergrundbeleuchtung

2 Dim – dezente Beleuchtung

3 Hell – angenehme Raumbeleuchtung

4 Voll (Standard) – maximale Helligkeit

ANIMATIONSMODI

Modus | Beschreibung
Rainbow | Farbverlauf wandert kontinuierlich über die 6 Hintergrund-LEDs
Statisch Warmweiß | Alle Hintergrund-LEDs leuchten in warmweißem Orange
Puls | Sinusförmiges Auf- und Abdimmen der gesamten Beleuchtung

SLOT-ANIMATION & DATUMSANZEIGE

Das Slot-Intervall bestimmt, wie häufig die Slot-Machine-Animation automatisch ausgelöst wird. Es ist unabhängig vom Animationsmodus einstellbar (aus, 10 Sek., 1 Min., 15 Min., 1 Std.). Im Anschluss an jede Slot-Animation zeigt die Uhr 5 Sekunden lang das Datum im Format TT MM JJ auf den Röhren an. Die Geschwindigkeit, mit der die Ziffern beim Rollen wechseln, lässt sich im Web-Interface stufenlos einstellen.

Während der Datumsanzeige leuchten ausschließlich die unteren Trennpunkt-LEDs in gedämpftem Warmweiß — alle Hintergrund-LEDs und die oberen Trennpunkte sind ausgeschaltet. Dieser Effekt hebt die Datumsanzeige optisch deutlich von der Uhrzeitanzeige ab.

WEICHER ZIFFERNWECHSEL

Statt hart umzuschalten, können die Röhren beim Ziffernwechsel sanft überblenden — kurz abdunkeln und mit der neuen Ziffer wieder aufhellen. Das lässt sich getrennt für zwei Situationen im Web-Interface unter Weicher Ziffernwechsel ein- und ausschalten: für den ganz normalen Sekundentakt und für den Wechsel zwischen Uhrzeit- und Datumsanzeige.

TRENNPUNKT-LEDS

Die vier LEDs zwischen den Zifferngruppen blinken standardmäßig sekundengenau. Ein langer Druck auf LIGHT schaltet sie in den Dauerleucht-Modus:

Modus | Beschreibung
Blinken (Standard) | LEDs blinken sekundengenau im Takt der Uhr
Dauerhaft an | LEDs leuchten durchgehend ohne zu blinken

K A P I T E L V I

# IR-Fernbedienung

Die Uhr lässt sich mit jeder handelsüblichen Infrarot-Fernbedienung steuern (NEC, Samsung, Sony, RC5 u.v.m.). Jede Taste kann frei einer der acht Funktionen zugewiesen werden.

VERFÜGBARE FUNKTIONEN

Funktion | Beschreibung
SET | Einstellmodus starten / nächste Stelle / Zeit speichern
UP | Wert erhöhen im Einstellmodus
DOWN | Wert verringern im Einstellmodus
BRIGHTNESS | Helligkeit weiterschalten (4 Stufen)
ANIM_NEXT | Nächsten Animationsmodus aktivieren
SLOT | Slot-Machine-Animation auslösen
COLON_TOGGLE | Trennpunkt-LEDs dauerhaft an/aus
DATUM | Datumsanzeige für 5 Sekunden einblenden

FERNBEDIENUNG ANLERNEN

Das Anlernen erfolgt über das Web-Interface unter IR-Fernbedienung:

1 | Auf Anlernen neben der gewünschten Funktion klicken.
2 | Die Zeile blinkt orange und zeigt »Taste auf Fernbedienung drücken…«
3 | Beliebige Taste auf der Fernbedienung drücken → Code wird sofort gespeichert.
| Nach 10 Sekunden ohne Eingabe bricht der Anlernmodus automatisch ab. Ein bestehender Code kann durch Klick auf ✕ gelöscht werden. Repeat-Codes (automatische Wiederholung der Fernbedienung) werden herausgefiltert.

K A P I T E L V I I

# WLAN & Web-Interface

VERBINDUNG HERSTELLEN

Das Web-Interface ist ohne weitere Konfiguration sofort erreichbar:

SSID (Hotspot) | NixieClockCS
Passwort | nixie1234
IP-Adresse | 192.168.4.1
mDNS (im Heimnetz) | http://nixieclockcs.local
1 | Mit dem WLAN NixieClockCS verbinden.
2 | Browser öffnen und http://192.168.4.1 aufrufen.

HEIMNETZ EINRICHTEN

1 | SSID des Heimnetzes und Passwort eingeben.
2 | Verbinden klicken → Uhr startet automatisch neu.

Nach dem Neustart ist die Uhr erreichbar. Heimnetz trennen: SSID-Feld leer lassen und Verbinden klicken.

WEB-INTERFACE FUNKTIONEN

Funktion | Beschreibung
Zeit & Datum stellen | Stunden/Minuten/Sekunden und Tag/Monat/Jahr manuell eingeben oder Browser-Zeit übernehmen
NeoPixel-Helligkeit | Feinstufenregler 10–255 (die 4 Grundstufen werden weiterhin per Taster oder IR-Fernbedienung durchgeschaltet)
Animation | Animationsmodus (Rainbow / Warmweiß / Puls) und Slot-Intervall
Trennpunkte | Blinken, dauerhaft an, oder statisch warmweiß
Nacht-Modus | Zeitbereich und/oder Lichtsensor konfigurieren (siehe Kapitel VIII)
IR-Fernbedienung | 8 Funktionen anlernen und löschen (siehe Kapitel VI)
WLAN-Einrichtung | Heimnetz verbinden oder trennen

NETZWERK-ZEITSYNCHRONISIERUNG

Sobald die Uhr mit einem Heimnetz verbunden ist, synchronisiert sie Uhrzeit und Datum einmalig automatisch über das Netz (NTP) (pool.ntp.org). Die Zeitzone ist auf Mitteleuropa (CET/CEST) voreingestellt.

RÖHRENTEST

Über die Schaltfläche Röhrentest zeigen alle 6 Röhren nacheinander gemeinsam jede Ziffer von 0 bis 9 an — praktisch, um nach dem Aufbau oder bei Verdacht auf eine defekte Stelle jede Ziffer auf jeder Röhre einmal zu prüfen. Der Durchlauf dauert rund 20 Sekunden und lässt sich über dieselbe Schaltfläche jederzeit abbrechen.

K A P I T E L V I I I

# Nacht-Modus

Der Nacht-Modus dimmt oder schaltet Nixie-Röhren und Beleuchtung automatisch ab — entweder innerhalb eines festgelegten Zeitfensters oder in Abhängigkeit vom Umgebungslicht. Die Konfiguration erfolgt im Web-Interface unter Nacht-Modus.

HELLIGKEITSSTUFEN

Modus | Nixie-Röhren | NeoPixel
Normal | Volle Helligkeit (Einstellung) | Volle Helligkeit (Einstellung)
Gedimmt | 2–60 % einstellbar (Standard 25 %) | 15 % der eingestellten Helligkeit
Dunkel | Vollständig aus | Vollständig aus

ZEITBEREICH

Innerhalb eines konfigurierbaren Zeitfensters wechselt die Uhr automatisch in den gewählten Modus (Gedimmt oder Dunkel):

Einstellung | Beschreibung
Zeitbereich aktiv | Zeitgesteuerten Nacht-Modus ein- oder ausschalten
Von / Bis | Start- und Endzeit (ganze Stunden 0–23). Mitternachtsübergang möglich, z. B. Von 23 Bis 7
Modus | Gedimmt oder Dunkel

LICHTSENSOR

Der eingebaute Lichtsensor misst kontinuierlich die Umgebungshelligkeit. Fällt der Messwert unter den eingestellten Schwellwert, wechselt die Uhr automatisch in den Modus Gedimmt:

Einstellung | Beschreibung
Lichtsensor aktiv | Helligkeitsgesteuerten Nacht-Modus ein- oder ausschalten
Schwellwert (0–4095) | Grenzwert für den Sensorwert. Höherer Wert = Dimmen beginnt früher
Umgebungshelligkeit | Aktueller Messwert des Sensors (wird sekündlich aktualisiert)

Priorität: Der Zeitbereich hat Vorrang vor dem Lichtsensor. Greift ein konfiguriertes Zeitfenster, bleibt der Lichtsensor wirkungslos — unabhängig vom gemessenen Umgebungslicht. Der Lichtsensor ist nur im Modus Gedimmt wirksam; in den Dunkel-Modus kann er nicht schalten.

K A P I T E L I X

# Einstellungen & Persistenz

Folgende Einstellungen werden dauerhaft im Flash-Speicher des ESP32-S3 gespeichert und nach jedem Neustart automatisch wiederhergestellt:

Einstellung | Gespeicherter Wert
NeoPixel-Helligkeit | Stufe (1–4) und Feinwert (10–255)
Animationsmodus | Rainbow / Statisch Warmweiß / Puls
Slot-Intervall | Aus / 10 Sek. / 1 Min. / 15 Min. / 1 Std., inkl. Rollgeschwindigkeit
Weicher Ziffernwechsel | Sekundentakt und Zeit/Datum-Wechsel, je einzeln ein-/ausschaltbar
Trennpunkt-LEDs | Blinken, dauerhaft an oder statisch warmweiß
Nacht-Modus | Zeitbereich (Von/Bis/Modus), Dimm-Helligkeit (2–60 %) und Lichtsensor (aktiv/Schwellwert)
WLAN-Zugangsdaten | SSID und Passwort des Heimnetzes
IR-Codes | Alle 8 angelernten Funktionen

Uhrzeit und Datum werden in dem batteriegepufferten Uhr-Chip gespeichert und bleiben auch bei Stromausfall erhalten — vorausgesetzt, die Batterie (CR2032) ist nicht leer.

K A P I T E L X

# Technische Daten

Eigenschaft | Wert
Mikrocontroller | ESP32-S3
Nixie-Ansteuerung | 4× MCP23017 I²C Port-Expander (0x20–0x23), direkte Ansteuerung ohne Multiplexing
Nixie-Röhren | 6 Stück
Nixie-Hochspannung | 170–180 V DC
Anoden-Dimmung | TLP627-Optokoppler, Hardware-PWM ≈200 Hz (LEDC), GPIO7
Echtzeituhr | DS1302 (ThreeWire-Interface, batteriegepuffert)
NeoPixel | 10× WS2812B (6 Hintergrund + 4 Trennpunkte), GPIO21
IR-Empfänger | VS1838 (38 kHz), GPIO48
Lichtsensor | LDR an GPIO6 (ADC1), Spannungsteiler gegen GND
I²C-Bus | SDA = GPIO8, SCL = GPIO9
Taster | SET = GPIO13, UP = GPIO12, DOWN = GPIO11, LIGHT = GPIO10
Versorgungsspannung | 5 V (Logik) + HV-Netzteil für Nixies
Web-Interface | HTTP Port 80, AP + STA Dual-Mode, mDNS nixieclockcs.local
NTP-Zeitzone | CET-1CEST (Mitteleuropa, automatische Sommerzeit)

N i x i e C l o c k U l tr a · Ve rsi o n 2 . 1 · J u n i 2 0 2 6

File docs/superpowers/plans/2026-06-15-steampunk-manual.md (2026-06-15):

# Steampunk Bedienungsanleitung – Implementation Plan

> **For agentic workers:** REQUIRED SUB-SKILL: Use superpowers:subagent-driven-development (recommended) or superpowers:executing-plans to implement this plan task-by-task. Steps use checkbox (`- [ ]`) syntax for tracking.

**Goal:** Einzelne selbst-enthaltene HTML-Datei erzeugen, die die vollständige Bedienungsanleitung der Nixie Clock Ultra im Steampunk-Stil (Elegant & Zeitlos) darstellt und per Browser-Druck (Strg+P → Als PDF speichern) als druckfertiges A4-PDF exportiert werden kann.

**Architecture:** Eine einzige HTML-Datei mit eingebetteten CSS-Custom-Properties, inline SVG-Dekorationen (keine externen Abhängigkeiten), @media print-Regeln für A4-Paginierung und seitenweise `<div class="page">`-Blöcke. Kein JavaScript, keine externen Fonts, keine Bilder.

**Tech Stack:** HTML5, CSS3 (Custom Properties, @media print, @page), inline SVG

---

## Dateistruktur

| Datei | Aktion | Beschreibung |
|---|---|---|
| `docs/manual/nixie-clock-ultra-bedienungsanleitung.html` | Neu erstellen | Vollständiges HTML-Dokument |

---

## Wiederverwendete SVG-Snippets (Referenz für alle Tasks)

Diese SVG-Bausteine werden in mehreren Tasks verwendet. Hier zentral definiert:

**Corner-Ornament oben-links** (analog für TR/BL/BR mit gespiegelten Koordinaten):
```html
<svg class="corner-tl" width="36" height="36" viewBox="0 0 36 36">
  <path d="M2,2 L2,16 M2,2 L16,2" stroke="#b8860b" stroke-width="1.4" fill="none"/>
  <circle cx="2" cy="2" r="2" fill="#b8860b"/>
</svg>
<svg class="corner-tr" width="36" height="36" viewBox="0 0 36 36">
  <path d="M34,2 L34,16 M34,2 L20,2" stroke="#b8860b" stroke-width="1.4" fill="none"/>
  <circle cx="34" cy="2" r="2" fill="#b8860b"/>
</svg>
<svg class="corner-bl" width="36" height="36" viewBox="0 0 36 36">
  <path d="M2,34 L2,20 M2,34 L16,34" stroke="#b8860b" stroke-width="1.4" fill="none"/>
  <circle cx="2" cy="34" r="2" fill="#b8860b"/>
</svg>
<svg class="corner-br" width="36" height="36" viewBox="0 0 36 36">
  <path d="M34,34 L34,20 M34,34 L20,34" stroke="#b8860b" stroke-width="1.4" fill="none"/>
  <circle cx="34" cy="34" r="2" fill="#b8860b"/>
</svg>
```

**Ornamentlinie (groß):**
```html
<svg class="ornament-line" width="220" height="14" viewBox="0 0 220 14">
  <line x1="0" y1="7" x2="88" y2="7" stroke="#b8860b" stroke-width="1"/>
  <polygon points="100,7 106,3 112,7 106,11" fill="none" stroke="#b8860b" stroke-width="1"/>
  <line x1="122" y1="7" x2="220" y2="7" stroke="#b8860b" stroke-width="1"/>
</svg>
```

**Ornamentlinie (klein, Fußlinie):**
```html
<svg class="ornament-small" width="80" height="10" viewBox="0 0 80 10">
  <line x1="0" y1="5" x2="28" y2="5" stroke="#b8860b" stroke-width="0.8"/>
  <circle cx="40" cy="5" r="3" fill="none" stroke="#b8860b" stroke-width="0.8"/>
  <line x1="52" y1="5" x2="80" y2="5" stroke="#b8860b" stroke-width="0.8"/>
</svg>
```

**Zahnrad-Icon (Kapitelheader):**
```html
<svg width="30" height="30" viewBox="0 0 30 30" style="flex-shrink:0">
  <g transform="translate(15,15)">
    <circle r="5.5" fill="var(--pg-light)" stroke="var(--gold)" stroke-width="1.1"/>
    <circle r="2.2" fill="var(--gold)"/>
    <rect x="-1.8" y="-10" width="3.6" height="4.5" rx="0.6" fill="var(--gold)" transform="rotate(0)"/>
    <rect x="-1.8" y="-10" width="3.6" height="4.5" rx="0.6" fill="var(--gold)" transform="rotate(45)"/>
    <rect x="-1.8" y="-10" width="3.6" height="4.5" rx="0.6" fill="var(--gold)" transform="rotate(90)"/>
    <rect x="-1.8" y="-10" width="3.6" height="4.5" rx="0.6" fill="var(--gold)" transform="rotate(135)"/>
    <rect x="-1.8" y="-10" width="3.6" height="4.5" rx="0.6" fill="var(--gold)" transform="rotate(180)"/>
    <rect x="-1.8" y="-10" width="3.6" height="4.5" rx="0.6" fill="var(--gold)" transform="rotate(225)"/>
    <rect x="-1.8" y="-10" width="3.6" height="4.5" rx="0.6" fill="var(--gold)" transform="rotate(270)"/>
    <rect x="-1.8" y="-10" width="3.6" height="4.5" rx="0.6" fill="var(--gold)" transform="rotate(315)"/>
  </g>
</svg>
```

**Warn-Dreieck:**
```html
<svg width="20" height="20" viewBox="0 0 20 20" style="flex-shrink:0;margin-top:2px">
  <polygon points="10,2 18,17 2,17" fill="none" stroke="#8b0000" stroke-width="1.3" stroke-linejoin="round"/>
  <line x1="10" y1="8" x2="10" y2="13" stroke="#8b0000" stroke-width="1.3"/>
  <circle cx="10" cy="15" r="0.9" fill="#8b0000"/>
</svg>
```

**Laufender Kopfbereich (alle Kapitelseiten):**
```html
<div class="running-header">
  <span>Nixie Clock Ultra · Bedienungsanleitung</span>
  <span>⚙ [SEITENNUMMER]</span>
</div>
```

**Kapitelheader-Block:**
```html
<div class="chapter-title">
  [Zahnrad-SVG]
  <div>
    <div class="chapter-label">Kapitel [RÖMISCH]</div>
    <h1>[TITEL]</h1>
  </div>
</div>

```

---

## Task 1: HTML-Grundgerüst & vollständiges CSS

**Files:**
- Erstellen: `docs/manual/nixie-clock-ultra-bedienungsanleitung.html`

- [ ] **Schritt 1.1: Datei mit HTML-Skeleton und CSS anlegen**

Erstelle `docs/manual/nixie-clock-ultra-bedienungsanleitung.html` mit folgendem Inhalt:

```html
<!DOCTYPE html>
<html lang="de">
<head>
<meta charset="UTF-8">
<meta name="viewport" content="width=device-width, initial-scale=1.0">
<title>Nixie Clock Ultra – Bedienungsanleitung</title>
<style>
/* ── Custom Properties ─────────────────────────────────────────── */
:root {
  --pg-light: #f7f2e8;
  --pg-dark:  #f0ebe0;
  --text-h:   #2c1810;
  --text-b:   #3d2b00;
  --gold:     #b8860b;
  --gold-dk:  #8b6914;
  --gold-lt:  #d4af37;
  --red-warn: #8b0000;
  --line:     #d3c9a8;
  --line-med: #c8b878;
  --hdr-txt:  #a08040;
  --warn-bg:  #fff8f0;
}

/* ── Reset ─────────────────────────────────────────────────────── */
*, *::before, *::after { box-sizing: border-box; margin: 0; padding: 0; }

/* ── Body & Screen Layout ──────────────────────────────────────── */
body {
  font-family: Georgia, 'Times New Roman', serif;
  background: #b0a898;
  color: var(--text-b);
}

/* ── Page Block ────────────────────────────────────────────────── */
.page {
  width: 210mm;
  min-height: 297mm;
  margin: 10mm auto;
  background: linear-gradient(180deg, var(--pg-light) 0%, var(--pg-dark) 100%);
  padding: 18mm 22mm 16mm;
  position: relative;
  box-shadow: 0 4px 28px rgba(0,0,0,0.22);
}

/* ── Corner Ornaments ──────────────────────────────────────────── */
.corner-tl { position: absolute; top: 8mm; left: 8mm; opacity: 0.55; }
.corner-tr { position: absolute; top: 8mm; right: 8mm; opacity: 0.55; }
.corner-bl { position: absolute; bottom: 8mm; left: 8mm; opacity: 0.55; }
.corner-br { position: absolute; bottom: 8mm; right: 8mm; opacity: 0.55; }

/* ── Running Header ────────────────────────────────────────────── */
.running-header {
  display: flex;
  justify-content: space-between;
  align-items: center;
  margin-bottom: 10mm;
  padding-bottom: 2.5mm;
  border-bottom: 0.3mm solid var(--line-med);
  font-size: 7.5pt;
  color: var(--hdr-txt);
  font-style: italic;
}

/* ── Chapter Title ─────────────────────────────────────────────── */
.chapter-title {
  display: flex;
  align-items: center;
  gap: 10px;
  margin-bottom: 3mm;
}
.chapter-label {
  font-size: 7.5pt;
  color: var(--gold-dk);
  letter-spacing: 4px;
  text-transform: uppercase;
  margin-bottom: 1mm;
}
.chapter-title h1 {
  font-size: 18pt;
  color: var(--text-h);
  letter-spacing: 0.5px;
  font-weight: bold;
  line-height: 1.2;
}
.chapter-rule {
  height: 0.3mm;
  background: linear-gradient(90deg, var(--gold), transparent);
  margin-bottom: 6mm;
}

/* ── Typography ────────────────────────────────────────────────── */
p  { font-size: 10.5pt; line-height: 1.75; margin-bottom: 3mm; color: var(--text-b); }
h2 { font-size: 11pt; color: var(--gold-dk); letter-spacing: 2px;
     text-transform: uppercase; margin: 5mm 0 2mm; font-weight: bold; }

/* ── Section Label ─────────────────────────────────────────────── */
.section-label {
  font-size: 8.5pt;
  color: var(--gold-dk);
  font-weight: bold;
  letter-spacing: 2px;
  text-transform: uppercase;
  margin: 5mm 0 2mm;
  border-bottom: 0.2mm solid var(--line);
  padding-bottom: 1mm;
}

/* ── Data Table ────────────────────────────────────────────────── */
.data-table { width: 100%; border-collapse: collapse; font-size: 9.5pt; margin: 2mm 0 5mm; }
.data-table thead tr { background: var(--gold-dk); }
.data-table thead th {
  color: var(--pg-light); padding: 5px 9px;
  text-align: left; font-weight: normal; letter-spacing: 0.5px;
}
.data-table tbody tr:nth-child(odd)  { background: var(--pg-light); }
.data-table tbody tr:nth-child(even) { background: var(--pg-dark); }
.data-table tbody td {
  padding: 5px 9px; border-bottom: 0.2mm solid var(--line); color: var(--text-b);
}
.data-table tbody td strong { color: var(--text-h); }
.data-table tbody td em { color: #777; font-style: normal; }

/* ── Warning Box ───────────────────────────────────────────────── */
.warning-box {
  display: flex; gap: 9px; align-items: flex-start;
  border: 0.3mm solid var(--gold);
  border-left: 1.2mm solid var(--red-warn);
  background: var(--warn-bg);
  padding: 7px 11px;
  border-radius: 0 3px 3px 0;
  margin: 4mm 0;
}
.warn-title {
  font-size: 8pt; color: var(--red-warn); font-weight: bold;
  letter-spacing: 1px; text-transform: uppercase; margin-bottom: 2px;
}
.warning-box p { font-size: 8.5pt; color: #5a2000; margin: 0; line-height: 1.5; }

/* ── Numbered Steps ────────────────────────────────────────────── */
.steps { display: flex; flex-direction: column; gap: 2.5mm; margin: 3mm 0 5mm; }
.step  { display: flex; gap: 9px; align-items: flex-start; }
.step-num {
  width: 19px; height: 19px; flex-shrink: 0; border-radius: 50%;
  background: var(--gold-dk); color: var(--pg-light);
  font-size: 8pt; display: flex; align-items: center; justify-content: center;
  margin-top: 1px;
}
.step p { margin: 0; font-size: 10pt; line-height: 1.65; }

/* ── Info Box ──────────────────────────────────────────────────── */
.info-box {
  border: 0.3mm solid var(--gold);
  border-left: 1.2mm solid var(--gold-dk);
  background: #faf7ef;
  padding: 7px 11px;
  border-radius: 0 3px 3px 0;
  margin: 4mm 0;
  font-size: 9.5pt;
  color: var(--text-b);
  line-height: 1.6;
}

/* ── Ornament Lines ────────────────────────────────────────────── */
.ornament-line  { display: block; margin: 5mm auto; }
.ornament-small { display: block; margin: 6mm auto; }

/* ── TOC ───────────────────────────────────────────────────────── */
.toc-heading {
  text-align: center;
  font-size: 10.5pt;
  color: var(--gold-dk);
  letter-spacing: 6px;
  text-transform: uppercase;
  margin-bottom: 6mm;
}
.toc-entry {
  display: flex; align-items: baseline; gap: 4px;
  padding: 5px 0; border-bottom: 0.2mm dotted var(--line-med);
  font-size: 10.5pt;
}
.toc-entry:last-child { border-bottom: none; }
.toc-num   { color: var(--gold-dk); min-width: 32px; font-style: italic; font-size: 9pt; }
.toc-title { color: var(--text-h); flex: 1; }
.toc-page  { color: var(--hdr-txt); font-size: 9pt; text-align: right; min-width: 18px; }

/* ── Connectivity Info Box ─────────────────────────────────────── */
.conn-table { width: 100%; border-collapse: collapse; font-size: 9.5pt; margin: 2mm 0 4mm; }
.conn-table td { padding: 4px 8px; border-bottom: 0.2mm solid var(--line); }
.conn-table td:first-child { color: var(--gold-dk); font-weight: bold; width: 40%; }
.conn-table td:last-child  { color: var(--text-b); font-family: 'Courier New', monospace; font-size: 9pt; }

/* ── Print ─────────────────────────────────────────────────────── */
@media print {
  @page { size: A4 portrait; margin: 0; }
  body  { background: none; }
  .page {
    margin: 0; box-shadow: none;
    width: 100%; min-height: 100vh;
    page-break-after: always;
  }
  .no-break { page-break-inside: avoid; }
  thead { display: table-header-group; }
}
</style>
</head>
<body>

<!-- ═══════════ TITELSEITE ═══════════ -->
<!-- Task 2 -->

<!-- ═══════════ INHALTSVERZEICHNIS ═══════════ -->
<!-- Task 3 -->

<!-- ═══════════ KAPITEL I ═══════════ -->
<!-- Task 4 -->

<!-- ═══════════ KAPITEL II ═══════════ -->
<!-- Task 4 -->

<!-- ═══════════ KAPITEL III ═══════════ -->
<!-- Task 5 -->

<!-- ═══════════ KAPITEL IV ═══════════ -->
<!-- Task 5 -->

<!-- ═══════════ KAPITEL V ═══════════ -->
<!-- Task 6 -->

<!-- ═══════════ KAPITEL VI ═══════════ -->
<!-- Task 7 -->

<!-- ═══════════ KAPITEL VII ═══════════ -->
<!-- Task 8 -->

<!-- ═══════════ KAPITEL VIII ═══════════ -->
<!-- Task 9 -->

<!-- ═══════════ KAPITEL IX ═══════════ -->
<!-- Task 9 -->

</body>
</html>
```

- [ ] **Schritt 1.2: Im Browser prüfen**

Datei öffnen: `docs/manual/nixie-clock-ultra-bedienungsanleitung.html`

Erwartetes Ergebnis: Leere Seite mit Pergament-Hintergrund auf grauem Körper.

- [ ] **Schritt 1.3: Commit**

```bash
git add docs/manual/nixie-clock-ultra-bedienungsanleitung.html
git commit -m "feat: HTML-Grundgerüst und CSS für Steampunk-Bedienungsanleitung"
```

---

## Task 2: Titelseite

**Files:**
- Modify: `docs/manual/nixie-clock-ultra-bedienungsanleitung.html` — `<!-- Task 2 -->` ersetzen

- [ ] **Schritt 2.1: Titelseite einfügen**

Ersetze `<!-- Task 2 -->` durch:

```html
<div class="page">
  <!-- Eckverzierungen -->
  <svg class="corner-tl" width="36" height="36" viewBox="0 0 36 36">
    <path d="M2,2 L2,16 M2,2 L16,2" stroke="#b8860b" stroke-width="1.4" fill="none"/>
    <circle cx="2" cy="2" r="2" fill="#b8860b"/>
  </svg>
  <svg class="corner-tr" width="36" height="36" viewBox="0 0 36 36">
    <path d="M34,2 L34,16 M34,2 L20,2" stroke="#b8860b" stroke-width="1.4" fill="none"/>
    <circle cx="34" cy="2" r="2" fill="#b8860b"/>
  </svg>
  <svg class="corner-bl" width="36" height="36" viewBox="0 0 36 36">
    <path d="M2,34 L2,20 M2,34 L16,34" stroke="#b8860b" stroke-width="1.4" fill="none"/>
    <circle cx="2" cy="34" r="2" fill="#b8860b"/>
  </svg>
  <svg class="corner-br" width="36" height="36" viewBox="0 0 36 36">
    <path d="M34,34 L34,20 M34,34 L20,34" stroke="#b8860b" stroke-width="1.4" fill="none"/>
    <circle cx="34" cy="34" r="2" fill="#b8860b"/>
  </svg>

  <!-- Ornamentlinie oben -->
  <svg class="ornament-line" width="220" height="14" viewBox="0 0 220 14">
    <line x1="0" y1="7" x2="88" y2="7" stroke="#b8860b" stroke-width="1"/>
    <polygon points="100,7 106,3 112,7 106,11" fill="none" stroke="#b8860b" stroke-width="1"/>
    <line x1="122" y1="7" x2="220" y2="7" stroke="#b8860b" stroke-width="1"/>
  </svg>

  <!-- Titelblock -->
  <div style="text-align:center;margin:10mm 0 8mm">
    <!-- Zahnrad -->
    <svg width="52" height="52" viewBox="0 0 52 52" style="display:block;margin:0 auto 6mm">
      <g transform="translate(26,26)">
        <circle r="10" fill="var(--pg-light)" stroke="var(--gold)" stroke-width="1.4"/>
        <circle r="4"  fill="var(--gold)"/>
        <rect x="-3" y="-18" width="6" height="7.5" rx="1" fill="var(--gold)" transform="rotate(0)"/>
        <rect x="-3" y="-18" width="6" height="7.5" rx="1" fill="var(--gold)" transform="rotate(45)"/>
        <rect x="-3" y="-18" width="6" height="7.5" rx="1" fill="var(--gold)" transform="rotate(90)"/>
        <rect x="-3" y="-18" width="6" height="7.5" rx="1" fill="var(--gold)" transform="rotate(135)"/>
        <rect x="-3" y="-18" width="6" height="7.5" rx="1" fill="var(--gold)" transform="rotate(180)"/>
        <rect x="-3" y="-18" width="6" height="7.5" rx="1" fill="var(--gold)" transform="rotate(225)"/>
        <rect x="-3" y="-18" width="6" height="7.5" rx="1" fill="var(--gold)" transform="rotate(270)"/>
        <rect x="-3" y="-18" width="6" height="7.5" rx="1" fill="var(--gold)" transform="rotate(315)"/>
      </g>
    </svg>

    <div style="font-size:26pt;font-weight:bold;color:var(--text-h);letter-spacing:3px;text-transform:uppercase">
      Nixie Clock Ultra
    </div>

    <!-- Doppelgoldlinie mit eingebettetem Text -->
    <div style="margin:6mm auto;width:80%;border-top:0.4mm solid var(--gold);border-bottom:0.4mm solid var(--gold);padding:3mm 0">
      <div style="font-size:11pt;color:var(--gold-dk);letter-spacing:7px;text-transform:uppercase">
        Bedienungsanleitung
      </div>
    </div>

    <div style="font-size:10pt;color:var(--hdr-txt);letter-spacing:2px;font-style:italic">
      Modell ESP32-S3 &middot; 6 Nixie-Röhren
    </div>
  </div>

  <!-- Nixie-Röhren-Illustration -->
  <div style="text-align:center;margin:10mm 0">
    <svg width="240" height="70" viewBox="0 0 240 70">
      <defs>
        <radialGradient id="nixieGlow" cx="50%" cy="50%" r="50%">
          <stop offset="0%"   stop-color="#ff9500" stop-opacity="0.55"/>
          <stop offset="100%" stop-color="#ff9500" stop-opacity="0"/>
        </radialGradient>
      </defs>
      <!-- Röhre 1 -->
      <rect x="2"   y="6" width="28" height="52" rx="5" fill="#0d0500" stroke="#b8860b" stroke-width="1.3"/>
      <ellipse cx="16"  cy="32" rx="10" ry="14" fill="url(#nixieGlow)"/>
      <text x="16"  y="40" text-anchor="middle" font-size="22" font-family="Georgia,serif" fill="#ff9500">8</text>
      <!-- Röhre 2 -->
      <rect x="34"  y="6" width="28" height="52" rx="5" fill="#0d0500" stroke="#b8860b" stroke-width="1.3"/>
      <ellipse cx="48"  cy="32" rx="10" ry="14" fill="url(#nixieGlow)"/>
      <text x="48"  y="40" text-anchor="middle" font-size="22" font-family="Georgia,serif" fill="#ff9500">8</text>
      <!-- Doppelpunkte -->
      <circle cx="74"  cy="23" r="3.5" fill="#d4af37" opacity="0.85"/>
      <circle cx="74"  cy="41" r="3.5" fill="#d4af37" opacity="0.85"/>
      <!-- Röhre 3 -->
      <rect x="82"  y="6" width="28" height="52" rx="5" fill="#0d0500" stroke="#b8860b" stroke-width="1.3"/>
      <ellipse cx="96"  cy="32" rx="10" ry="14" fill="url(#nixieGlow)"/>
      <text x="96"  y="40" text-anchor="middle" font-size="22" font-family="Georgia,serif" fill="#ff9500">8</text>
      <!-- Röhre 4 -->
      <rect x="114" y="6" width="28" height="52" rx="5" fill="#0d0500" stroke="#b8860b" stroke-width="1.3"/>
      <ellipse cx="128" cy="32" rx="10" ry="14" fill="url(#nixieGlow)"/>
      <text x="128" y="40" text-anchor="middle" font-size="22" font-family="Georgia,serif" fill="#ff9500">8</text>
      <!-- Doppelpunkte -->
      <circle cx="152" cy="23" r="3.5" fill="#d4af37" opacity="0.85"/>
      <circle cx="152" cy="41" r="3.5" fill="#d4af37" opacity="0.85"/>
      <!-- Röhre 5 -->
      <rect x="160" y="6" width="28" height="52" rx="5" fill="#0d0500" stroke="#b8860b" stroke-width="1.3"/>
      <ellipse cx="174" cy="32" rx="10" ry="14" fill="url(#nixieGlow)"/>
      <text x="174" y="40" text-anchor="middle" font-size="22" font-family="Georgia,serif" fill="#ff9500">8</text>
      <!-- Röhre 6 -->
      <rect x="192" y="6" width="28" height="52" rx="5" fill="#0d0500" stroke="#b8860b" stroke-width="1.3"/>
      <ellipse cx="206" cy="32" rx="10" ry="14" fill="url(#nixieGlow)"/>
      <text x="206" y="40" text-anchor="middle" font-size="22" font-family="Georgia,serif" fill="#ff9500">8</text>
    </svg>
  </div>

  <!-- Ornamentlinie unten -->
  <svg class="ornament-line" width="220" height="14" viewBox="0 0 220 14">
    <line x1="0" y1="7" x2="88" y2="7" stroke="#b8860b" stroke-width="1"/>
    <polygon points="100,7 106,3 112,7 106,11" fill="none" stroke="#b8860b" stroke-width="1"/>
    <line x1="122" y1="7" x2="220" y2="7" stroke="#b8860b" stroke-width="1"/>
  </svg>

  <!-- Versionszeile -->
  <div style="text-align:center;margin-top:5mm">
    <div style="font-size:9pt;color:var(--hdr-txt);letter-spacing:2px">Version 2.0 &middot; Juni 2026</div>
  </div>
</div>
```

- [ ] **Schritt 2.2: Im Browser prüfen**

Datei neu laden. Erwartetes Ergebnis: Titelseite mit Eckverzierungen, Zahnrad, Nixie-Röhren-Illustration und Versionzeile sichtbar.

- [ ] **Schritt 2.3: Commit**

```bash
git add docs/manual/nixie-clock-ultra-bedienungsanleitung.html
git commit -m "feat: Titelseite mit Steampunk-SVG-Ornamente und Nixie-Illustration"
```

---

## Task 3: Inhaltsverzeichnis

**Files:**
- Modify: `docs/manual/nixie-clock-ultra-bedienungsanleitung.html` — `<!-- Task 3 -->` ersetzen

- [ ] **Schritt 3.1: Inhaltsverzeichnis einfügen**

Ersetze `<!-- Task 3 -->` durch:

```html
<div class="page">
  <!-- Eckverzierungen -->
  <svg class="corner-tl" width="36" height="36" viewBox="0 0 36 36">
    <path d="M2,2 L2,16 M2,2 L16,2" stroke="#b8860b" stroke-width="1.4" fill="none"/>
    <circle cx="2" cy="2" r="2" fill="#b8860b"/>
  </svg>
  <svg class="corner-tr" width="36" height="36" viewBox="0 0 36 36">
    <path d="M34,2 L34,16 M34,2 L20,2" stroke="#b8860b" stroke-width="1.4" fill="none"/>
    <circle cx="34" cy="2" r="2" fill="#b8860b"/>
  </svg>
  <svg class="corner-bl" width="36" height="36" viewBox="0 0 36 36">
    <path d="M2,34 L2,20 M2,34 L16,34" stroke="#b8860b" stroke-width="1.4" fill="none"/>
    <circle cx="2" cy="34" r="2" fill="#b8860b"/>
  </svg>
  <svg class="corner-br" width="36" height="36" viewBox="0 0 36 36">
    <path d="M34,34 L34,20 M34,34 L20,34" stroke="#b8860b" stroke-width="1.4" fill="none"/>
    <circle cx="34" cy="34" r="2" fill="#b8860b"/>
  </svg>

  <div style="max-width:140mm;margin:0 auto">
    <!-- Überschrift -->
    <div class="toc-heading">Inhalt</div>
    <svg class="ornament-line" width="160" height="12" viewBox="0 0 160 12">
      <line x1="0" y1="6" x2="62" y2="6" stroke="#b8860b" stroke-width="0.9"/>
      <circle cx="80" cy="6" r="4" fill="none" stroke="#b8860b" stroke-width="0.9"/>
      <line x1="98" y1="6" x2="160" y2="6" stroke="#b8860b" stroke-width="0.9"/>
    </svg>

    <div style="margin-top:6mm">
      <div class="toc-entry">
        <span class="toc-num">I.</span>
        <span class="toc-title">Übersicht &amp; Sicherheit</span>
        <span class="toc-page">3</span>
      </div>
      <div class="toc-entry">
        <span class="toc-num">II.</span>
        <span class="toc-title">Inbetriebnahme</span>
        <span class="toc-page">4</span>
      </div>
      <div class="toc-entry">
        <span class="toc-num">III.</span>
        <span class="toc-title">Tasten &amp; Bedienung</span>
        <span class="toc-page">5</span>
      </div>
      <div class="toc-entry">
        <span class="toc-num">IV.</span>
        <span class="toc-title">Zeit einstellen</span>
        <span class="toc-page">6</span>
      </div>
      <div class="toc-entry">
        <span class="toc-num">V.</span>
        <span class="toc-title">Beleuchtung &amp; Animationen</span>
        <span class="toc-page">7</span>
      </div>
      <div class="toc-entry">
        <span class="toc-num">VI.</span>
        <span class="toc-title">IR-Fernbedienung</span>
        <span class="toc-page">9</span>
      </div>
      <div class="toc-entry">
        <span class="toc-num">VII.</span>
        <span class="toc-title">WLAN &amp; Web-Interface</span>
        <span class="toc-page">11</span>
      </div>
      <div class="toc-entry">
        <span class="toc-num">VIII.</span>
        <span class="toc-title">Einstellungen &amp; Persistenz</span>
        <span class="toc-page">13</span>
      </div>
      <div class="toc-entry">
        <span class="toc-num">IX.</span>
        <span class="toc-title">Technische Daten</span>
        <span class="toc-page">14</span>
      </div>
    </div>

    <div style="margin-top:8mm;text-align:center">
      <svg class="ornament-small" width="80" height="10" viewBox="0 0 80 10">
        <line x1="0" y1="5" x2="28" y2="5" stroke="#b8860b" stroke-width="0.8"/>
        <circle cx="40" cy="5" r="3" fill="none" stroke="#b8860b" stroke-width="0.8"/>
        <line x1="52" y1="5" x2="80" y2="5" stroke="#b8860b" stroke-width="0.8"/>
      </svg>
    </div>
  </div>
</div>
```

- [ ] **Schritt 3.2: Im Browser prüfen**

Erwartetes Ergebnis: Zweite Seite mit gepunktetem Inhaltsverzeichnis, Seitenzahlen rechts.

- [ ] **Schritt 3.3: Commit**

```bash
git add docs/manual/nixie-clock-ultra-bedienungsanleitung.html
git commit -m "feat: Inhaltsverzeichnis mit gepunkteten Leitlinien"
```

---

## Task 4: Kapitel I & II

**Files:**
- Modify: `docs/manual/nixie-clock-ultra-bedienungsanleitung.html` — beide `<!-- Task 4 -->` ersetzen

**Hinweis:** Das Kapitel-Header-Muster (running-header + chapter-title + chapter-rule + Fußornament) wiederholt sich in Tasks 4–9 für jedes Kapitel. Vollständiger Code jeweils unten.

- [ ] **Schritt 4.1: Kapitel I einfügen**

Ersetze erstes `<!-- Task 4 -->` durch:

```html
<div class="page">
  <div class="running-header">
    <span>Nixie Clock Ultra &middot; Bedienungsanleitung</span>
    <span>⚙ 3</span>
  </div>

  <div class="chapter-title">
    <svg width="30" height="30" viewBox="0 0 30 30" style="flex-shrink:0">
      <g transform="translate(15,15)">
        <circle r="5.5" fill="var(--pg-light)" stroke="var(--gold)" stroke-width="1.1"/>
        <circle r="2.2" fill="var(--gold)"/>
        <rect x="-1.8" y="-10" width="3.6" height="4.5" rx="0.6" fill="var(--gold)" transform="rotate(0)"/>
        <rect x="-1.8" y="-10" width="3.6" height="4.5" rx="0.6" fill="var(--gold)" transform="rotate(45)"/>
        <rect x="-1.8" y="-10" width="3.6" height="4.5" rx="0.6" fill="var(--gold)" transform="rotate(90)"/>
        <rect x="-1.8" y="-10" width="3.6" height="4.5" rx="0.6" fill="var(--gold)" transform="rotate(135)"/>
        <rect x="-1.8" y="-10" width="3.6" height="4.5" rx="0.6" fill="var(--gold)" transform="rotate(180)"/>
        <rect x="-1.8" y="-10" width="3.6" height="4.5" rx="0.6" fill="var(--gold)" transform="rotate(225)"/>
        <rect x="-1.8" y="-10" width="3.6" height="4.5" rx="0.6" fill="var(--gold)" transform="rotate(270)"/>
        <rect x="-1.8" y="-10" width="3.6" height="4.5" rx="0.6" fill="var(--gold)" transform="rotate(315)"/>
      </g>
    </svg>
    <div>
      <div class="chapter-label">Kapitel I</div>
      <h1>Übersicht &amp; Sicherheit</h1>
    </div>
  </div>

  <p>Die Nixie Clock Ultra ist eine Röhrenuhr auf Basis des ESP32-S3 mit 6 Nixie-Röhren, 10 NeoPixel-LEDs, einem Web-Interface sowie einem IR-Empfänger. Die Röhren zeigen die aktuelle Uhrzeit in direkter Ansteuerung ohne Multiplexing — für maximale Helligkeit und ghostingfreie Darstellung.</p>

  <div class="warning-box no-break">
    <svg width="20" height="20" viewBox="0 0 20 20" style="flex-shrink:0;margin-top:2px">
      <polygon points="10,2 18,17 2,17" fill="none" stroke="#8b0000" stroke-width="1.3" stroke-linejoin="round"/>
      <line x1="10" y1="8" x2="10" y2="13" stroke="#8b0000" stroke-width="1.3"/>
      <circle cx="10" cy="15" r="0.9" fill="#8b0000"/>
    </svg>
    <div>
      <div class="warn-title">Sicherheitshinweis – Hochspannung</div>
      <p>Die Nixie-Röhren werden mit <strong>170–180 V DC</strong> betrieben. Diese Spannung kann bei Berührung lebensgefährlich sein. Vor jeglichen Arbeiten an der Schaltung die Versorgungsspannung trennen und die Kondensatoren vollständig entladen. Nie unter Spannung an der Schaltung arbeiten.</p>
    </div>
  </div>

  <h2>Lieferumfang</h2>
  <p>Die Uhr wird betriebsbereit geliefert. Eine Infrarot-Fernbedienung ist nicht im Lieferumfang enthalten — jede handelsübliche IR-Fernbedienung (NEC, Samsung, Sony, RC5 u.v.m.) kann angelernt werden.</p>

  <div style="margin-top:auto;padding-top:6mm;text-align:center">
    <svg class="ornament-small" width="80" height="10" viewBox="0 0 80 10">
      <line x1="0" y1="5" x2="28" y2="5" stroke="#b8860b" stroke-width="0.8"/>
      <circle cx="40" cy="5" r="3" fill="none" stroke="#b8860b" stroke-width="0.8"/>
      <line x1="52" y1="5" x2="80" y2="5" stroke="#b8860b" stroke-width="0.8"/>
    </svg>
  </div>
</div>
```

- [ ] **Schritt 4.2: Kapitel II einfügen**

Ersetze zweites `<!-- Task 4 -->` durch:

```html
<div class="page">
  <div class="running-header">
    <span>Nixie Clock Ultra &middot; Bedienungsanleitung</span>
    <span>⚙ 4</span>
  </div>

  <div class="chapter-title">
    <svg width="30" height="30" viewBox="0 0 30 30" style="flex-shrink:0">
      <g transform="translate(15,15)">
        <circle r="5.5" fill="var(--pg-light)" stroke="var(--gold)" stroke-width="1.1"/>
        <circle r="2.2" fill="var(--gold)"/>
        <rect x="-1.8" y="-10" width="3.6" height="4.5" rx="0.6" fill="var(--gold)" transform="rotate(0)"/>
        <rect x="-1.8" y="-10" width="3.6" height="4.5" rx="0.6" fill="var(--gold)" transform="rotate(45)"/>
        <rect x="-1.8" y="-10" width="3.6" height="4.5" rx="0.6" fill="var(--gold)" transform="rotate(90)"/>
        <rect x="-1.8" y="-10" width="3.6" height="4.5" rx="0.6" fill="var(--gold)" transform="rotate(135)"/>
        <rect x="-1.8" y="-10" width="3.6" height="4.5" rx="0.6" fill="var(--gold)" transform="rotate(180)"/>
        <rect x="-1.8" y="-10" width="3.6" height="4.5" rx="0.6" fill="var(--gold)" transform="rotate(225)"/>
        <rect x="-1.8" y="-10" width="3.6" height="4.5" rx="0.6" fill="var(--gold)" transform="rotate(270)"/>
        <rect x="-1.8" y="-10" width="3.6" height="4.5" rx="0.6" fill="var(--gold)" transform="rotate(315)"/>
      </g>
    </svg>
    <div>
      <div class="chapter-label">Kapitel II</div>
      <h1>Inbetriebnahme</h1>
    </div>
  </div>

  <p>Die Uhr ist nach dem Anschließen an die Spannungsversorgung (5 V, Logik + Hochspannungsversorgung für die Nixie-Röhren) sofort betriebsbereit.</p>

  <div class="steps">
    <div class="step">
      <div class="step-num">1</div>
      <p>Spannungsversorgung anschließen. Die Nixie-Röhren starten mit einem sanften <strong>Fade-In</strong> der NeoPixel-Beleuchtung.</p>
    </div>
    <div class="step">
      <div class="step-num">2</div>
      <p>Die Uhr zeigt sofort die in der RTC (DS1302) gespeicherte Uhrzeit an — auch ohne WLAN-Verbindung.</p>
    </div>
    <div class="step">
      <div class="step-num">3</div>
      <p>Alle gespeicherten Einstellungen (Helligkeit, Animation, IR-Codes, WLAN-Zugangsdaten) werden automatisch aus dem Flash-Speicher geladen.</p>
    </div>
    <div class="step">
      <div class="step-num">4</div>
      <p>Das WLAN-Hotspot <strong>NixieClock</strong> (Passwort: <code>nixie1234</code>) ist sofort aktiv und unter <strong>192.168.4.1</strong> erreichbar.</p>
    </div>
  </div>

  <div class="info-box no-break">
    Ist die Uhrzeit nach dem ersten Start falsch, wurde die RTC noch nicht eingestellt. Die Zeit lässt sich per Tastendruck (Kapitel IV) oder bequem über das Web-Interface (Kapitel VII) korrigieren. Sobald die Uhr mit einem Heimnetz verbunden ist, synchronisiert sie die Uhrzeit automatisch per NTP.
  </div>

  <div style="margin-top:auto;padding-top:6mm;text-align:center">
    <svg class="ornament-small" width="80" height="10" viewBox="0 0 80 10">
      <line x1="0" y1="5" x2="28" y2="5" stroke="#b8860b" stroke-width="0.8"/>
      <circle cx="40" cy="5" r="3" fill="none" stroke="#b8860b" stroke-width="0.8"/>
      <line x1="52" y1="5" x2="80" y2="5" stroke="#b8860b" stroke-width="0.8"/>
    </svg>
  </div>
</div>
```

- [ ] **Schritt 4.3: Im Browser prüfen**

Erwartetes Ergebnis: Seiten 3 und 4 mit Kapitelheader, Warnbox (Kap. I) und nummerierten Schritten (Kap. II).

- [ ] **Schritt 4.4: Commit**

```bash
git add docs/manual/nixie-clock-ultra-bedienungsanleitung.html
git commit -m "feat: Kapitel I Übersicht & Sicherheit, Kapitel II Inbetriebnahme"
```

---

## Task 5: Kapitel III & IV

**Files:**
- Modify: `docs/manual/nixie-clock-ultra-bedienungsanleitung.html` — beide `<!-- Task 5 -->` ersetzen

- [ ] **Schritt 5.1: Kapitel III einfügen**

Ersetze erstes `<!-- Task 5 -->` durch:

```html
<div class="page">
  <div class="running-header">
    <span>Nixie Clock Ultra &middot; Bedienungsanleitung</span>
    <span>⚙ 5</span>
  </div>
  <div class="chapter-title">
    <svg width="30" height="30" viewBox="0 0 30 30" style="flex-shrink:0"><g transform="translate(15,15)"><circle r="5.5" fill="var(--pg-light)" stroke="var(--gold)" stroke-width="1.1"/><circle r="2.2" fill="var(--gold)"/><rect x="-1.8" y="-10" width="3.6" height="4.5" rx="0.6" fill="var(--gold)" transform="rotate(0)"/><rect x="-1.8" y="-10" width="3.6" height="4.5" rx="0.6" fill="var(--gold)" transform="rotate(45)"/><rect x="-1.8" y="-10" width="3.6" height="4.5" rx="0.6" fill="var(--gold)" transform="rotate(90)"/><rect x="-1.8" y="-10" width="3.6" height="4.5" rx="0.6" fill="var(--gold)" transform="rotate(135)"/><rect x="-1.8" y="-10" width="3.6" height="4.5" rx="0.6" fill="var(--gold)" transform="rotate(180)"/><rect x="-1.8" y="-10" width="3.6" height="4.5" rx="0.6" fill="var(--gold)" transform="rotate(225)"/><rect x="-1.8" y="-10" width="3.6" height="4.5" rx="0.6" fill="var(--gold)" transform="rotate(270)"/><rect x="-1.8" y="-10" width="3.6" height="4.5" rx="0.6" fill="var(--gold)" transform="rotate(315)"/></g></svg>
    <div>
      <div class="chapter-label">Kapitel III</div>
      <h1>Tasten &amp; Bedienung</h1>
    </div>
  </div>

  <p>Das Gehäuse beherbergt vier Drucktaster, die alle wesentlichen Einstellungen direkt am Gerät ermöglichen. Jede Taste reagiert auf <strong>kurzen</strong> und — wo angegeben — auf <strong>langen Druck</strong> (≥ 600 ms gehalten).</p>

  <table class="data-table no-break">
    <thead>
      <tr>
        <th>Taste</th>
        <th>Kurzer Druck</th>
        <th>Langer Druck</th>
      </tr>
    </thead>
    <tbody>
      <tr>
        <td><strong>SET</strong></td>
        <td>Einstellmodus starten · nächste Stelle · Zeit speichern</td>
        <td><em>—</em></td>
      </tr>
      <tr>
        <td><strong>UP</strong></td>
        <td>Wert erhöhen</td>
        <td>Wert erhöhen (Auto-Repeat)</td>
      </tr>
      <tr>
        <td><strong>DOWN</strong></td>
        <td>Wert verringern</td>
        <td>Wert verringern (Auto-Repeat)</td>
      </tr>
      <tr>
        <td><strong>LIGHT</strong></td>
        <td>Helligkeit weiterschalten (4 Stufen)</td>
        <td>Trennpunkt-LEDs dauerhaft an/aus</td>
      </tr>
    </tbody>
  </table>

  <p>Alle Tasteneinstellungen wirken sofort und werden dauerhaft gespeichert. Dieselben Funktionen stehen alternativ über die IR-Fernbedienung (Kapitel VI) und das Web-Interface (Kapitel VII) zur Verfügung.</p>

  <div style="margin-top:auto;padding-top:6mm;text-align:center">
    <svg class="ornament-small" width="80" height="10" viewBox="0 0 80 10"><line x1="0" y1="5" x2="28" y2="5" stroke="#b8860b" stroke-width="0.8"/><circle cx="40" cy="5" r="3" fill="none" stroke="#b8860b" stroke-width="0.8"/><line x1="52" y1="5" x2="80" y2="5" stroke="#b8860b" stroke-width="0.8"/></svg>
  </div>
</div>
```

- [ ] **Schritt 5.2: Kapitel IV einfügen**

Ersetze zweites `<!-- Task 5 -->` durch:

```html
<div class="page">
  <div class="running-header">
    <span>Nixie Clock Ultra &middot; Bedienungsanleitung</span>
    <span>⚙ 6</span>
  </div>
  <div class="chapter-title">
    <svg width="30" height="30" viewBox="0 0 30 30" style="flex-shrink:0"><g transform="translate(15,15)"><circle r="5.5" fill="var(--pg-light)" stroke="var(--gold)" stroke-width="1.1"/><circle r="2.2" fill="var(--gold)"/><rect x="-1.8" y="-10" width="3.6" height="4.5" rx="0.6" fill="var(--gold)" transform="rotate(0)"/><rect x="-1.8" y="-10" width="3.6" height="4.5" rx="0.6" fill="var(--gold)" transform="rotate(45)"/><rect x="-1.8" y="-10" width="3.6" height="4.5" rx="0.6" fill="var(--gold)" transform="rotate(90)"/><rect x="-1.8" y="-10" width="3.6" height="4.5" rx="0.6" fill="var(--gold)" transform="rotate(135)"/><rect x="-1.8" y="-10" width="3.6" height="4.5" rx="0.6" fill="var(--gold)" transform="rotate(180)"/><rect x="-1.8" y="-10" width="3.6" height="4.5" rx="0.6" fill="var(--gold)" transform="rotate(225)"/><rect x="-1.8" y="-10" width="3.6" height="4.5" rx="0.6" fill="var(--gold)" transform="rotate(270)"/><rect x="-1.8" y="-10" width="3.6" height="4.5" rx="0.6" fill="var(--gold)" transform="rotate(315)"/></g></svg>
    <div>
      <div class="chapter-label">Kapitel IV</div>
      <h1>Zeit einstellen</h1>
    </div>
  </div>

  <p>Die Uhrzeit lässt sich direkt am Gerät per Tastendruck einstellen. Die blinkende Stelle zeigt an, welcher Wert gerade bearbeitet wird.</p>

  <div class="steps">
    <div class="step"><div class="step-num">1</div><p><strong>SET</strong> drücken → Stunden blinken auf.</p></div>
    <div class="step"><div class="step-num">2</div><p>Mit <strong>UP</strong> / <strong>DOWN</strong> die Stunden einstellen (0–23). Langer Druck aktiviert Auto-Repeat.</p></div>
    <div class="step"><div class="step-num">3</div><p><strong>SET</strong> drücken → Minuten blinken auf.</p></div>
    <div class="step"><div class="step-num">4</div><p>Mit <strong>UP</strong> / <strong>DOWN</strong> die Minuten einstellen (0–59).</p></div>
    <div class="step"><div class="step-num">5</div><p><strong>SET</strong> drücken → Sekunden blinken auf.</p></div>
    <div class="step"><div class="step-num">6</div><p>Mit <strong>UP</strong> / <strong>DOWN</strong> die Sekunden einstellen (0–59).</p></div>
    <div class="step"><div class="step-num">7</div><p><strong>SET</strong> drücken → Zeit wird in der RTC gespeichert, Normalanzeige kehrt zurück.</p></div>
  </div>

  <div class="info-box no-break">
    <strong>Timeout:</strong> Erfolgt <strong>15 Sekunden</strong> lang keine Eingabe, wird der Einstellmodus automatisch beendet und die bis dahin eingestellten Werte werden gespeichert.
  </div>

  <div style="margin-top:auto;padding-top:6mm;text-align:center">
    <svg class="ornament-small" width="80" height="10" viewBox="0 0 80 10"><line x1="0" y1="5" x2="28" y2="5" stroke="#b8860b" stroke-width="0.8"/><circle cx="40" cy="5" r="3" fill="none" stroke="#b8860b" stroke-width="0.8"/><line x1="52" y1="5" x2="80" y2="5" stroke="#b8860b" stroke-width="0.8"/></svg>
  </div>
</div>
```

- [ ] **Schritt 5.3: Im Browser prüfen**

Erwartetes Ergebnis: Seiten 5–6. Kap. III zeigt goldene Tabelle mit 4 Zeilen, Kap. IV zeigt nummerierte Schritte 1–7 und Info-Box.

- [ ] **Schritt 5.4: Commit**

```bash
git add docs/manual/nixie-clock-ultra-bedienungsanleitung.html
git commit -m "feat: Kapitel III Tasten & Bedienung, Kapitel IV Zeit einstellen"
```

---

## Task 6: Kapitel V – Beleuchtung & Animationen

**Files:**
- Modify: `docs/manual/nixie-clock-ultra-bedienungsanleitung.html` — `<!-- Task 6 -->` ersetzen

- [ ] **Schritt 6.1: Kapitel V einfügen**

Ersetze `<!-- Task 6 -->` durch:

```html
<div class="page">
  <div class="running-header">
    <span>Nixie Clock Ultra &middot; Bedienungsanleitung</span>
    <span>⚙ 7</span>
  </div>
  <div class="chapter-title">
    <svg width="30" height="30" viewBox="0 0 30 30" style="flex-shrink:0"><g transform="translate(15,15)"><circle r="5.5" fill="var(--pg-light)" stroke="var(--gold)" stroke-width="1.1"/><circle r="2.2" fill="var(--gold)"/><rect x="-1.8" y="-10" width="3.6" height="4.5" rx="0.6" fill="var(--gold)" transform="rotate(0)"/><rect x="-1.8" y="-10" width="3.6" height="4.5" rx="0.6" fill="var(--gold)" transform="rotate(45)"/><rect x="-1.8" y="-10" width="3.6" height="4.5" rx="0.6" fill="var(--gold)" transform="rotate(90)"/><rect x="-1.8" y="-10" width="3.6" height="4.5" rx="0.6" fill="var(--gold)" transform="rotate(135)"/><rect x="-1.8" y="-10" width="3.6" height="4.5" rx="0.6" fill="var(--gold)" transform="rotate(180)"/><rect x="-1.8" y="-10" width="3.6" height="4.5" rx="0.6" fill="var(--gold)" transform="rotate(225)"/><rect x="-1.8" y="-10" width="3.6" height="4.5" rx="0.6" fill="var(--gold)" transform="rotate(270)"/><rect x="-1.8" y="-10" width="3.6" height="4.5" rx="0.6" fill="var(--gold)" transform="rotate(315)"/></g></svg>
    <div>
      <div class="chapter-label">Kapitel V</div>
      <h1>Beleuchtung &amp; Animationen</h1>
    </div>
  </div>

  <h2>NeoPixel-Helligkeit</h2>
  <p>Ein kurzer Druck auf <strong>LIGHT</strong> schaltet die Hintergrundbeleuchtung durch vier Helligkeitsstufen. Die Einstellung wird dauerhaft gespeichert.</p>

  <table class="data-table no-break">
    <thead><tr><th>Stufe</th><th>Beschreibung</th></tr></thead>
    <tbody>
      <tr><td><strong>1</strong></td><td>Sehr dim – minimale Hintergrundbeleuchtung</td></tr>
      <tr><td><strong>2</strong></td><td>Dim – dezente Beleuchtung</td></tr>
      <tr><td><strong>3</strong></td><td>Hell – angenehme Raumbeleuchtung</td></tr>
      <tr><td><strong>4</strong></td><td>Voll (Standard) – maximale Helligkeit</td></tr>
    </tbody>
  </table>

  <p>Über das Web-Interface ist zusätzlich ein Feinstufenregler (Wert 10–255) verfügbar.</p>

  <h2>Animationsmodi</h2>
  <table class="data-table no-break">
    <thead><tr><th>Modus</th><th>Beschreibung</th></tr></thead>
    <tbody>
      <tr><td><strong>Rainbow</strong></td><td>Farbverlauf wandert kontinuierlich über die 6 Hintergrund-LEDs</td></tr>
      <tr><td><strong>Statisch Warmweiß</strong></td><td>Alle Hintergrund-LEDs leuchten in warmweißem Orange</td></tr>
      <tr><td><strong>Puls</strong></td><td>Sinusförmiges Auf- und Abdimmen der gesamten Beleuchtung</td></tr>
      <tr><td><strong>Slot-Machine</strong></td><td>Schneller Farbwechsel während der Slot-Animation; sonst Rainbow. Alle 10 Sekunden automatische Slot-Animation.</td></tr>
    </tbody>
  </table>

  <h2>Trennpunkt-LEDs</h2>
  <p>Die vier LEDs zwischen den Zifferngruppen blinken standardmäßig sekundengenau. Ein <strong>langer Druck auf LIGHT</strong> schaltet sie in den Dauerleucht-Modus:</p>

  <table class="data-table no-break">
    <thead><tr><th>Modus</th><th>Beschreibung</th></tr></thead>
    <tbody>
      <tr><td><strong>Blinken</strong> (Standard)</td><td>LEDs blinken sekundengenau im Takt der Uhr</td></tr>
      <tr><td><strong>Dauerhaft an</strong></td><td>LEDs leuchten durchgehend ohne zu blinken</td></tr>
    </tbody>
  </table>

  <div style="margin-top:auto;padding-top:6mm;text-align:center">
    <svg class="ornament-small" width="80" height="10" viewBox="0 0 80 10"><line x1="0" y1="5" x2="28" y2="5" stroke="#b8860b" stroke-width="0.8"/><circle cx="40" cy="5" r="3" fill="none" stroke="#b8860b" stroke-width="0.8"/><line x1="52" y1="5" x2="80" y2="5" stroke="#b8860b" stroke-width="0.8"/></svg>
  </div>
</div>
```

- [ ] **Schritt 6.2: Im Browser prüfen**

Erwartetes Ergebnis: Seite 7 mit drei Tabellen (Helligkeit, Animationen, Trennpunkte).

- [ ] **Schritt 6.3: Commit**

```bash
git add docs/manual/nixie-clock-ultra-bedienungsanleitung.html
git commit -m "feat: Kapitel V Beleuchtung und Animationen"
```

---

## Task 7: Kapitel VI – IR-Fernbedienung

**Files:**
- Modify: `docs/manual/nixie-clock-ultra-bedienungsanleitung.html` — `<!-- Task 7 -->` ersetzen

- [ ] **Schritt 7.1: Kapitel VI einfügen**

Ersetze `<!-- Task 7 -->` durch:

```html
<div class="page">
  <div class="running-header">
    <span>Nixie Clock Ultra &middot; Bedienungsanleitung</span>
    <span>⚙ 9</span>
  </div>
  <div class="chapter-title">
    <svg width="30" height="30" viewBox="0 0 30 30" style="flex-shrink:0"><g transform="translate(15,15)"><circle r="5.5" fill="var(--pg-light)" stroke="var(--gold)" stroke-width="1.1"/><circle r="2.2" fill="var(--gold)"/><rect x="-1.8" y="-10" width="3.6" height="4.5" rx="0.6" fill="var(--gold)" transform="rotate(0)"/><rect x="-1.8" y="-10" width="3.6" height="4.5" rx="0.6" fill="var(--gold)" transform="rotate(45)"/><rect x="-1.8" y="-10" width="3.6" height="4.5" rx="0.6" fill="var(--gold)" transform="rotate(90)"/><rect x="-1.8" y="-10" width="3.6" height="4.5" rx="0.6" fill="var(--gold)" transform="rotate(135)"/><rect x="-1.8" y="-10" width="3.6" height="4.5" rx="0.6" fill="var(--gold)" transform="rotate(180)"/><rect x="-1.8" y="-10" width="3.6" height="4.5" rx="0.6" fill="var(--gold)" transform="rotate(225)"/><rect x="-1.8" y="-10" width="3.6" height="4.5" rx="0.6" fill="var(--gold)" transform="rotate(270)"/><rect x="-1.8" y="-10" width="3.6" height="4.5" rx="0.6" fill="var(--gold)" transform="rotate(315)"/></g></svg>
    <div>
      <div class="chapter-label">Kapitel VI</div>
      <h1>IR-Fernbedienung</h1>
    </div>
  </div>

  <p>Die Uhr lässt sich mit jeder handelsüblichen Infrarot-Fernbedienung steuern (NEC, Samsung, Sony, RC5 u.v.m.). Jede Taste kann frei einer der sieben Funktionen zugewiesen werden.</p>

  <h2>Verfügbare Funktionen</h2>
  <table class="data-table no-break">
    <thead><tr><th>Funktion</th><th>Beschreibung</th></tr></thead>
    <tbody>
      <tr><td><strong>SET</strong></td><td>Einstellmodus starten / nächste Stelle / Zeit speichern</td></tr>
      <tr><td><strong>UP</strong></td><td>Wert erhöhen im Einstellmodus</td></tr>
      <tr><td><strong>DOWN</strong></td><td>Wert verringern im Einstellmodus</td></tr>
      <tr><td><strong>BRIGHTNESS</strong></td><td>Helligkeit weiterschalten (4 Stufen)</td></tr>
      <tr><td><strong>ANIM_NEXT</strong></td><td>Nächsten Animationsmodus aktivieren</td></tr>
      <tr><td><strong>SLOT</strong></td><td>Slot-Machine-Animation auslösen</td></tr>
      <tr><td><strong>COLON_TOGGLE</strong></td><td>Trennpunkt-LEDs dauerhaft an/aus</td></tr>
    </tbody>
  </table>

  <h2>Fernbedienung anlernen</h2>
  <p>Das Anlernen erfolgt über das Web-Interface unter <strong>IR-Fernbedienung</strong>:</p>

  <div class="steps">
    <div class="step"><div class="step-num">1</div><p>Auf <strong>Anlernen</strong> neben der gewünschten Funktion klicken.</p></div>
    <div class="step"><div class="step-num">2</div><p>Die Zeile blinkt orange und zeigt <em>»Taste auf Fernbedienung drücken…«</em></p></div>
    <div class="step"><div class="step-num">3</div><p>Beliebige Taste auf der Fernbedienung drücken → Code wird sofort gespeichert.</p></div>
  </div>

  <div class="info-box no-break">
    Nach <strong>10 Sekunden</strong> ohne Eingabe bricht der Anlernmodus automatisch ab. Ein bestehender Code kann durch Klick auf <strong>✕</strong> gelöscht werden. Repeat-Codes (automatische Wiederholung der Fernbedienung) werden herausgefiltert.
  </div>

  <div style="margin-top:auto;padding-top:6mm;text-align:center">
    <svg class="ornament-small" width="80" height="10" viewBox="0 0 80 10"><line x1="0" y1="5" x2="28" y2="5" stroke="#b8860b" stroke-width="0.8"/><circle cx="40" cy="5" r="3" fill="none" stroke="#b8860b" stroke-width="0.8"/><line x1="52" y1="5" x2="80" y2="5" stroke="#b8860b" stroke-width="0.8"/></svg>
  </div>
</div>
```

- [ ] **Schritt 7.2: Im Browser prüfen**

Erwartetes Ergebnis: Seite 9 mit Funktionstabelle (7 Zeilen), Anlernschritte und Info-Box.

- [ ] **Schritt 7.3: Commit**

```bash
git add docs/manual/nixie-clock-ultra-bedienungsanleitung.html
git commit -m "feat: Kapitel VI IR-Fernbedienung"
```

---

## Task 8: Kapitel VII – WLAN & Web-Interface

**Files:**
- Modify: `docs/manual/nixie-clock-ultra-bedienungsanleitung.html` — `<!-- Task 8 -->` ersetzen

- [ ] **Schritt 8.1: Kapitel VII einfügen**

Ersetze `<!-- Task 8 -->` durch:

```html
<div class="page">
  <div class="running-header">
    <span>Nixie Clock Ultra &middot; Bedienungsanleitung</span>
    <span>⚙ 11</span>
  </div>
  <div class="chapter-title">
    <svg width="30" height="30" viewBox="0 0 30 30" style="flex-shrink:0"><g transform="translate(15,15)"><circle r="5.5" fill="var(--pg-light)" stroke="var(--gold)" stroke-width="1.1"/><circle r="2.2" fill="var(--gold)"/><rect x="-1.8" y="-10" width="3.6" height="4.5" rx="0.6" fill="var(--gold)" transform="rotate(0)"/><rect x="-1.8" y="-10" width="3.6" height="4.5" rx="0.6" fill="var(--gold)" transform="rotate(45)"/><rect x="-1.8" y="-10" width="3.6" height="4.5" rx="0.6" fill="var(--gold)" transform="rotate(90)"/><rect x="-1.8" y="-10" width="3.6" height="4.5" rx="0.6" fill="var(--gold)" transform="rotate(135)"/><rect x="-1.8" y="-10" width="3.6" height="4.5" rx="0.6" fill="var(--gold)" transform="rotate(180)"/><rect x="-1.8" y="-10" width="3.6" height="4.5" rx="0.6" fill="var(--gold)" transform="rotate(225)"/><rect x="-1.8" y="-10" width="3.6" height="4.5" rx="0.6" fill="var(--gold)" transform="rotate(270)"/><rect x="-1.8" y="-10" width="3.6" height="4.5" rx="0.6" fill="var(--gold)" transform="rotate(315)"/></g></svg>
    <div>
      <div class="chapter-label">Kapitel VII</div>
      <h1>WLAN &amp; Web-Interface</h1>
    </div>
  </div>

  <h2>Verbindung herstellen</h2>
  <p>Die Uhr startet immer als WLAN-Access-Point. Das Web-Interface ist ohne weitere Konfiguration sofort erreichbar:</p>

  <table class="conn-table no-break">
    <tbody>
      <tr><td>SSID</td><td>NixieClock</td></tr>
      <tr><td>Passwort</td><td>nixie1234</td></tr>
      <tr><td>IP-Adresse</td><td>192.168.4.1</td></tr>
    </tbody>
  </table>

  <div class="steps">
    <div class="step"><div class="step-num">1</div><p>Mit dem WLAN <strong>NixieClock</strong> verbinden.</p></div>
    <div class="step"><div class="step-num">2</div><p>Browser öffnen und <strong>http://192.168.4.1</strong> aufrufen.</p></div>
  </div>

  <h2>Heimnetz einrichten</h2>
  <p>Im Web-Interface unter <strong>WLAN-Einrichtung</strong>:</p>

  <div class="steps">
    <div class="step"><div class="step-num">1</div><p>Auf <strong>Scannen</strong> klicken → verfügbare Netzwerke erscheinen.</p></div>
    <div class="step"><div class="step-num">2</div><p>Gewünschtes Netzwerk auswählen und Passwort eingeben.</p></div>
    <div class="step"><div class="step-num">3</div><p><strong>Verbinden</strong> klicken → Uhr startet automatisch neu.</p></div>
  </div>

  <p>Nach dem Neustart ist die Uhr über den Hotspot (<code>192.168.4.1</code>) <em>und</em> über das Heimnetz erreichbar. Die Heimnetz-IP wird im Web-Interface angezeigt. Heimnetz entfernen: SSID-Feld leer lassen und <strong>Verbinden</strong> klicken.</p>

  <h2>NTP-Zeitsynchronisierung</h2>
  <p>Sobald die Uhr mit einem Heimnetz verbunden ist, synchronisiert sie die Uhrzeit <strong>einmalig</strong> automatisch über NTP (<code>pool.ntp.org</code>). Die Zeitzone ist auf <strong>Mitteleuropa (CET/CEST)</strong> voreingestellt. Der NTP-Status wird im Web-Interface angezeigt.</p>

  <h2>Web-Interface Funktionen</h2>
  <table class="data-table no-break">
    <thead><tr><th>Funktion</th><th>Beschreibung</th></tr></thead>
    <tbody>
      <tr><td><strong>Zeit stellen</strong></td><td>Stunden, Minuten, Sekunden manuell eingeben oder Browser-Zeit übernehmen</td></tr>
      <tr><td><strong>Helligkeit (Stufen)</strong></td><td>4 Stufen — entspricht kurzem Druck auf LIGHT</td></tr>
      <tr><td><strong>Helligkeit (Fein)</strong></td><td>Schieberegler 10–255 für stufenlose Einstellung</td></tr>
      <tr><td><strong>Animation</strong></td><td>Animationsmodus aus Dropdown wählen</td></tr>
      <tr><td><strong>Farbe (Hue)</strong></td><td>Grundfarbe für statische Modi und Puls-Animation</td></tr>
      <tr><td><strong>Trennpunkte</strong></td><td>Blinken oder dauerhaft an</td></tr>
      <tr><td><strong>Slot-Machine</strong></td><td>Animation manuell auslösen</td></tr>
      <tr><td><strong>IR-Fernbedienung</strong></td><td>Codes anlernen und löschen (siehe Kapitel VI)</td></tr>
      <tr><td><strong>WLAN-Einrichtung</strong></td><td>Heimnetz verbinden oder trennen</td></tr>
    </tbody>
  </table>

  <div style="margin-top:auto;padding-top:6mm;text-align:center">
    <svg class="ornament-small" width="80" height="10" viewBox="0 0 80 10"><line x1="0" y1="5" x2="28" y2="5" stroke="#b8860b" stroke-width="0.8"/><circle cx="40" cy="5" r="3" fill="none" stroke="#b8860b" stroke-width="0.8"/><line x1="52" y1="5" x2="80" y2="5" stroke="#b8860b" stroke-width="0.8"/></svg>
  </div>
</div>
```

- [ ] **Schritt 8.2: Im Browser prüfen**

Erwartetes Ergebnis: Seite 11 mit Verbindungstabelle, Heimnetz-Schritte, NTP-Info und Web-UI-Funktionstabelle (9 Zeilen).

- [ ] **Schritt 8.3: Commit**

```bash
git add docs/manual/nixie-clock-ultra-bedienungsanleitung.html
git commit -m "feat: Kapitel VII WLAN und Web-Interface"
```

---

## Task 9: Kapitel VIII & IX

**Files:**
- Modify: `docs/manual/nixie-clock-ultra-bedienungsanleitung.html` — beide `<!-- Task 9 -->` ersetzen

- [ ] **Schritt 9.1: Kapitel VIII einfügen**

Ersetze erstes `<!-- Task 9 -->` durch:

```html
<div class="page">
  <div class="running-header">
    <span>Nixie Clock Ultra &middot; Bedienungsanleitung</span>
    <span>⚙ 13</span>
  </div>
  <div class="chapter-title">
    <svg width="30" height="30" viewBox="0 0 30 30" style="flex-shrink:0"><g transform="translate(15,15)"><circle r="5.5" fill="var(--pg-light)" stroke="var(--gold)" stroke-width="1.1"/><circle r="2.2" fill="var(--gold)"/><rect x="-1.8" y="-10" width="3.6" height="4.5" rx="0.6" fill="var(--gold)" transform="rotate(0)"/><rect x="-1.8" y="-10" width="3.6" height="4.5" rx="0.6" fill="var(--gold)" transform="rotate(45)"/><rect x="-1.8" y="-10" width="3.6" height="4.5" rx="0.6" fill="var(--gold)" transform="rotate(90)"/><rect x="-1.8" y="-10" width="3.6" height="4.5" rx="0.6" fill="var(--gold)" transform="rotate(135)"/><rect x="-1.8" y="-10" width="3.6" height="4.5" rx="0.6" fill="var(--gold)" transform="rotate(180)"/><rect x="-1.8" y="-10" width="3.6" height="4.5" rx="0.6" fill="var(--gold)" transform="rotate(225)"/><rect x="-1.8" y="-10" width="3.6" height="4.5" rx="0.6" fill="var(--gold)" transform="rotate(270)"/><rect x="-1.8" y="-10" width="3.6" height="4.5" rx="0.6" fill="var(--gold)" transform="rotate(315)"/></g></svg>
    <div>
      <div class="chapter-label">Kapitel VIII</div>
      <h1>Einstellungen &amp; Persistenz</h1>
    </div>
  </div>

  <p>Folgende Einstellungen werden dauerhaft im Flash-Speicher des ESP32-S3 gespeichert und nach jedem Neustart automatisch wiederhergestellt:</p>

  <table class="data-table no-break">
    <thead><tr><th>Einstellung</th><th>Gespeicherter Wert</th></tr></thead>
    <tbody>
      <tr><td><strong>NeoPixel-Helligkeit</strong></td><td>Stufe (1–4) und Feinwert (10–255)</td></tr>
      <tr><td><strong>Animationsmodus</strong></td><td>Rainbow / Statisch / Puls / Slot-Machine</td></tr>
      <tr><td><strong>Trennpunkt-LEDs</strong></td><td>Blinken oder dauerhaft an</td></tr>
      <tr><td><strong>WLAN-Zugangsdaten</strong></td><td>SSID und Passwort des Heimnetzes</td></tr>
      <tr><td><strong>IR-Codes</strong></td><td>Alle 7 angelernten Funktionen</td></tr>
    </tbody>
  </table>

  <div class="info-box no-break">
    Die Uhrzeit wird in der batteriegepufferten RTC (DS1302) gespeichert und bleibt auch bei Stromausfall erhalten — vorausgesetzt, die RTC-Batterie ist geladen.
  </div>

  <div style="margin-top:auto;padding-top:6mm;text-align:center">
    <svg class="ornament-small" width="80" height="10" viewBox="0 0 80 10"><line x1="0" y1="5" x2="28" y2="5" stroke="#b8860b" stroke-width="0.8"/><circle cx="40" cy="5" r="3" fill="none" stroke="#b8860b" stroke-width="0.8"/><line x1="52" y1="5" x2="80" y2="5" stroke="#b8860b" stroke-width="0.8"/></svg>
  </div>
</div>
```

- [ ] **Schritt 9.2: Kapitel IX einfügen**

Ersetze zweites `<!-- Task 9 -->` durch:

```html
<div class="page">
  <div class="running-header">
    <span>Nixie Clock Ultra &middot; Bedienungsanleitung</span>
    <span>⚙ 14</span>
  </div>
  <div class="chapter-title">
    <svg width="30" height="30" viewBox="0 0 30 30" style="flex-shrink:0"><g transform="translate(15,15)"><circle r="5.5" fill="var(--pg-light)" stroke="var(--gold)" stroke-width="1.1"/><circle r="2.2" fill="var(--gold)"/><rect x="-1.8" y="-10" width="3.6" height="4.5" rx="0.6" fill="var(--gold)" transform="rotate(0)"/><rect x="-1.8" y="-10" width="3.6" height="4.5" rx="0.6" fill="var(--gold)" transform="rotate(45)"/><rect x="-1.8" y="-10" width="3.6" height="4.5" rx="0.6" fill="var(--gold)" transform="rotate(90)"/><rect x="-1.8" y="-10" width="3.6" height="4.5" rx="0.6" fill="var(--gold)" transform="rotate(135)"/><rect x="-1.8" y="-10" width="3.6" height="4.5" rx="0.6" fill="var(--gold)" transform="rotate(180)"/><rect x="-1.8" y="-10" width="3.6" height="4.5" rx="0.6" fill="var(--gold)" transform="rotate(225)"/><rect x="-1.8" y="-10" width="3.6" height="4.5" rx="0.6" fill="var(--gold)" transform="rotate(270)"/><rect x="-1.8" y="-10" width="3.6" height="4.5" rx="0.6" fill="var(--gold)" transform="rotate(315)"/></g></svg>
    <div>
      <div class="chapter-label">Kapitel IX</div>
      <h1>Technische Daten</h1>
    </div>
  </div>

  <table class="data-table no-break">
    <thead><tr><th>Eigenschaft</th><th>Wert</th></tr></thead>
    <tbody>
      <tr><td><strong>Mikrocontroller</strong></td><td>ESP32-S3</td></tr>
      <tr><td><strong>Nixie-Ansteuerung</strong></td><td>4× MCP23017 I²C Port-Expander (0x20–0x23), direkte Ansteuerung ohne Multiplexing</td></tr>
      <tr><td><strong>Nixie-Röhren</strong></td><td>6 Stück</td></tr>
      <tr><td><strong>Nixie-Hochspannung</strong></td><td>170–180 V DC</td></tr>
      <tr><td><strong>Echtzeituhr</strong></td><td>DS1302 (ThreeWire-Interface, batteriegepuffert)</td></tr>
      <tr><td><strong>NeoPixel</strong></td><td>10× WS2812B (6 Hintergrund + 4 Trennpunkte), Pin GPIO21</td></tr>
      <tr><td><strong>IR-Empfänger</strong></td><td>VS1838 (38 kHz), Pin GPIO48</td></tr>
      <tr><td><strong>I²C-Bus</strong></td><td>SDA = GPIO8, SCL = GPIO9</td></tr>
      <tr><td><strong>Taster</strong></td><td>SET = GPIO13, UP = GPIO14, DOWN = GPIO15, LIGHT = GPIO16</td></tr>
      <tr><td><strong>Versorgungsspannung</strong></td><td>5 V (Logik) + HV-Netzteil für Nixies</td></tr>
      <tr><td><strong>Web-Interface</strong></td><td>HTTP, Port 80, AP + STA Dual-Mode</td></tr>
      <tr><td><strong>NTP-Zeitzone</strong></td><td>CET-1CEST (Mitteleuropa, automatische Sommerzeit)</td></tr>
    </tbody>
  </table>

  <!-- Abschlussornament -->
  <div style="text-align:center;margin-top:10mm">
    <svg width="220" height="14" viewBox="0 0 220 14">
      <line x1="0" y1="7" x2="88" y2="7" stroke="#b8860b" stroke-width="1"/>
      <polygon points="100,7 106,3 112,7 106,11" fill="none" stroke="#b8860b" stroke-width="1"/>
      <line x1="122" y1="7" x2="220" y2="7" stroke="#b8860b" stroke-width="1"/>
    </svg>
    <div style="font-size:9pt;color:var(--hdr-txt);margin-top:4mm;letter-spacing:2px;font-style:italic">
      Nixie Clock Ultra &middot; Version 2.0 &middot; Juni 2026
    </div>
  </div>
</div>
```

- [ ] **Schritt 9.3: Im Browser prüfen**

Erwartetes Ergebnis: Seite 13 (Persistenz-Tabelle + Info-Box), Seite 14 (Technische Daten, 12 Zeilen, großes Abschluss-Ornament).

- [ ] **Schritt 9.4: Commit**

```bash
git add docs/manual/nixie-clock-ultra-bedienungsanleitung.html
git commit -m "feat: Kapitel VIII Persistenz, Kapitel IX Technische Daten"
```

---

## Task 10: Druckoptimierung & Abnahme

**Files:**
- Modify: `docs/manual/nixie-clock-ultra-bedienungsanleitung.html` — CSS `@media print` ergänzen

- [ ] **Schritt 10.1: Druckvorschau testen**

Datei in Chrome öffnen → `Strg+P`:
- Ziel: **Als PDF speichern**
- Papierformat: A4
- Ränder: **Keine** (Ränder kommen aus CSS)
- Hintergrundgrafiken: **aktivieren** ← wichtig, sonst fehlen Pergament-Farben und SVG-Dekos

Erwartetes Ergebnis: 14 Seiten, Titelseite ohne laufenden Kopf, alle Kapitel starten auf neuer Seite, keine Tabellen oder Warnboxen werden mittendurch getrennt.

- [ ] **Schritt 10.2: Falls Seitenumbrüche schlecht fallen — CSS anpassen**

Füge im `@media print`-Block gezielte Ergänzungen hinzu wenn nötig. Beispiel: Kapitel V fällt auf zwei Seiten → füge `page-break-before: always` auf dem jeweiligen `h2` ein:

```css
@media print {
  /* Kapitel-spezifische Umbrüche bei Bedarf: */
  .page h2.new-page { page-break-before: always; }
}
```

Und im HTML z.B.:
```html
<h2 class="new-page">Animationsmodi</h2>
```

- [ ] **Schritt 10.3: PDF generieren und prüfen**

`Strg+P` → Als PDF speichern → `nixie-clock-ultra-bedienungsanleitung.pdf`  
Öffne das PDF und prüfe:
- Titelseite korrekt zentriert
- Alle Ornament-SVGs sichtbar
- Nixie-Röhren mit orange Schimmer
- Alle Tabellen vollständig (kein Abschnitt am Seitenende)
- Seitenzahlen in Kopfzeilen korrekt

- [ ] **Schritt 10.4: Abschluss-Commit**

```bash
git add docs/manual/nixie-clock-ultra-bedienungsanleitung.html
git commit -m "feat: Steampunk Bedienungsanleitung vollständig – druckfertig als PDF"
```

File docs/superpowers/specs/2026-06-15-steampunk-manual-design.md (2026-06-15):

# Design-Spec: Steampunk Bedienungsanleitung – Nixie Clock Ultra

**Datum:** 2026-06-15  
**Status:** Freigegeben  

---

## Ziel

Erstellung einer hochwertigen Bedienungsanleitung für die Nixie Clock Ultra im Steampunk-Stil, als druckfertiges PDF.

---

## Format & Erzeugung

- **Ausgabeformat:** PDF, A4 Hochformat
- **Erzeugung:** Einzelne selbst-enthaltene HTML-Datei mit `@media print` CSS → User öffnet in Chrome/Firefox → `Strg+P` → „Als PDF speichern"
- **Kein externes Tool** (kein Pandoc, kein LaTeX, kein WeasyPrint) erforderlich
- Die HTML-Datei verbleibt im Repo und dient gleichzeitig als interaktive Vorschau

---

## Visueller Stil: Elegant & Zeitlos

### Farbpalette

| Element | Farbe | Hex |
|---|---|---|
| Seitenhintergrund | Pergament | `#f7f2e8` / `#f0ebe0` |
| Überschriften | Dunkelbraun  | `#2c1810` |
| Fließtext | Dunkelbraun  | `#3d2b00` |
| Gold-Akzente | Messing-Gold | `#b8860b` |
| Gold-Ornamente | Dunkelgold | `#8b6914` |
| Tabellenkopf | Dunkelgold | `#8b6914` (Hintergrund), `#f7f2e8` (Text) |
| Warnbox-Rand | Dunkelrot | `#8b0000` |
| Laufkopf / Fußnoten  | Goldbraun | `#a08040` |

### Schriften

- **Überschriften & Titel:** Georgia, serif
- **Fließtext:** Georgia, serif (11 pt im Druck)
- Keine externen Web-Fonts (selbst-enthalten)

### Steampunk-Dekorationselemente (alle als inline SVG)

1. **Eckverzierungen** auf Titel- und Kapitelseiten: L-förmige Goldlinien mit Punkt
2. **Ornamentlinie** als Trenner: Horizontale Linie mit Raute/Pfeil-Mittelpunkt
3. **Zahnrad-Icon** am Kapitelheader (8-zähniges SVG-Zahnrad, ~28×28px)
4. **Nixie-Röhren-Illustration** auf der Titelseite: 6 stilisierte Röhren mit orange leuchtendem Schimmer (SVG, Radial-Gradient)
5. **Laufende Kopfzeile** auf jeder Innenseite: Dokumenttitel links, ⚙ + Seitenzahl rechts, getrennt durch dünne Goldlinie

---

## Seitenaufbau

### Titelseite (Seite 1)

- Pergament-Hintergrund mit leichtem Gradient
- 4 Eckverzierungen (SVG)
- Ornamentlinie oben
- Zentrierter Titelblock:
  - SVG-Zahnrad-Ornament
  - Haupttitel: „Nixie Clock Ultra" (22 pt, bold, letter-spacing)
  - Doppelte Goldlinie mit eingebettetem Text: „Bedienungsanleitung"
  - Untertitel: „Modell ESP32-S3 · 6 Nixie-Röhren"
- Nixie-Röhren-Illustration (6 Röhren mit Leuchtschimmer, Doppelpunkt-LEDs)
- Ornamentlinie unten
- Versionszeile: „Version 2.0 · Juni 2026"

### Inhaltsverzeichnis (Seite 2)

- Gleicher Pergament-Hintergrund, Eckverzierungen
- Zentrierte Überschrift „Inhalt" mit Ornamentlinie darunter
- 9 Einträge mit gepunkteten Leitlinien und rechtsbündigen Seitenzahlen
- Abschluss-Ornament

### Kapitelseiten (Seiten 3–14)

- **Laufende Kopfzeile:** „Nixie Clock Ultra · Bedienungsanleitung" | ⚙ [Seitenzahl]
- **Kapitelheader:** Kleines SVG-Zahnrad + „Kapitel [Römisch]" (klein, gold) + Kapiteltitel (groß)
- **Goldene Trennlinie** unter dem Header (Gradient: gold → transparent)
- **Fließtext:** Georgia 10.5 pt, Zeilenabstand 1.7, Dunkelbraun
- **Fußlinie:** Ornament-Linie (Linie–Kreis–Linie)

---

## Kapitelstruktur

| Nr.  | Titel | Inhalt |
|---|---|---|
| I | Übersicht & Sicherheit | Kurzbeschreibung, Hochspannungswarnung (Warnbox), Lieferumfang |
| II | Inbetriebnahme | Erststart, Fade-In, RTC-Anzeige, Grundzustand |
| III  | Tasten & Bedienung | SET/UP/DOWN/LIGHT, Kurz- und Langdruck, Tabelle |
| IV | Zeit einstellen | Schritt-für-Schritt per Taste, 15-s-Timeout, nummerierte Schritte  |
| V | Beleuchtung & Animationen | 4 Helligkeitsstufen, Animationsmodi, Trennpunkt-LEDs, Farbwahl |
| VI | IR-Fernbedienung | Funktionsübersicht (Tabelle), Anlernen, Löschen |
| VII  | WLAN & Web-Interface | AP-Modus, Heimnetz, NTP-Sync, alle Web-UI-Funktionen |
| VIII | Einstellungen & Persistenz | Was im Flash gespeichert wird |
| IX | Technische Daten | ESP32-S3, MCP23017, DS1302, WS2812B, Spannungen, Pins |

---

## Wiederkehrende Inhaltselemente

### Tabellen
- Kopfzeile: Hintergrund `#8b6914`, Text `#f7f2e8`, kein Fettdruck
- Zeilen alternierend: `#f7f2e8` / `#f0ebe0`
- Trennlinien: `#d3c9a8`

### Warnbox (Hochspannungshinweis)
- Linker Rand: 4px solid `#8b0000`
- Umrandung: 1px solid `#b8860b`
- Hintergrund: `#fff8f0`
- SVG-Warndreieck, Titel in Kapitälchen, roter Text

### Nummerierte Schritte
- Goldene Kreise (∅ 16px, Hintergrund `#8b6914`, Text `#f7f2e8`) als Schritt-Nummer
- Fließtext rechts daneben

### Ornamentlinie (Trenner)
```
────────── ◇ ──────────
```
Als SVG: Linie links, Raute/Pfeil mittig, Linie rechts

---

## Ausgabedatei

`docs/manual/nixie-clock-ultra-bedienungsanleitung.html`

Zum Druck: Chrome → `Strg+P` → Ziel: „Als PDF speichern" → A4, Ränder: Keine (Ränder im CSS definiert), Hintergrundgrafiken: **aktivieren**.

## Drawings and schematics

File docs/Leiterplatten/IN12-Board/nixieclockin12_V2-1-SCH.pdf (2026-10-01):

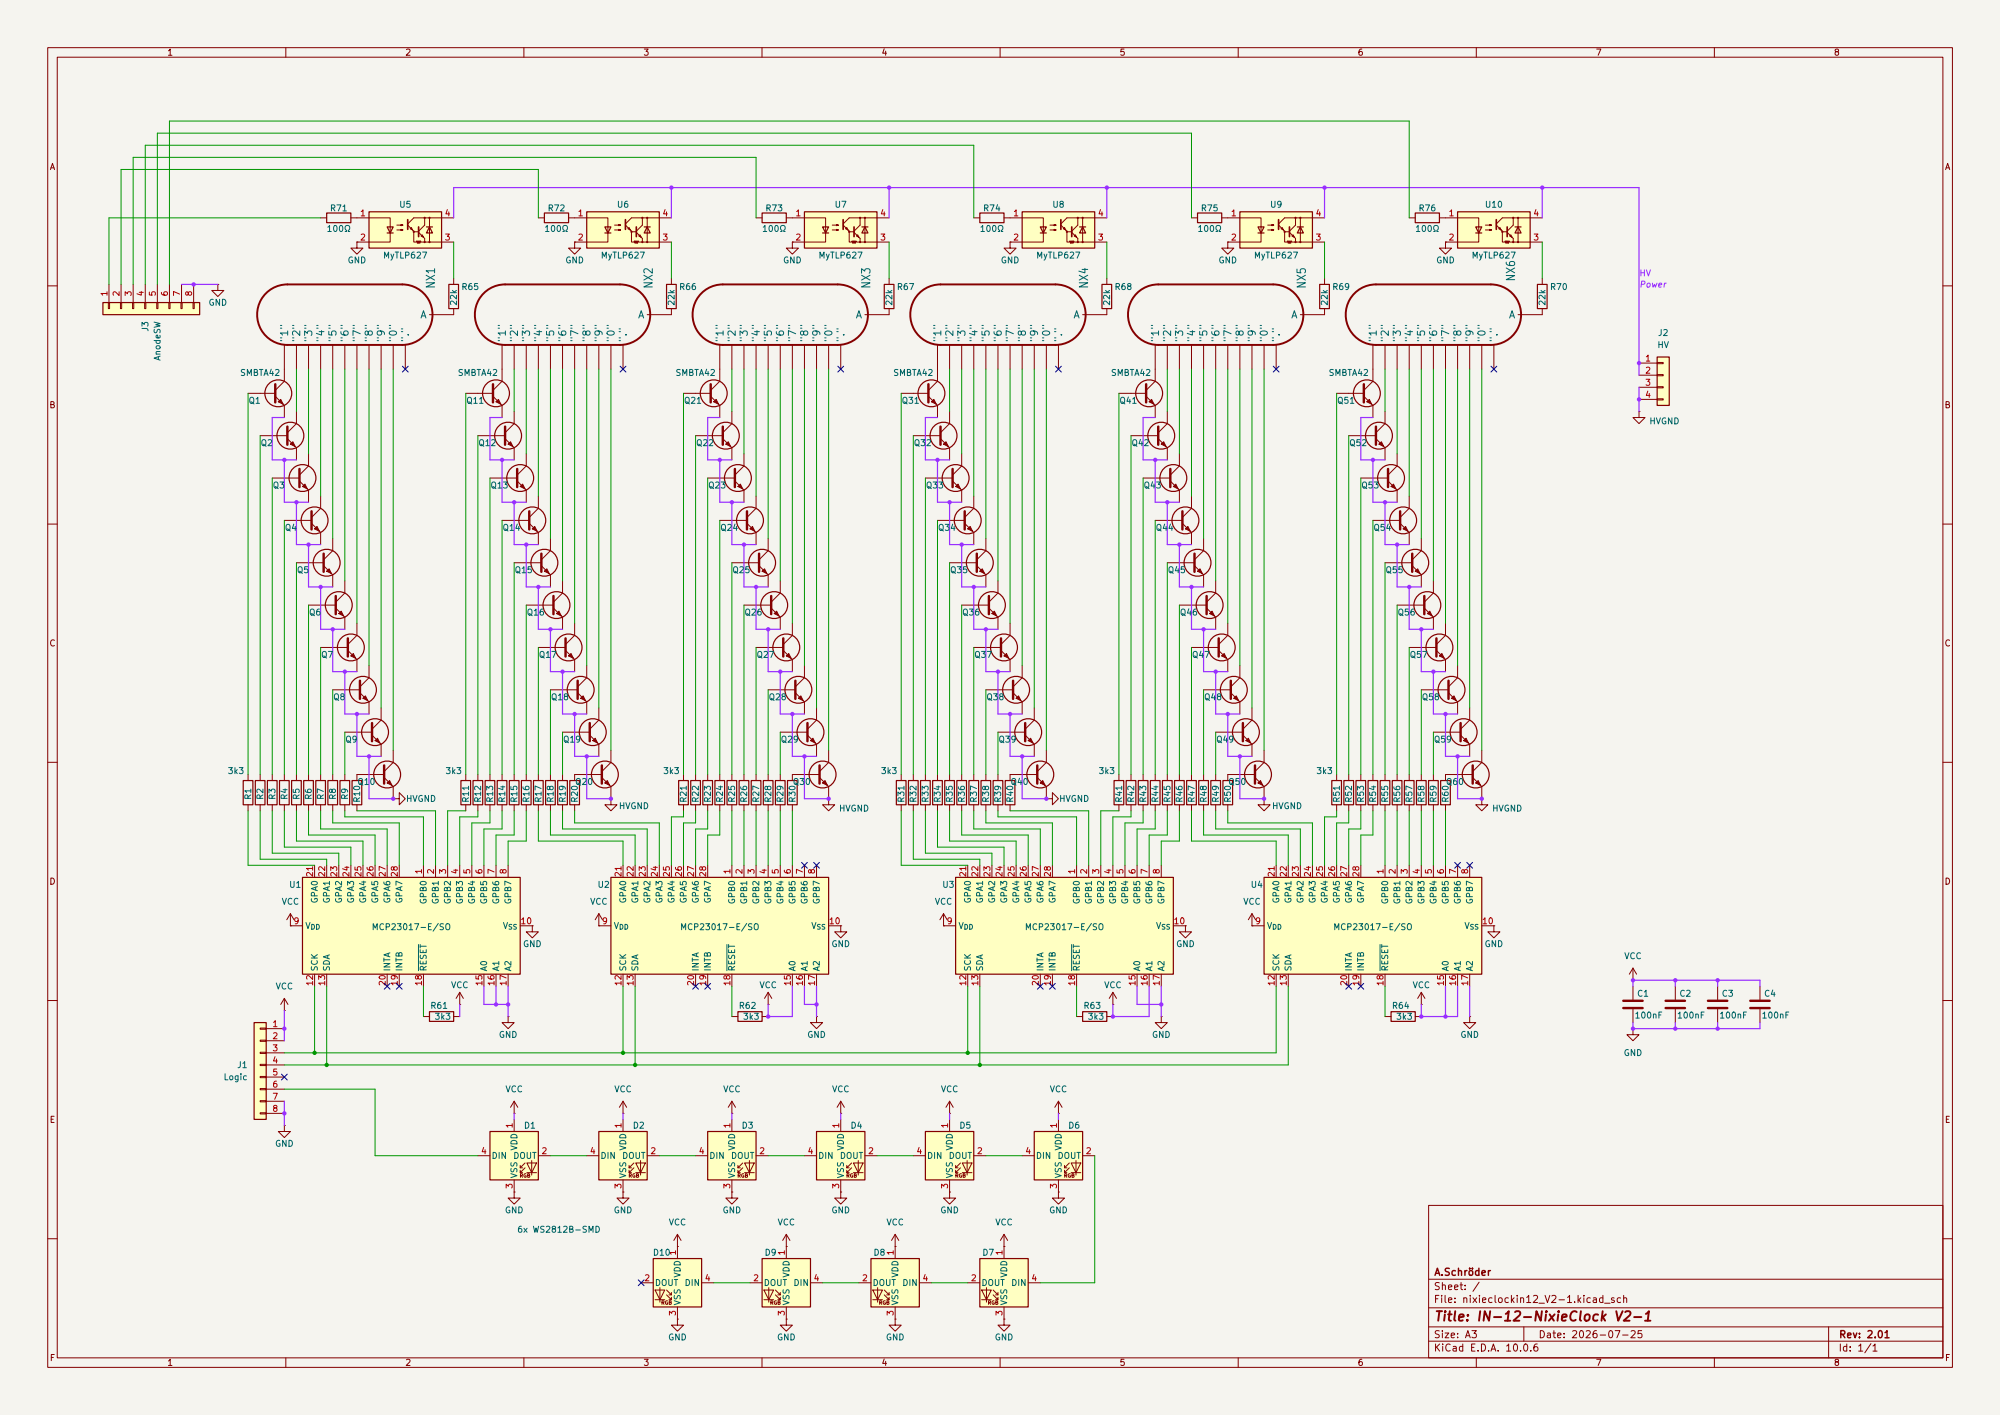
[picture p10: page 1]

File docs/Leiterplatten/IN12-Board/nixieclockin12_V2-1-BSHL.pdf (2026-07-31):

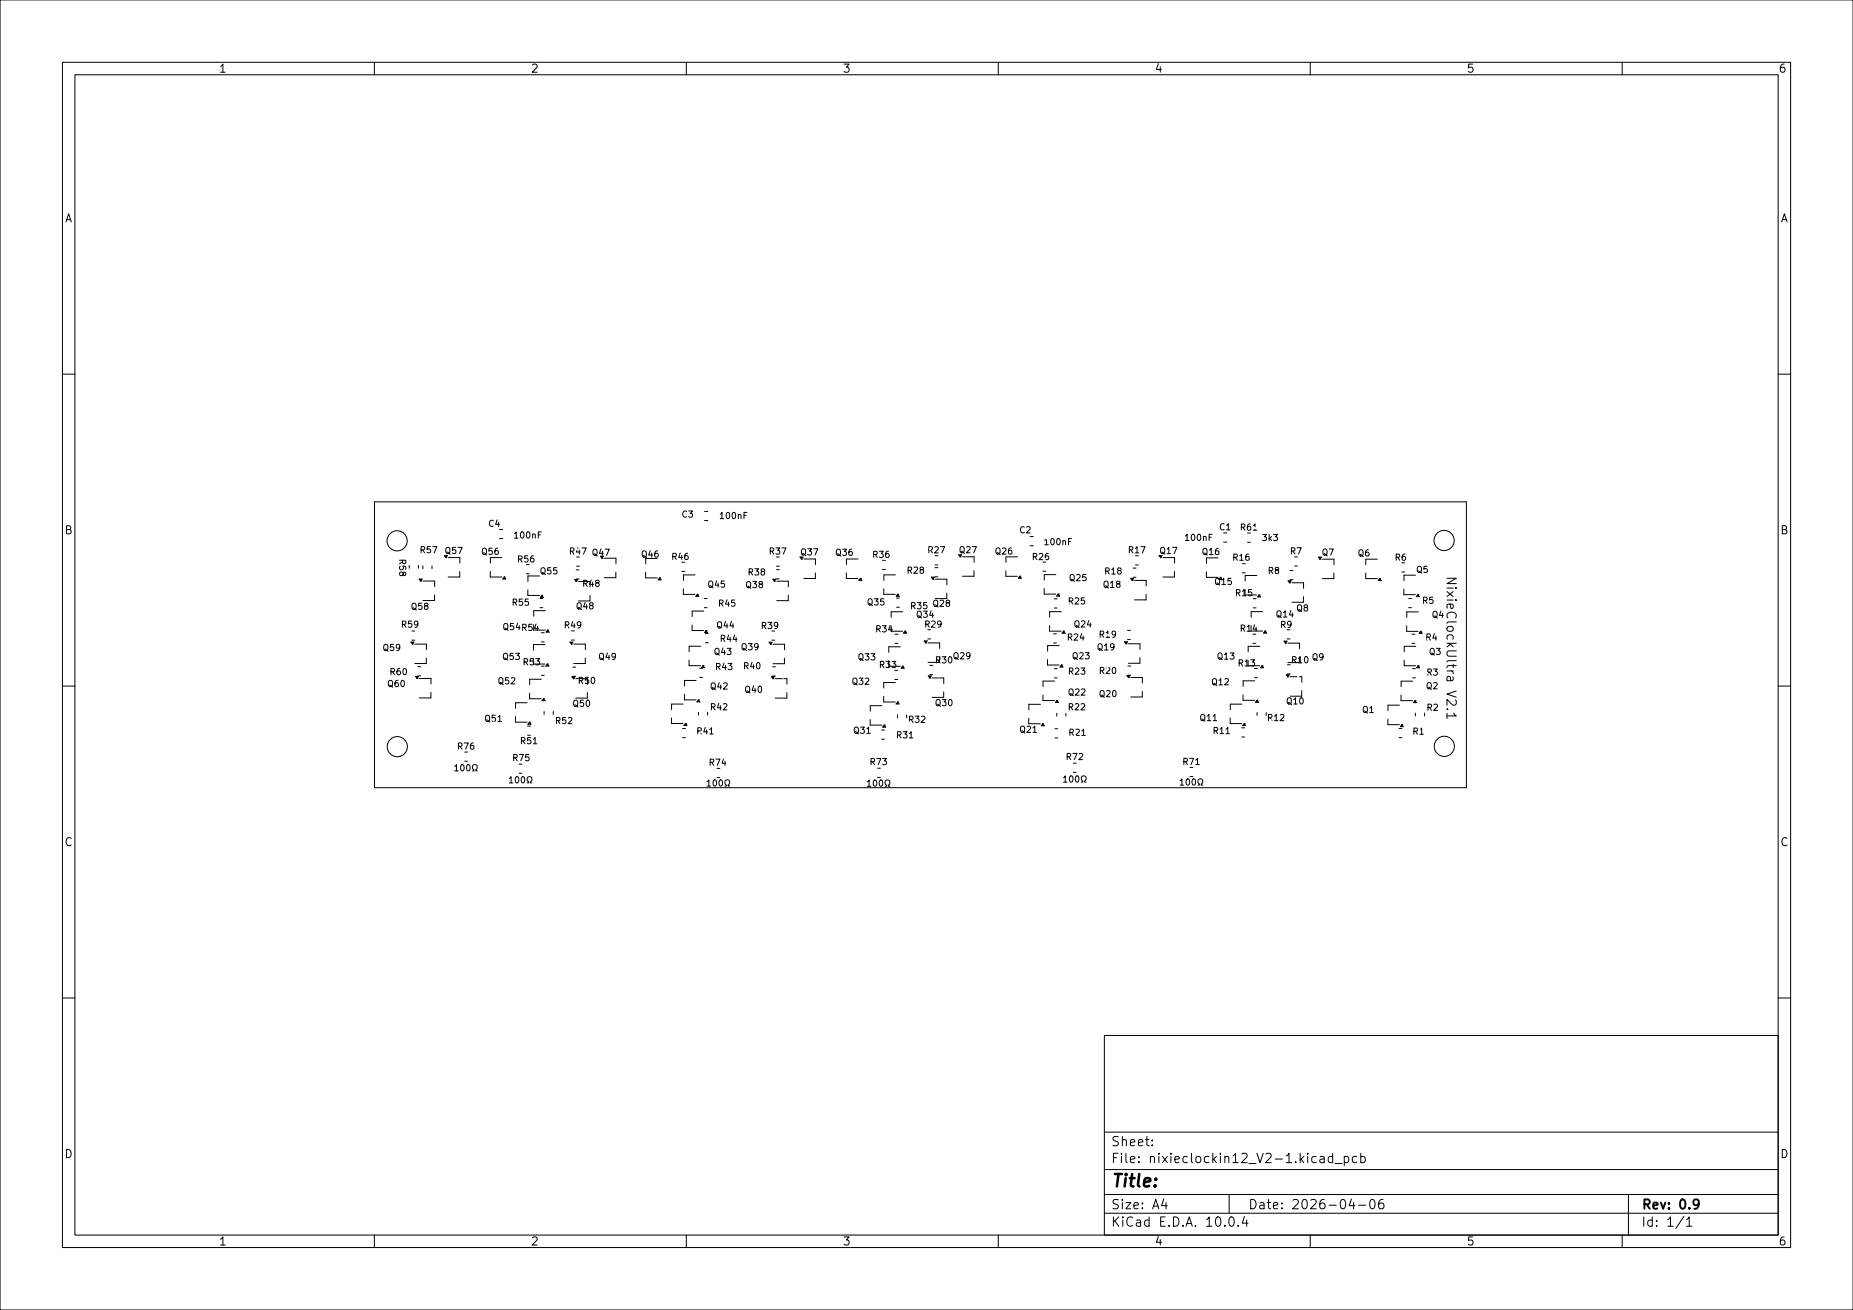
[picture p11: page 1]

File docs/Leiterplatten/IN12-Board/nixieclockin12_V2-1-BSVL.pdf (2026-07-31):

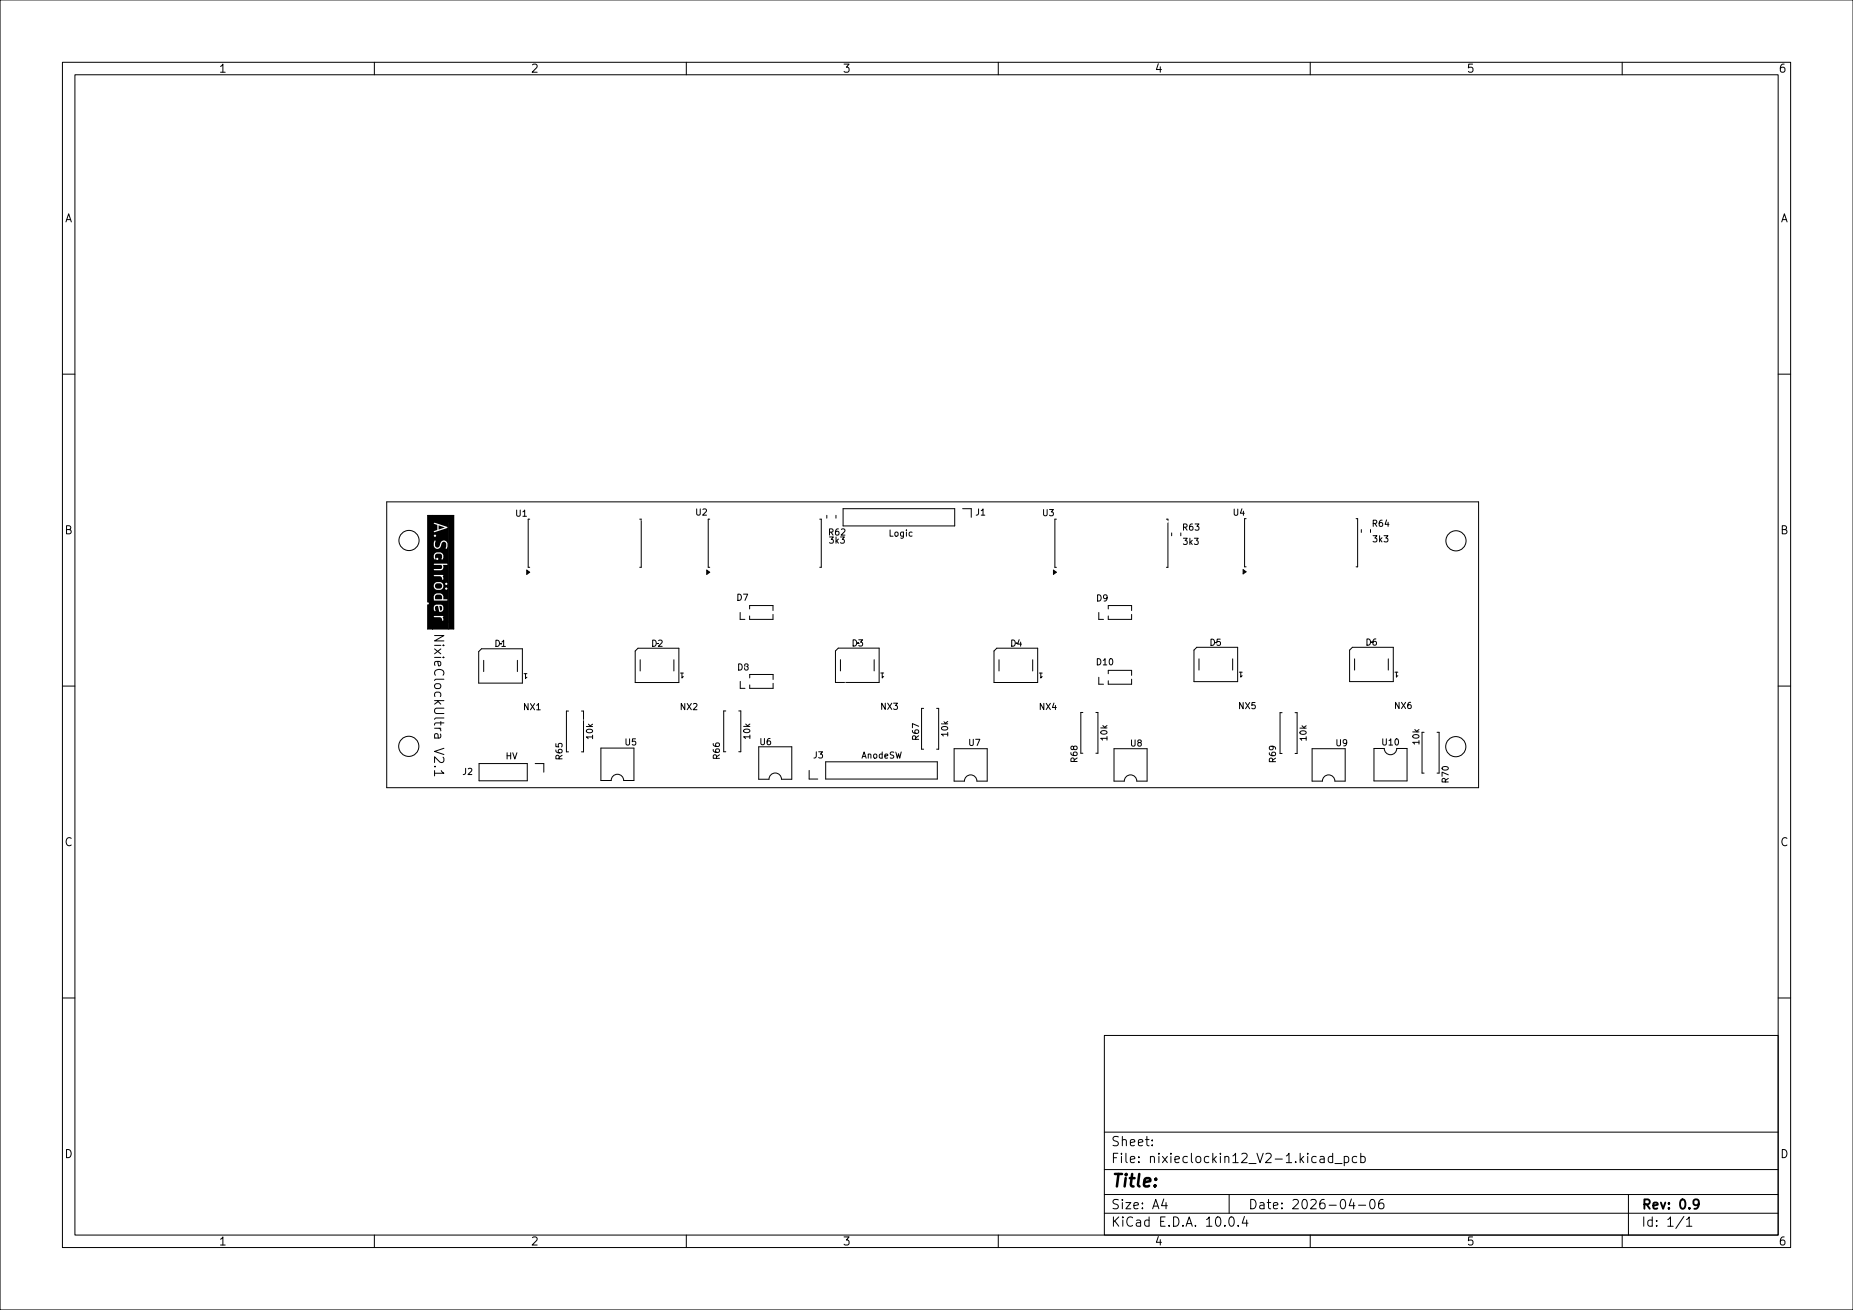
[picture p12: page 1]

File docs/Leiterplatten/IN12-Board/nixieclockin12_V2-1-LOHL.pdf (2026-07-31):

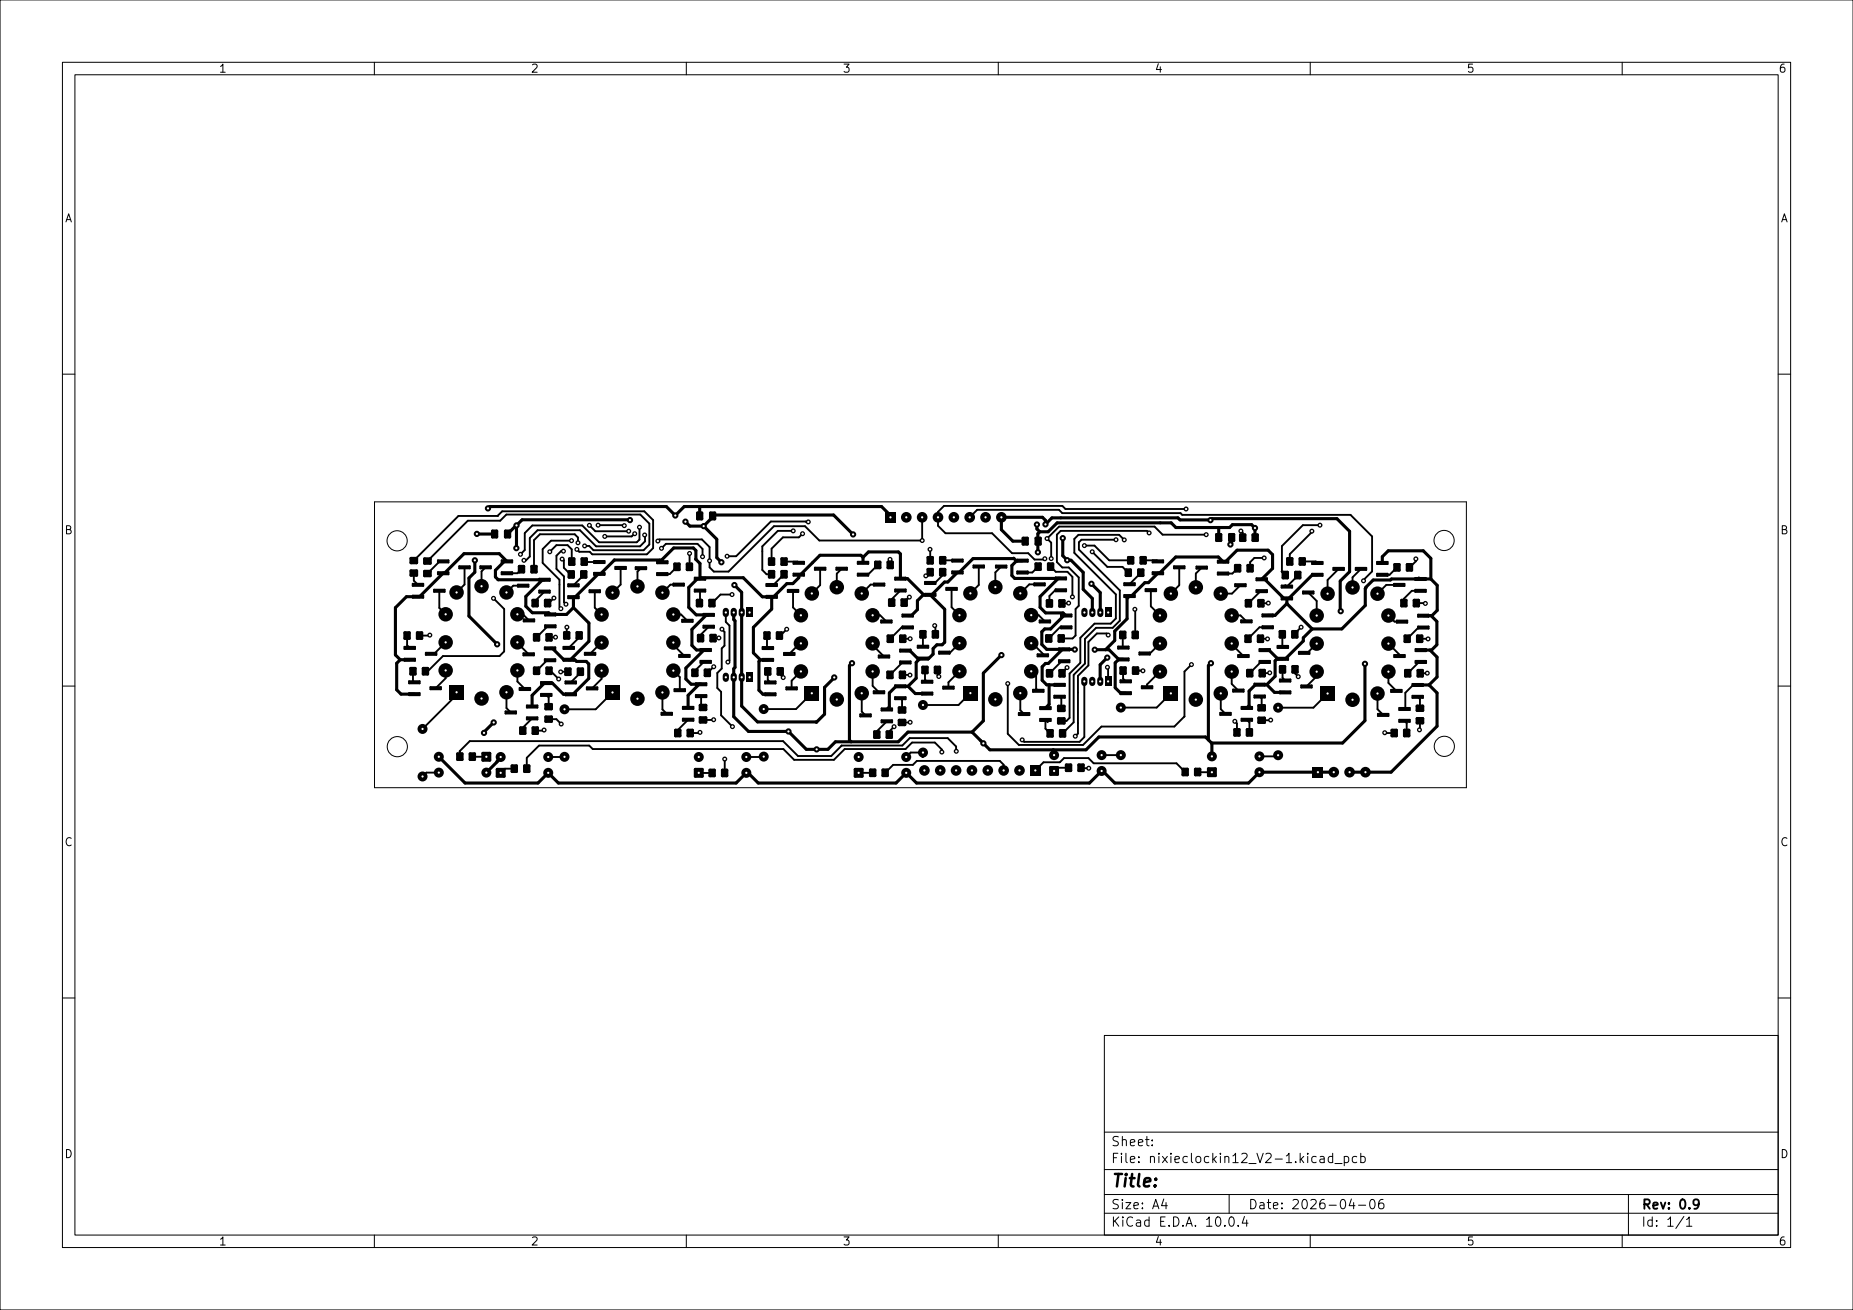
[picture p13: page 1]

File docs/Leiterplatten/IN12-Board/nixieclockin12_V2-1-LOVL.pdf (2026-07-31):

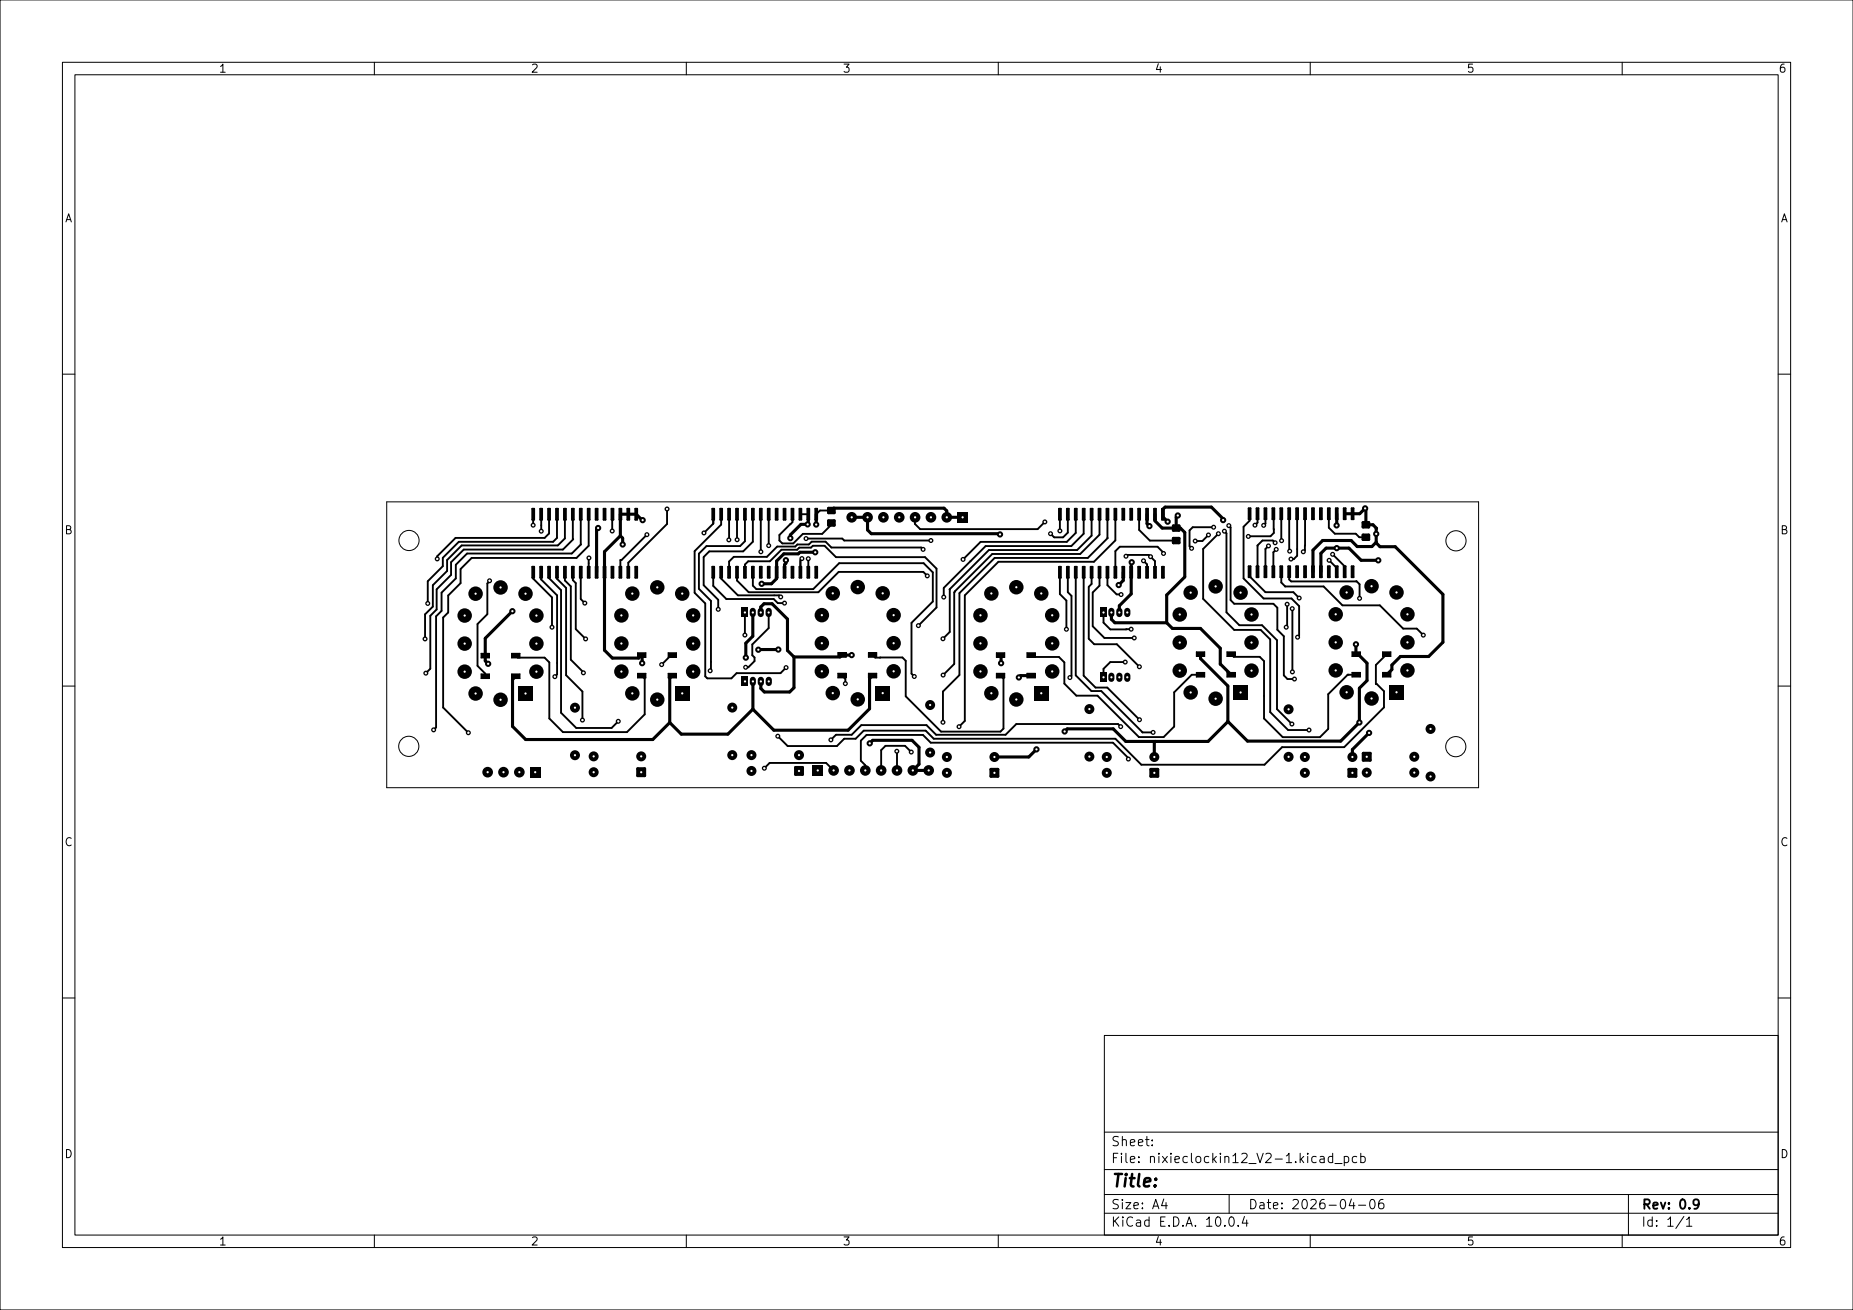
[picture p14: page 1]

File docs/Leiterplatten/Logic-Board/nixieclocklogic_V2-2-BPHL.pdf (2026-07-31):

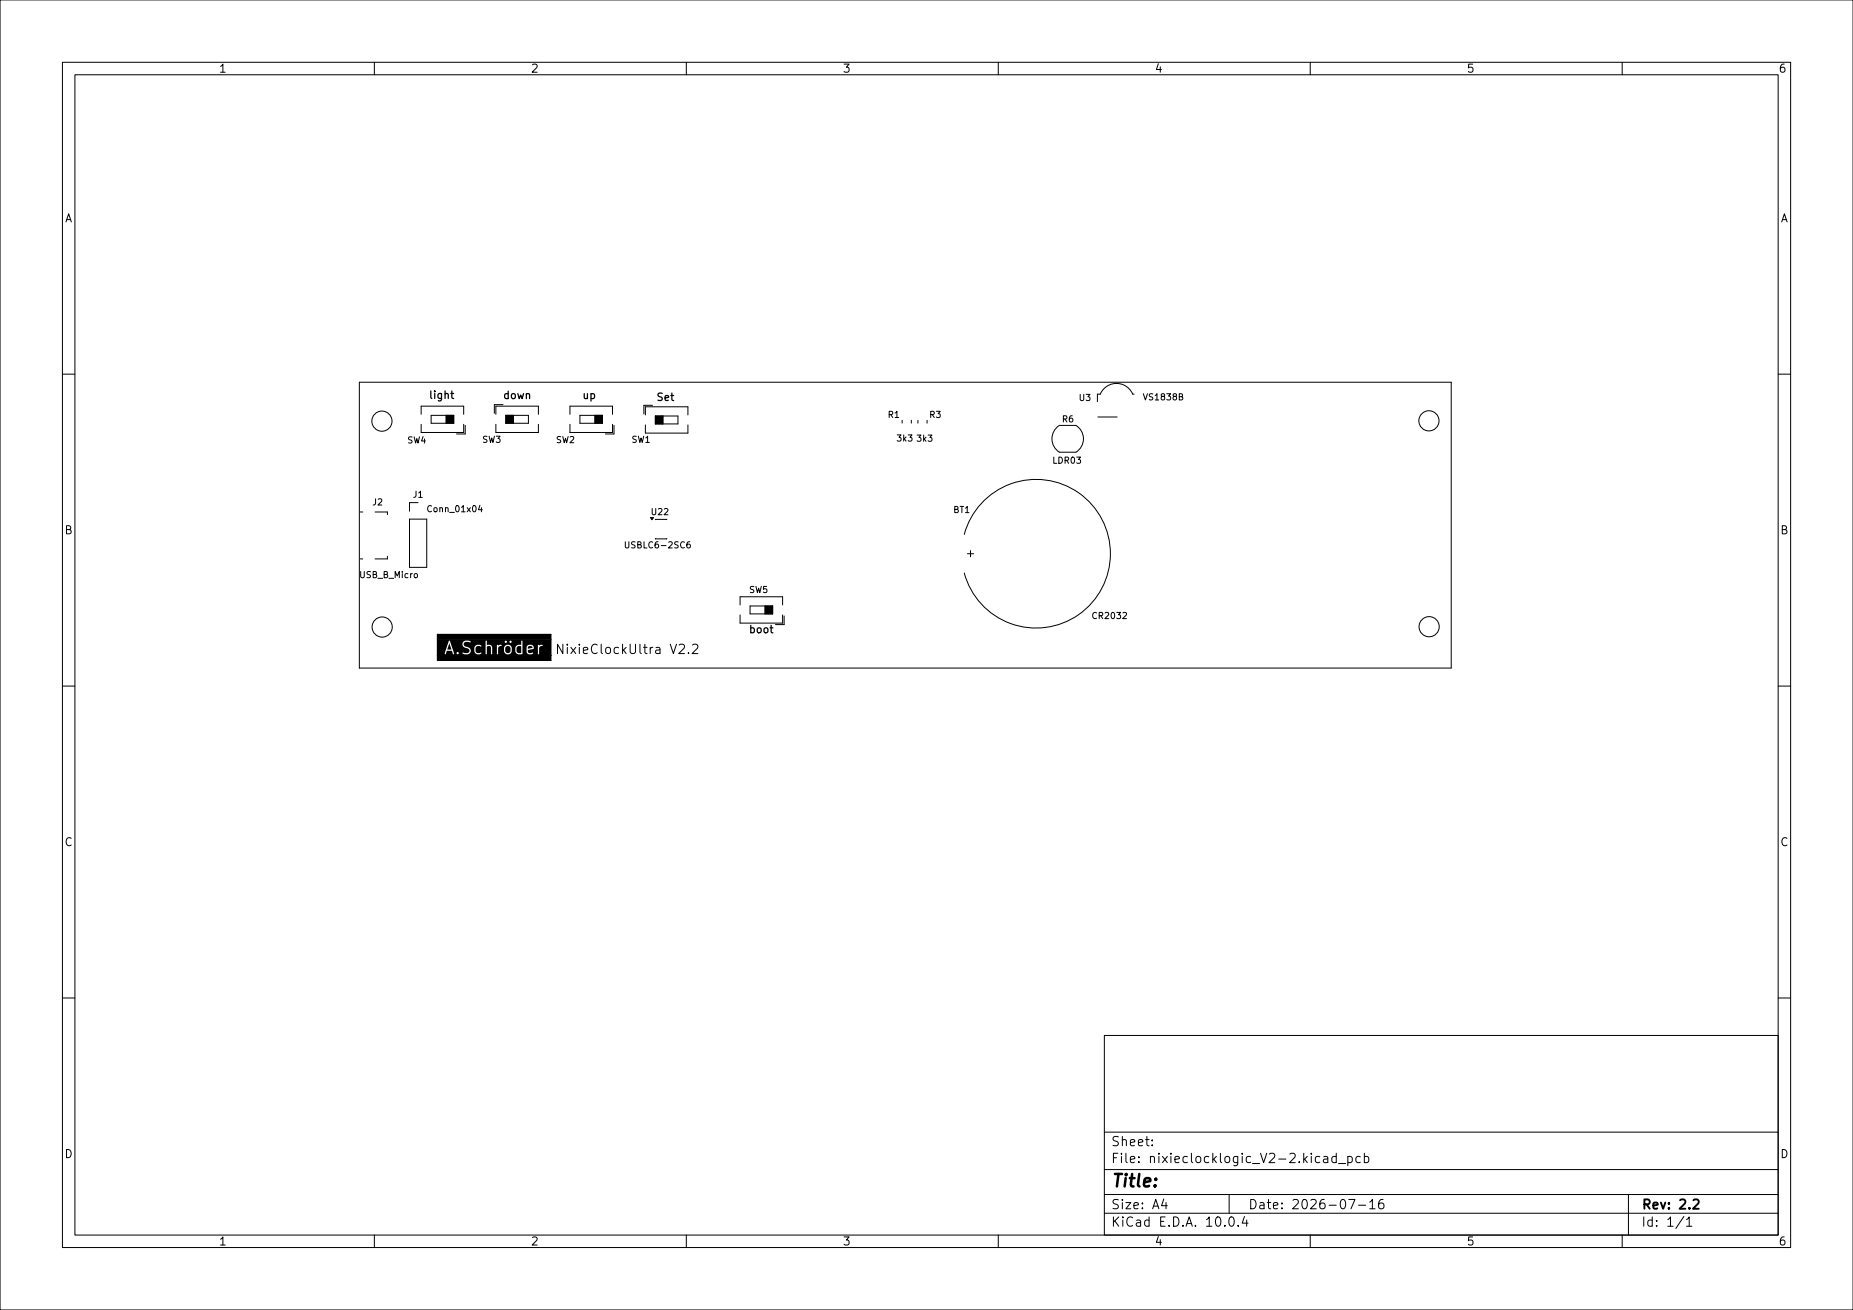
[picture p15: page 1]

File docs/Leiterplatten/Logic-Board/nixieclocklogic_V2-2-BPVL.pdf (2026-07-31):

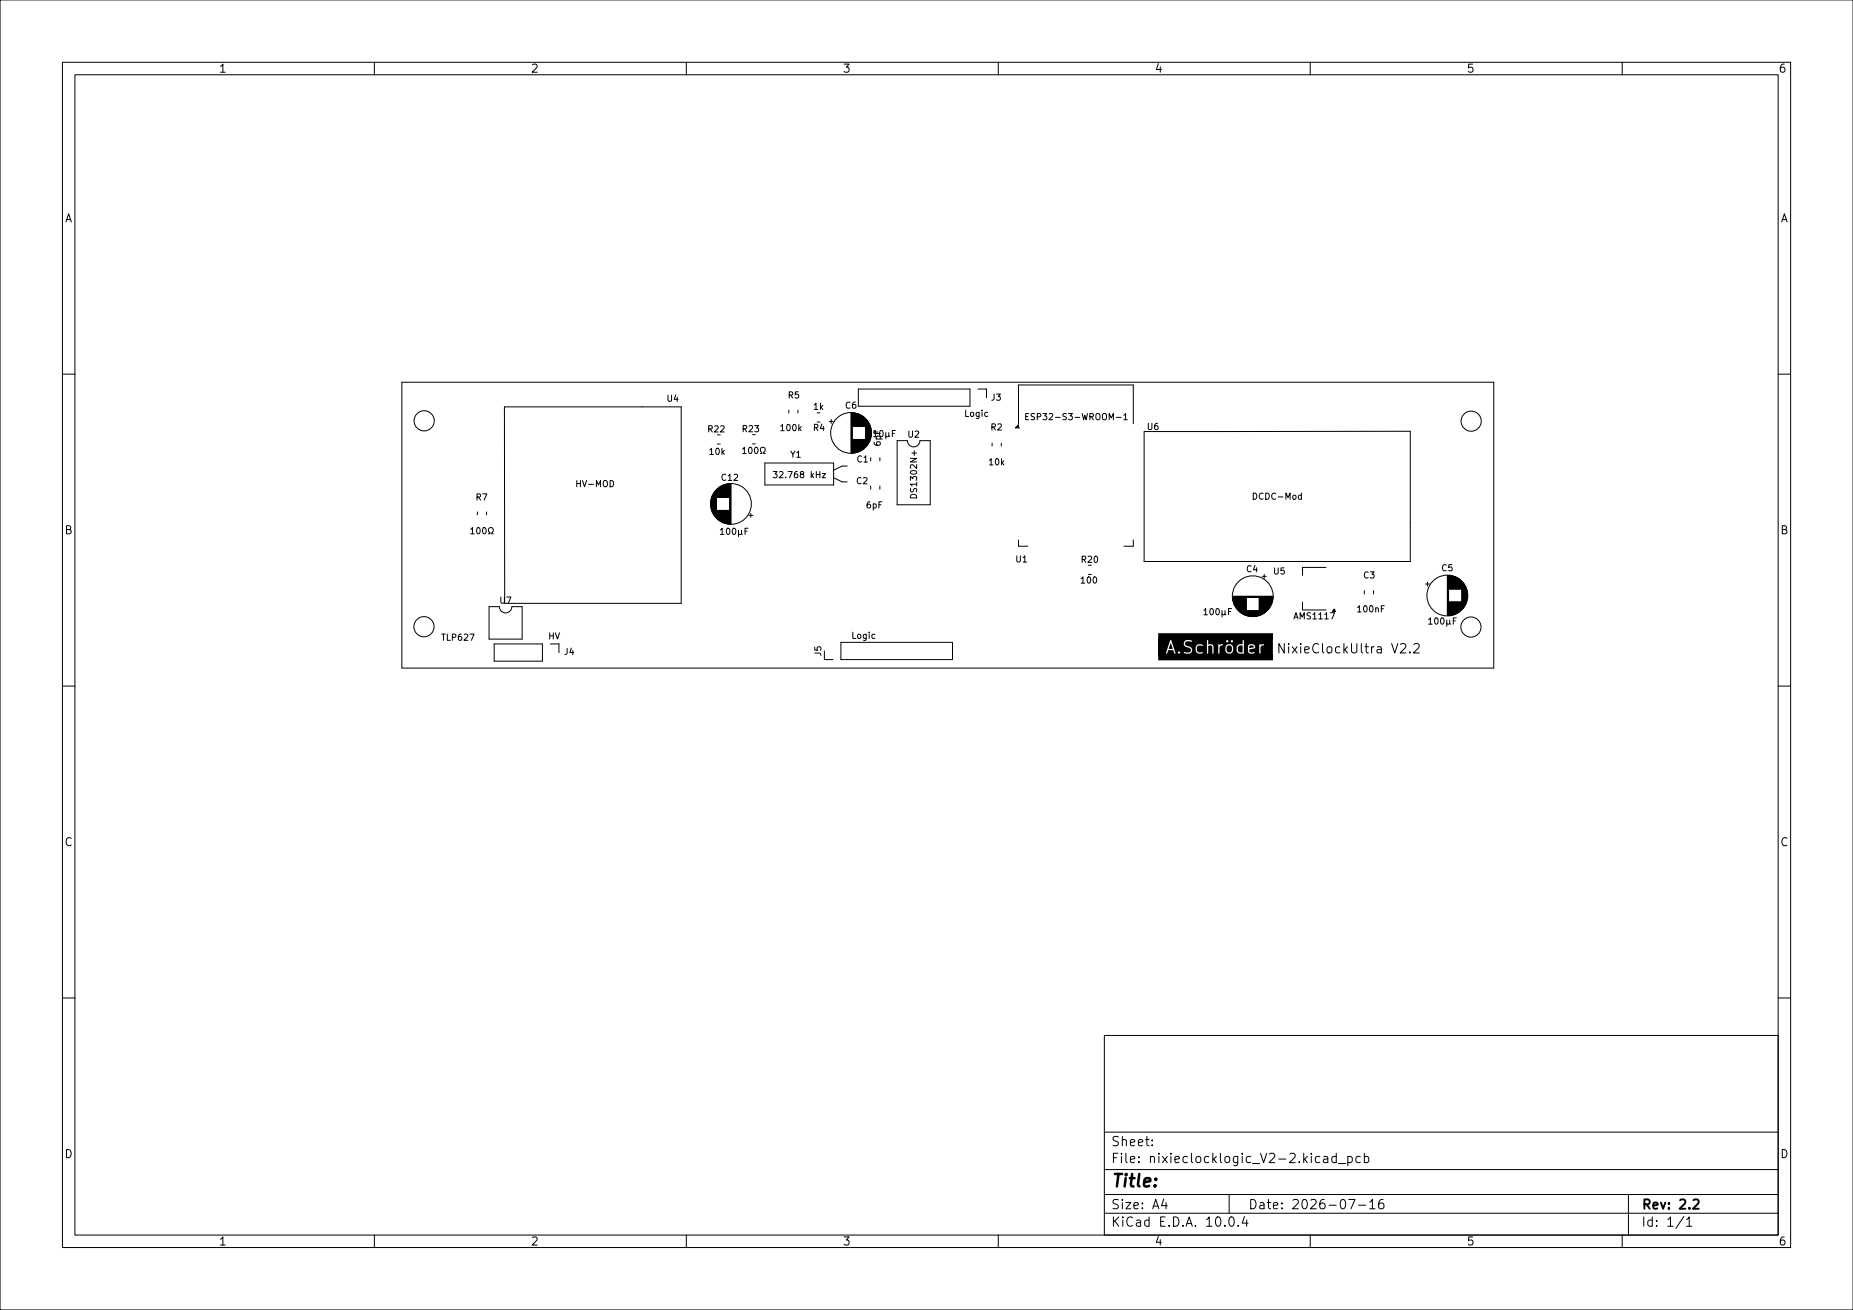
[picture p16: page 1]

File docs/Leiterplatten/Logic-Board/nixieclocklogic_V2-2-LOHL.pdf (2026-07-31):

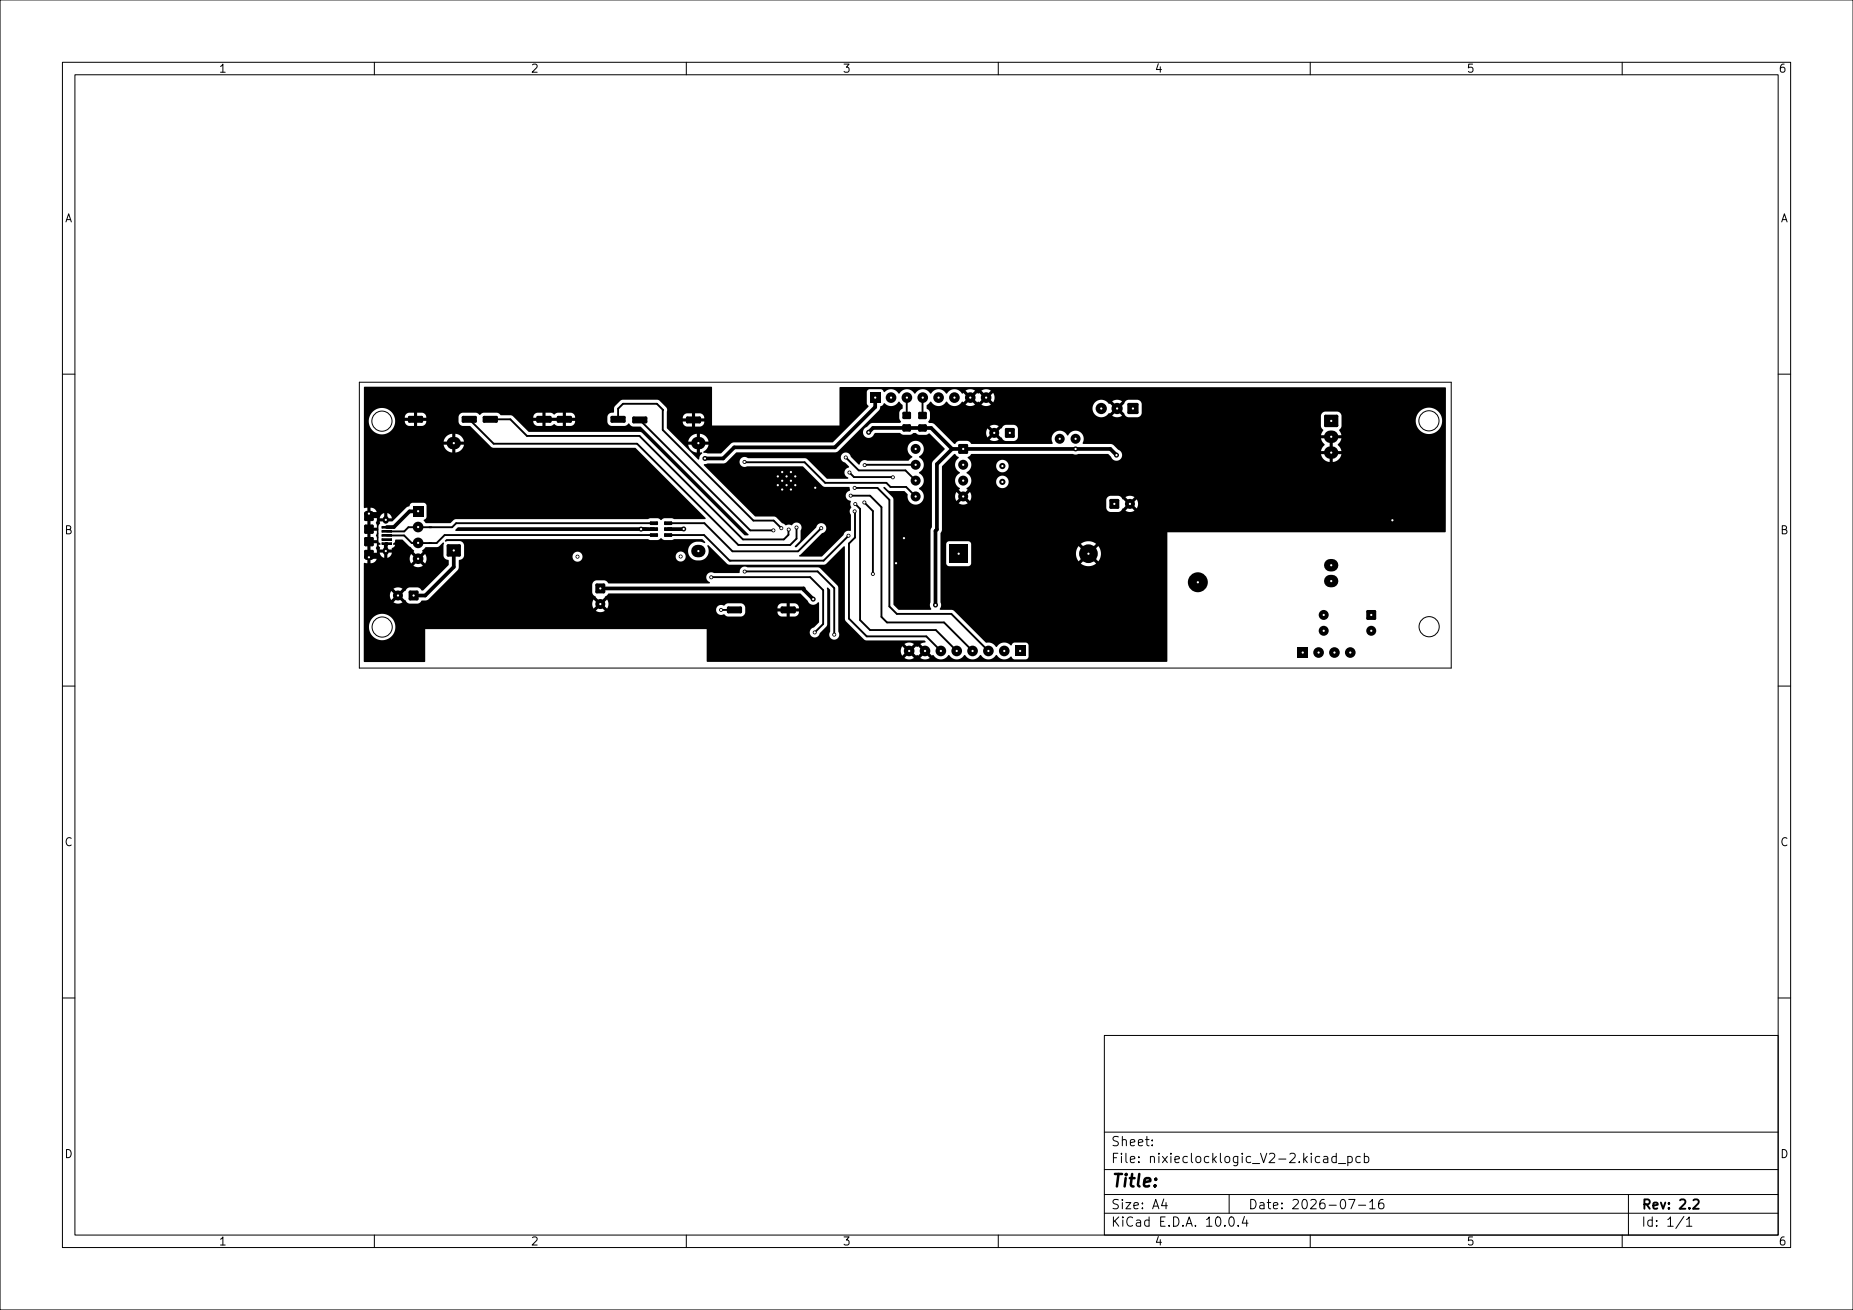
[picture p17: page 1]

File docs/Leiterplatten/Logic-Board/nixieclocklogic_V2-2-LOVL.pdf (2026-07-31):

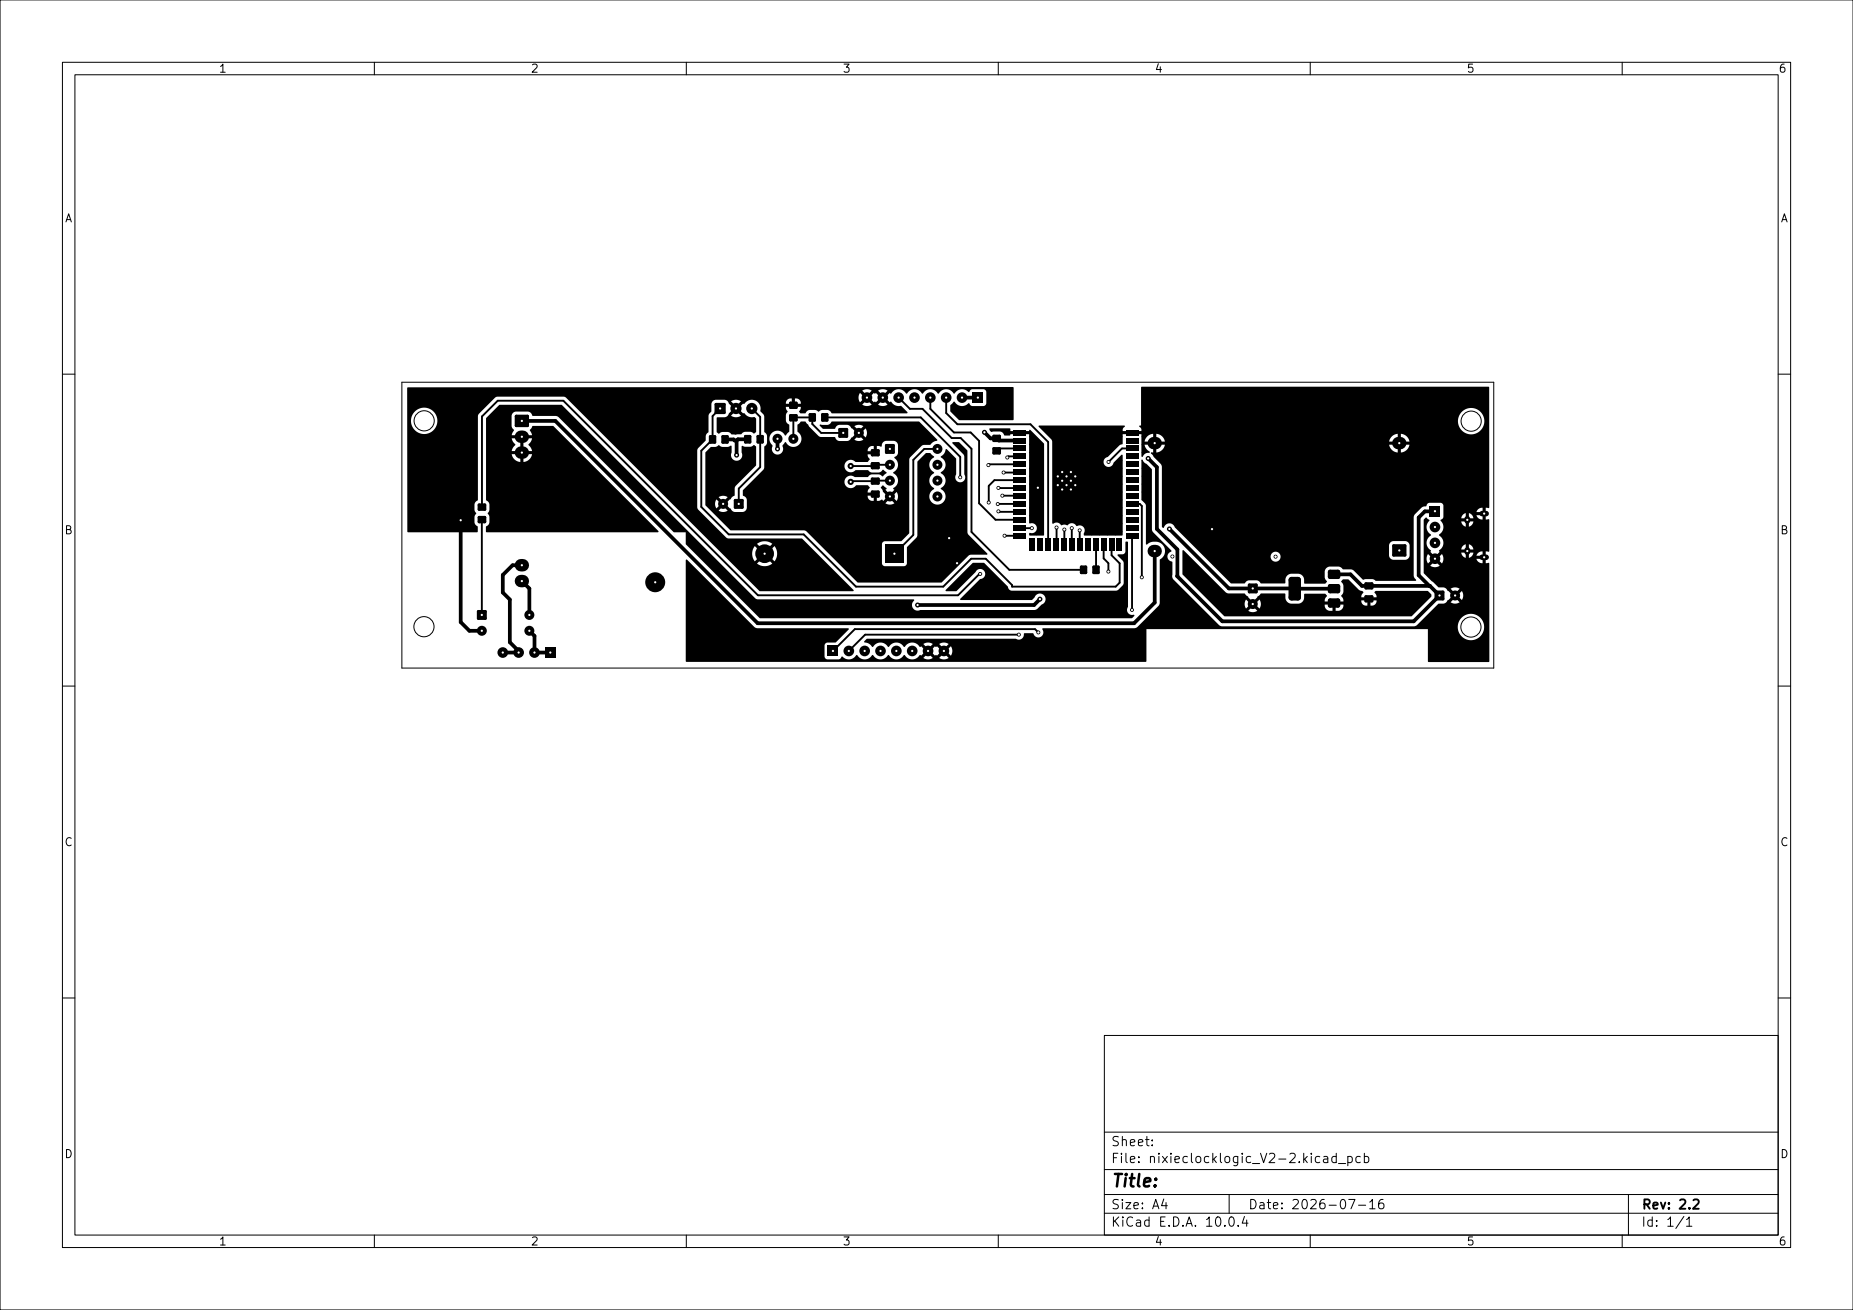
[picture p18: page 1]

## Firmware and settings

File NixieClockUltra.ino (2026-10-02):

/*
 * ╔══════════════════════════════════════════════════════════════════════╗
 * ║               NIXIE TUBE CLOCK – ESP32-S3 Firmware                   ║
 * ║         6x Nixie | DS1302 RTC | 10x NeoPixel | Web UI                ║
 * ║                                                                      ║
 * ║  Architektur:                                                        ║
 * ║   • Direkte Ansteuerung via 4× MCP23017 (I2C)                        ║
 * ║   • Entprellte Taster (FSM)                                          ║
 * ║   • Fade-In / Fade-Out je Röhre                                      ║
 * ║   • NeoPixel Farbverlauf + Animationen                               ║
 * ║   • Helligkeitssteuerung (4 Stufen)                                  ║
 * ║   • Web-Interface (WiFi AP)                                          ║
 * ║   • IR-Interface                                                     ║
 * ║   • DS1302 RTC Handling + Einstellmodus                              ║
 * ╚══════════════════════════════════════════════════════════════════════╝
 *
 *  Benötigte Bibliotheken (Arduino Library Manager):
 *    - Adafruit NeoPixel   (Adafruit)
 *    - Rtc by Makuna        (Michael C. Miller)   ← DS1302 Support
 *    - AsyncTCP             (me-no-dev)
 *    - ESPAsyncWebServer    (me-no-dev)
 *    - ArduinoJson          (Benoit Blanchon)
 *    - IRremoteESP8266      (David Conran)
 */

// ═══════════════════════════════════════════════════════════
//  INCLUDES
// ═══════════════════════════════════════════════════════════
#include <Arduino.h>
#include <Adafruit_NeoPixel.h>
#include <RtcDS1302.h>
#include <ThreeWire.h>
#include <WiFi.h>
#include <AsyncTCP.h>
#include <ESPAsyncWebServer.h>
#include <ArduinoJson.h>
#include <Preferences.h>

// IR-Empfänger
#include <IRremoteESP8266.h>
#include <IRrecv.h>
#include <ESPmDNS.h>
#include "boot_diag.h"

// ═══════════════════════════════════════════════════════════
//  PIN-DEFINITIONEN
// ═══════════════════════════════════════════════════════════

// DS1302
#define RTC_IO_PIN   4
#define RTC_CLK_PIN  5
#define RTC_CE_PIN   2

// Taster (LOW-aktiv, Pull-Up intern)
#define BTN_SET      13
#define BTN_UP       12
#define BTN_DOWN     11
#define BTN_LIGHT    10

// NeoPixel
#define NEO_PIN      21
#define NEO_COUNT    10   // 6 Hintergrund + 4 Doppelpunkte

// IR-Empfänger
#define IR_RECV_PIN  48

// I2C für MCP23017
#define I2C_SDA      8
#define I2C_SCL      9

// HV-Dimmer (TLP627 → Anodenspannung)
#define HV_SWITCH_PIN  7   // Gemeinsamer Schalter (ohne HV_PER_TUBE_DIMMER)

// Bei bestücktem Pro-Röhre-HV-Schalter (6× TLP627 auf dem Nixie Display Board)
// einkommentieren. Ermöglicht, dass beim weichen Ziffernwechsel nur die Röhre
// abblendet, deren Ziffer sich tatsächlich ändert (statt aller 6 gemeinsam).
#define HV_PER_TUBE_DIMMER
#define HV_TUBE_PIN_0  38   // Stundenzehner  (HZ)
#define HV_TUBE_PIN_1  47   // Stundeneiner   (HE)
#define HV_TUBE_PIN_2  15   // Minutenzehner  (MZ)
#define HV_TUBE_PIN_3  16   // Minuteneiner   (ME)
#define HV_TUBE_PIN_4  17   // Sekundenzehner (SZ)
#define HV_TUBE_PIN_5  18   // Sekundeneiner  (SE)

// Sanftanlauf beim Einschalten: Röhren nacheinander aufblenden, um die
// Einschaltlast am Netzteil zeitlich zu entzerren (6 × 200 ms = 1,2 s).
#define HV_SOFTSTART_TUBE_MS  200   // Aufblenddauer je Röhre
#define HV_SOFTSTART_STEP_MS   10   // Schrittweite der Rampe

// ═══════════════════════════════════════════════════════════
//  KONSTANTEN & KONFIGURATION
// ═══════════════════════════════════════════════════════════

// Hintergrund-Warmweiß, ANIM_STATIC (R/G/B – Verwendung: strip.Color(BG_WARM_R, BG_WARM_G, BG_WARM_B))
#define BG_WARM_R  255
#define BG_WARM_G  130
#define BG_WARM_B    0

// Trennpunkt-Warmweiß (R/G/B – Verwendung: strip.Color(COLON_WARM_R, COLON_WARM_G, COLON_WARM_B))
#define COLON_WARM_R  255
#define COLON_WARM_G  100
#define COLON_WARM_B    0

// Fade
#define FADE_STEPS           20   // Schritte für Fade-In/Out
#define FADE_INTERVAL_MS      2   // ms zwischen Fade-Schritten

// Helligkeitsstufen (PWM 0–255 → werden als Duty-Cycle-Anteil genutzt)
const uint8_t BRIGHTNESS_LEVELS[4] = {10, 40, 80, 200};

// WiFi AP (Fallback-Hotspot, immer aktiv)
#define WIFI_SSID     "NixieClockCS"
#define WIFI_PASS     "nixie1234"
#define WIFI_HOSTNAME "nixieclockcs"   // mDNS + DHCP-Hostname → http://nixieclockcs.local

// NTP
#define NTP_SERVER  "pool.ntp.org"
#define NTP_TZ      "CET-1CEST,M3.5.0,M10.5.0/3"  // Mitteleuropäische Zeit

// Einstellmodus Timeout (ms)
#define EDIT_TIMEOUT_MS   15000

#define NIGHT_DIM_NEO_PCT     15   // NeoPixel-Helligkeit im Dimm-Modus in % der Normalhelligkeit

// HV-Dimmer (TLP627, LEDC-Hardware-PWM auf HV_SWITCH_PIN)
#define HV_PWM_FREQ_HZ        100  // Hz — bei 200 Hz dimmen die Pro-Röhre-TLP627 wegen ihrer Abschaltverzögerung kaum

// Datum-Anzeige Dauer nach Slot-Animation
#define DATE_SHOW_MS  5000

// ═══════════════════════════════════════════════════════════
//  OBJEKTE
// ═══════════════════════════════════════════════════════════

ThreeWire    rtcWire(RTC_IO_PIN, RTC_CLK_PIN, RTC_CE_PIN);
RtcDS1302<ThreeWire> Rtc(rtcWire);

Adafruit_NeoPixel strip(NEO_COUNT, NEO_PIN, NEO_GRB + NEO_KHZ800);

AsyncWebServer server(80);

Preferences prefs;

// ═══════════════════════════════════════════════════════════
//  GLOBALE VARIABLEN
// ═══════════════════════════════════════════════════════════

// Anzuzeigende Ziffern [0]=HZ [1]=HE [2]=MZ [3]=ME [4]=SZ [5]=SE
uint8_t displayDigits[6] = {0xFF, 0xFF, 0xFF, 0xFF, 0xFF, 0xFF};  // Sentinel: kein gültiger Ziffernwert, erzwingt harten Schreibvorgang beim ersten commitDigits()-Aufruf

// Helligkeit (Index in BRIGHTNESS_LEVELS)
uint8_t brightLevel = 3;

// NeoPixel Helligkeit (getrennt für Hintergrund- und Trennpunkt-LEDs)
uint8_t  neoBright   = 30;   // Pixel 0–5 (Hintergrund)
uint8_t  colonBright = 80;   // Pixel 6–9 (Trennpunkte)
uint8_t  neoHue      = 0;    // auto-inkrement in Animationen
uint8_t  neoSat      = 255;

// Animations-Modus
enum AnimMode { ANIM_RAINBOW, ANIM_STATIC, ANIM_PULSE, ANIM_COUNT };
AnimMode animMode = ANIM_RAINBOW;

enum SlotInterval { SLOT_OFF, SLOT_10S, SLOT_1MIN, SLOT_15MIN, SLOT_1HR };
SlotInterval slotInterval = SLOT_OFF;
uint8_t slotSpeedPct = 100;   // 20–100, NVS-Key "slotSpeed" (100 = aktuelles/unverändertes Tempo)

enum NightState { NIGHT_NORMAL, NIGHT_DIM, NIGHT_DARK };

// Nacht-Modus Konfiguration (aus NVS geladen)
NightState nightState       = NIGHT_NORMAL;
bool     nightTimeEnabled   = false;
uint8_t  nightStart         = 23;
uint8_t  nightEnd           = 7;
uint8_t  nightTimeMode      = 0;
bool     ldrEnabled         = false;
uint16_t ldrThreshold       = 512;
uint16_t ldrReading         = 4095;
uint32_t lastLdrRead        = 0;
uint8_t  hvDimPct           = 25;   // Röhren-Dimm-Helligkeit in % (2–60), NVS-Key "hvDimPct"
bool softFadeSecondEnabled  = false;   // NVS-Key "sfSecEn"
bool softFadeDateEnabled    = false;   // NVS-Key "sfDateEn"

// Einstellmodus
enum EditState { EDIT_NONE, EDIT_HOUR, EDIT_MIN, EDIT_SEC,
                 EDIT_DAY, EDIT_MONTH, EDIT_YEAR };
EditState editState = EDIT_NONE;
unsigned long editEnterTime = 0;

// Uhrzeit (lokal gecacht)
uint8_t  curHour = 0, curMin = 0, curSec = 0;

// Datum (lokal gecacht)
uint8_t  curDay   = 1;    // 1-basiert
uint8_t  curMonth = 1;    // 1-basiert
uint8_t  curYear  = 24;   // zweistellig: 0–99

// WiFi / NTP Status
bool wifiStaConnected = false;
bool ntpSynced        = false;
bool pendingRestart   = false;
unsigned long restartAt = 0;

// Letzter NeoPixel-Update
unsigned long lastNeoUpdate = 0;

// Slot-Machine Animation
bool slotActive = false;
unsigned long slotStartMs = 0;
uint8_t slotTarget[6] = {0};
uint8_t slotCurrent[6] = {0};
uint16_t slotRollIntervalMs   = 60;
uint16_t slotStopMs[6]        = {600, 780, 960, 1140, 1320, 1500};

// Datum-Anzeige nach Slot
bool     dateShowActive = false;
uint32_t dateShowStart  = 0;

// Röhrentest
bool     tubeTestActive    = false;
uint8_t  tubeTestDigit     = 0;      // 0–9, aktuell angezeigte Testziffer
uint32_t tubeTestStepStart = 0;
#define  TUBE_TEST_STEP_MS 2000

// Fade-In beim Start
bool startFadeIn = true;
uint8_t startFadeStep = 0;

// Nacht-Modus: letzter angewendeter Zustand (für Übergangserkennung)
static NightState  prevNightState  = NIGHT_NORMAL;

// ═══════════════════════════════════════════════════════════
//  IR-FERNBEDIENUNG
// ═══════════════════════════════════════════════════════════
enum IrAction {
  IR_LEARN_NONE           = -1,
  IR_ACTION_SET           = 0,
  IR_ACTION_UP            = 1,
  IR_ACTION_DOWN          = 2,
  IR_ACTION_BRIGHTNESS    = 3,
  IR_ACTION_ANIM_NEXT     = 4,
  IR_ACTION_SLOT          = 5,
  IR_ACTION_COLON_TOGGLE  = 6,
  IR_ACTION_DATE          = 7,
  IR_ACTION_COUNT         = 8
};

const char* IR_ACTION_KEYS[IR_ACTION_COUNT] = {
  "ir_SET", "ir_UP", "ir_DOWN", "ir_BRIGHTNESS",
  "ir_ANIM_NEXT", "ir_SLOT", "ir_COLTOGGLE", "ir_DATE"
};

const char* IR_ACTION_LABELS[IR_ACTION_COUNT] = {
  "SET", "UP", "DOWN", "BRIGHTNESS",
  "ANIM_NEXT", "SLOT", "COLON_TOGGLE", "DATUM"
};

IRrecv   irrecv(IR_RECV_PIN);
decode_results irResults;

uint64_t irCodes[IR_ACTION_COUNT] = {0};
IrAction irLearnTarget  = IR_LEARN_NONE;
unsigned long irLearnStartMs = 0;
#define IR_LEARN_TIMEOUT_MS 10000
portMUX_TYPE irMux = portMUX_INITIALIZER_UNLOCKED;

// Trennpunkte dauerhaft an (statt Sekundenblinken)
bool colonAlwaysOn = false;
// Trennpunkte statisch warmweiß (ignoriert Animationsfarbe)
bool colonStatic   = false;

// ═══════════════════════════════════════════════════════════
//  TASTER-STRUKTUR (muss vor auto-generierten Prototypen stehen)
// ═══════════════════════════════════════════════════════════
struct Button {
  uint8_t      pin;
  bool         lastState;
  bool         pressed;
  bool         held;
  bool         debounced;   // true sobald Entprellzeit nach Flanke abgelaufen
  unsigned long pressTime;
  unsigned long lastRepeat;
  uint16_t     debounceMs;
  uint16_t     repeatMs;
};

Button btnSet   = {BTN_SET,   HIGH, false, false, false, 0, 0, 30, 400};
Button btnUp    = {BTN_UP,    HIGH, false, false, false, 0, 0, 30, 200};
Button btnDown  = {BTN_DOWN,  HIGH, false, false, false, 0, 0, 30, 200};
Button btnLight = {BTN_LIGHT, HIGH, false, false, false, 0, 0, 30, 500};

// Forward-Deklarationen für Funktionen, die der Arduino-Präprozessor
// nicht automatisch erkennt (Raw-String-Literal in web_server.ino)
void nixieInit();
void setupWifiRadio();
void setupWifi();
void setupWebServer();
void updateNightMode();
void startTubeTest();
void updateTubeTest();
void stopTubeTest();
void hvDimmerSetDutyTube(uint8_t tube, uint8_t duty0to255);
void hvDimmerSoftStart();

// ═══════════════════════════════════════════════════════════
//  SETUP
// ═══════════════════════════════════════════════════════════
void setup() {
  Serial.begin(115200);
  delay(200);
  Serial.println("\n[NixieClock] Booting...");
  bootDiagInit();

  // --- Taster ---
  pinMode(BTN_SET,   INPUT_PULLUP);
  pinMode(BTN_UP,    INPUT_PULLUP);
  pinMode(BTN_DOWN,  INPUT_PULLUP);
  pinMode(BTN_LIGHT, INPUT_PULLUP);

  // --- NeoPixel ---
  strip.begin();
  strip.setBrightness(255);  // Skalierung erfolgt per Pixel in neo_animation
  strip.clear();
  strip.show();

  // --- HV-Dimmer (TLP627) ---
  hvDimmerInit();   // Anoden zunächst zu (Einschaltstrom entzerren)

  // --- Preferences laden ---
  prefs.begin("nixie", false);
  brightLevel = prefs.getUChar("bright",    3);
  neoBright   = prefs.getUChar("neoBright",   30);
  colonBright = prefs.getUChar("colonBright", 80);
  uint8_t savedAnim = prefs.getUChar("animMode", 0);
  animMode     = (savedAnim < (uint8_t)ANIM_COUNT) ? (AnimMode)savedAnim : ANIM_RAINBOW;
  uint8_t savedSlot = prefs.getUChar("slotIval", 0);
  slotInterval = (savedSlot <= (uint8_t)SLOT_1HR) ? (SlotInterval)savedSlot : SLOT_OFF;
  slotSpeedPct = (uint8_t)constrain((int)prefs.getUChar("slotSpeed", 100), 20, 100);

  for (int i = 0; i < IR_ACTION_COUNT; i++) {
    irCodes[i] = prefs.getULong64(IR_ACTION_KEYS[i], 0);
  }
  colonAlwaysOn    = prefs.getBool("colonOn",     false);
  colonStatic      = prefs.getBool("colonStatic", false);

  nightTimeEnabled = prefs.getBool("ntEn",      false);
  nightStart       = prefs.getUChar("ntFrom",   23);
  nightEnd         = prefs.getUChar("ntTo",     7);
  nightTimeMode    = prefs.getUChar("ntMode",   0);
  ldrEnabled       = prefs.getBool("ldrEn",     false);
  ldrThreshold     = prefs.getUShort("ldrThr",  512);
  hvDimPct         = (uint8_t)constrain((int)prefs.getUChar("hvDimPct", 25), 2, 60);
  softFadeSecondEnabled = prefs.getBool("sfSecEn",  false);
  softFadeDateEnabled   = prefs.getBool("sfDateEn", false);
  bootDiagStage(BOOT_STAGE_PREFS);

  // --- Nixie Direct Drive via MCP23017 ---
  nixieInit();    // Wire.begin() muss vor readRTC()/setDisplayTime() stehen
  bootDiagStage(BOOT_STAGE_MCP);

  // --- RTC ---
  Rtc.Begin();
  if (!Rtc.IsDateTimeValid()) {
    Serial.println("[RTC] Nicht initialisiert – setze Defaultzeit");
    RtcDateTime compiled = RtcDateTime(2024, 1, 1, 0, 0, 0);
    Rtc.SetDateTime(compiled);
  }
  Rtc.SetIsWriteProtected(false);
  Rtc.SetIsRunning(true);
  readRTC();
  setDisplayTime(curHour, curMin, curSec);   // Kathoden gesetzt, Anoden noch zu

  // --- Einschaltlasten zeitlich entzerren ---
  // 1. Funkmodul starten (HF-Kalibrierung = Stromspitze), solange die Röhren
  //    noch keinen Strom ziehen.
  setupWifiRadio();
  bootDiagStage(BOOT_STAGE_RADIO);
  // 2. Röhren nacheinander aufblenden.
  hvDimmerSoftStart();
  bootDiagStage(BOOT_STAGE_TUBES_ON);

  // --- WiFi (Heimnetz) + Web-Server ---
  setupWifi();
  bootDiagStage(BOOT_STAGE_WIFI);
  setupWebServer();
  bootDiagStage(BOOT_STAGE_WEB);

  // --- IR-Empfänger ---
  irrecv.enableIRIn();
  Serial.printf("[IR] Empfänger gestartet auf Pin %d\n", IR_RECV_PIN);

  // --- Fade-In Vorbereitung ---
  startFadeIn   = true;
  startFadeStep = 0;

  Serial.println("[NixieClock] Bereit.");
  bootDiagStage(BOOT_STAGE_READY);
  bootDiagPrint();   // nochmals, falls der USB-CDC-Monitor die erste Ausgabe verpasst hat
}

// ═══════════════════════════════════════════════════════════
//  LOOP
// ═══════════════════════════════════════════════════════════

uint8_t  lastSec = 255;
uint32_t lastRtcRead = 0;
uint32_t lastFadeMs  = 0;

void loop() {
  bootDiagLoop();

  // --- Start-Fade-In ---
  if (startFadeIn) {
    if (millis() - lastFadeMs >= FADE_INTERVAL_MS) {
      lastFadeMs = millis();
      startFadeStep++;
      if (startFadeStep >= FADE_STEPS) {
        startFadeIn = false;
        // Strip-interne Skalierung bleibt deaktiviert (255) – Skalierung
        // erfolgt ausschließlich per Pixel in neo_animation via scaleColor().
        strip.setBrightness(255);
      }
    }
    return;
  }

  // --- Taster einlesen ---
  updateButton(btnSet);
  updateButton(btnUp);
  updateButton(btnDown);
  updateButton(btnLight);

  // --- IR ---
  handleIR();

  // --- Helligkeitssteuerung ---
  handleBrightness();

  // --- Einstellmodus (pausiert während Röhrentest) ---
  if (!tubeTestActive) handleEditMode();

  // --- Nacht-Modus ---
  updateNightMode();

  // --- Nacht-Modus: Röhren-Helligkeit per HV-Dimmer steuern (pausiert während Röhrentest) ---
  if (nightState != prevNightState && !tubeTestActive) {
    prevNightState = nightState;
    cancelDigitFade();   // laufenden Ziffern-Fade nicht mit Duty-Wechsel kollidieren lassen
    switch (nightState) {
      case NIGHT_DARK:   hvDimmerSetDutyAll(0);                        break;
      case NIGHT_DIM:    hvDimmerSetDutyAll(hvDimPct * 255 / 100);     break;
      case NIGHT_NORMAL: hvDimmerSetDutyAll(255);                      break;
    }
  }
  updateDigitFade();
  updateTubeTest();

  // --- RTC alle 500ms lesen (außerhalb Einstellmodus) ---
  if (editState == EDIT_NONE && millis() - lastRtcRead >= 500) {
    lastRtcRead = millis();
    readRTC();

    if (curSec != lastSec) {
      lastSec = curSec;

      bool triggerSlot = false;
      switch (slotInterval) {
        case SLOT_10S:   triggerSlot = (curSec % 10 == 0); break;
        case SLOT_1MIN:  triggerSlot = (curSec == 0); break;
        case SLOT_15MIN: triggerSlot = (curSec == 0 && curMin % 15 == 0); break;
        case SLOT_1HR:   triggerSlot = (curSec == 0 && curMin == 0); break;
        default: break;
      }
      if (!slotActive && !dateShowActive && !tubeTestActive) {
        if (triggerSlot) startSlotAnimation(curHour, curMin, curSec);
        else             setDisplayTimeSoft(curHour, curMin, curSec, softFadeSecondEnabled ? 800 : 0);
      }
    }
  }

  // --- Slot-Animation ---
  bool wasSlotActive = slotActive;
  if (slotActive) updateSlotAnimation();
  if (wasSlotActive && !slotActive) {
    dateShowActive = true;
    dateShowStart  = millis();
    setDisplayDateSoft(softFadeDateEnabled ? 800 : 0);
  }

  // Datum-Anzeige beenden
  if (dateShowActive && millis() - dateShowStart >= DATE_SHOW_MS) {
    dateShowActive = false;
    setDisplayTimeSoft(curHour, curMin, curSec, softFadeDateEnabled ? 800 : 0);
  }

  // --- NeoPixel ---
  updateNeoPixel();

  // --- NTP → RTC-Sync (einmalig nach Verbindung) ---
  if (wifiStaConnected && !ntpSynced) {
    struct tm ti;
    if (getLocalTime(&ti, 0)) {
      ntpSynced = true;
      RtcDateTime ntpTime(ti.tm_year + 1900, ti.tm_mon + 1, ti.tm_mday,
                          ti.tm_hour, ti.tm_min, ti.tm_sec);
      Rtc.SetDateTime(ntpTime);
      Serial.println("[NTP] RTC synchronisiert.");
    }
  }

  // --- Neustart nach WiFi-Änderung ---
  if (pendingRestart && millis() >= restartAt) {
    ESP.restart();
  }

  // Kurze Pause um CPU zu entlasten
  delay(1);
}

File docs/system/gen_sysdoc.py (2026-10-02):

#!/usr/bin/env python3
"""Generiert NixieClockUltra-Systemdokumentation.odt"""

import zipfile, base64, os, struct, zlib
from pathlib import Path

WD   = Path("/home/andreas/Dokumente/_Develop/Arduino/NixieClockUltra")
IMGS = WD / "docs/system/assets"
OUT  = WD / "docs/system/NixieClockUltra-Systemdokumentation.odt"

# Kollektion aller verwendeten Spaltenbreiten (für Auto-Style-Generierung)
_used_col_widths: set = set()

MAX_IMG_W_CM = 15.5   # maximale Bildbreite auf der Seite

# Mapping logischer Bildname → tatsächlicher Dateipfad; wird in create_odt() gefüllt
_img_paths: dict = {}

def _png_size(path: Path):
    """Liest Breite und Höhe eines PNG aus dem IHDR-Chunk (ohne Pillow)."""
    with open(path, "rb") as f:
        f.read(8)           # PNG-Signatur
        f.read(4)           # IHDR-Länge
        f.read(4)           # "IHDR"
        w = struct.unpack(">I", f.read(4))[0]
        h = struct.unpack(">I", f.read(4))[0]
    return w, h

# ─── XML-Hilfsfunktionen ────────────────────────────────────────────────────

def esc(s):
    return str(s).replace("&","&amp;").replace("<","&lt;").replace(">","&gt;")

def h1(text, page_break=True):
    pb = '<text:p text:style-name="PageBreak"/>' if page_break else ""
    return f'{pb}<text:h text:style-name="Heading_1" text:outline-level="1">{esc(text)}</text:h>\n'

def h2(text):
    return f'<text:h text:style-name="Heading_2" text:outline-level="2">{esc(text)}</text:h>\n'

def h3(text):
    return f'<text:h text:style-name="Heading_3" text:outline-level="3">{esc(text)}</text:h>\n'

def p(text="", style="Text_Body"):
    return f'<text:p text:style-name="{style}">{esc(text)}</text:p>\n'

def br():
    return '<text:p text:style-name="Text_Body"/>\n'

def caption(text):
    return f'<text:p text:style-name="Caption"><text:span text:style-name="Italic">{esc(text)}</text:span></text:p>\n'

def code_block(*lines):
    return "".join(f'<text:p text:style-name="Code">{esc(l)}</text:p>\n' for l in lines)

def note(text):
    return f'<text:p text:style-name="Note">&#x26A0; {esc(text)}</text:p>\n'

def img(name, cap):
    """Bettet ein PNG ein. Breite = MAX_IMG_W_CM, Höhe aus echtem Seitenverhältnis."""
    path = _img_paths.get(f"{name}.png", IMGS / f"{name}.png")
    pw, ph = _png_size(path)
    w_cm = MAX_IMG_W_CM
    h_cm = round(w_cm * ph / pw, 2)
    return (
        f'<text:p text:style-name="Text_Body">'
        f'<draw:frame draw:name="{name}" draw:style-name="Graphics" '
        f'svg:width="{w_cm}cm" svg:height="{h_cm}cm" '
        f'text:anchor-type="paragraph" draw:z-index="0">'
        f'<draw:image xlink:href="Pictures/{name}.png" '
        f'xlink:type="simple" xlink:show="embed" xlink:actuate="onLoad"/>'
        f'</draw:frame></text:p>\n'
        + caption(cap)
        + br()
    )

# ─── Tabellen ────────────────────────────────────────────────────────────────

def table(headers, rows, col_widths=None):
    global _used_col_widths
    n = len(headers)
    if col_widths is None:
        col_widths = [16.0 / n] * n
    # Spaltenbreiten merken für Auto-Style-Generierung
    for w in col_widths:
        _used_col_widths.add(round(w, 2))
    out = '<table:table table:style-name="TableStyle">\n'
    for w in col_widths:
        sn = f"Col{str(round(w,2)).replace('.','p')}"
        out += f'<table:table-column table:style-name="{sn}"/>\n'
    # header row
    out += '<table:table-row>\n'
    for h in headers:
        out += (f'<table:table-cell table:style-name="TH">'
                f'<text:p text:style-name="TableH">{esc(h)}</text:p>'
                f'</table:table-cell>\n')
    out += '</table:table-row>\n'
    # data rows
    for i, row in enumerate(rows):
        style = "TD_Alt" if i % 2 else "TD"
        out += '<table:table-row>\n'
        for cell in row:
            out += (f'<table:table-cell table:style-name="{style}">'
                    f'<text:p text:style-name="TableP">{esc(cell)}</text:p>'
                    f'</table:table-cell>\n')
        out += '</table:table-row>\n'
    out += '</table:table>\n'
    return out + br()

# ─── Styles XML ─────────────────────────────────────────────────────────────

STYLES_XML = """\
<?xml version="1.0" encoding="UTF-8"?>
<office:document-styles
  xmlns:office="urn:oasis:names:tc:opendocument:xmlns:office:1.0"
  xmlns:style="urn:oasis:names:tc:opendocument:xmlns:style:1.0"
  xmlns:text="urn:oasis:names:tc:opendocument:xmlns:text:1.0"
  xmlns:fo="urn:oasis:names:tc:opendocument:xmlns:xsl-fo-compatible:1.0"
  xmlns:svg="urn:oasis:names:tc:opendocument:xmlns:svg-compatible:1.0"
  xmlns:draw="urn:oasis:names:tc:opendocument:xmlns:drawing:1.0"
  xmlns:table="urn:oasis:names:tc:opendocument:xmlns:table:1.0"
  office:version="1.3">
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

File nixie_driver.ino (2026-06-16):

// ═══════════════════════════════════════════════════════════
//  NIXIE DIRECT DRIVE – MCP23017 via I2C
//  4× MCP23017 an I2C-Bus (SDA=GPIO8, SCL=GPIO9)
//  Adressen: 0x20, 0x21, 0x22, 0x23
// ═══════════════════════════════════════════════════════════

#include <Wire.h>
#include <freertos/semphr.h>

#define MCP_BASE_ADDR  0x20
#define MCP_IODIRA     0x00
#define MCP_IODIRB     0x01
#define MCP_OLATA      0x14

static SemaphoreHandle_t nixieMutex = nullptr;

// Shadow-Register: aktueller Ausgangszustand der 4 MCPs
// Bit 0–7 = GPA0–7, Bit 8–15 = GPB0–7
static uint16_t mcpState[4] = {0, 0, 0, 0};

// Zuordnung (tube, digit_value) → MCP-Index und Bit (0–15)
struct DigitPin { uint8_t mcp; uint8_t bit; };

static const DigitPin digitPin[6][10] = {
  // Index: [tube][digit_value]  digit_value 0=Ziffer0, 1=Ziffer1, ..., 9=Ziffer9

  // Tube 0: Stundenzehner (HZ) – MCP 0x20, Bits 0–9
  { {0, 9}, {0, 0}, {0, 1}, {0, 2}, {0, 3}, {0, 4}, {0, 5}, {0, 6}, {0, 7}, {0, 8} },

  // Tube 1: Stundeneiner  (HE) – MCP 0x20 Bits 10–15, MCP 0x21 Bits 0–3
  { {1, 3}, {0,10}, {0,11}, {0,12}, {0,13}, {0,14}, {0,15}, {1, 0}, {1, 1}, {1, 2} },

  // Tube 2: Minutenzehner (MZ) – MCP 0x21, Bits 4–13
  { {1,13}, {1, 4}, {1, 5}, {1, 6}, {1, 7}, {1, 8}, {1, 9}, {1,10}, {1,11}, {1,12} },

  // Tube 3: Minuteneiner  (ME) – MCP 0x22, Bits 0–9
  { {2, 9}, {2, 0}, {2, 1}, {2, 2}, {2, 3}, {2, 4}, {2, 5}, {2, 6}, {2, 7}, {2, 8} },

  // Tube 4: Sekundenzehner(SZ) – MCP 0x22 Bits 10–15, MCP 0x23 Bits 0–3
  { {3, 3}, {2,10}, {2,11}, {2,12}, {2,13}, {2,14}, {2,15}, {3, 0}, {3, 1}, {3, 2} },

  // Tube 5: Sekundeneiner (SE) – MCP 0x23, Bits 4–13
  { {3,13}, {3, 4}, {3, 5}, {3, 6}, {3, 7}, {3, 8}, {3, 9}, {3,10}, {3,11}, {3,12} },
};

static void mcpWriteAB(uint8_t addr, uint16_t value) {
  Wire.beginTransmission(addr);
  Wire.write(MCP_OLATA);
  Wire.write((uint8_t)(value & 0xFF));         // GPA (Low-Byte)
  Wire.write((uint8_t)((value >> 8) & 0xFF));  // GPB (High-Byte)
  Wire.endTransmission();
}

void nixieInit() {
  nixieMutex = xSemaphoreCreateMutex();
  Wire.begin(I2C_SDA, I2C_SCL);
  for (uint8_t i = 0; i < 4; i++) {
    uint8_t addr = MCP_BASE_ADDR + i;
    Wire.beginTransmission(addr);
    Wire.write(MCP_IODIRA);
    Wire.write(0x00);  // GPA: alle Pins als Output
    Wire.endTransmission();
    Wire.beginTransmission(addr);
    Wire.write(MCP_IODIRB);
    Wire.write(0x00);  // GPB: alle Pins als Output
    Wire.endTransmission();
    mcpState[i] = 0;
    mcpWriteAB(addr, 0x0000);
  }
  Serial.println("[Nixie] MCP23017 initialisiert.");
}

// digits[6]: Werte 0–9 = Ziffer anzeigen, 10 = Röhre blank
void nixieWrite(uint8_t digits[6]) {
  if (!nixieMutex || xSemaphoreTake(nixieMutex, pdMS_TO_TICKS(10)) != pdTRUE) return;
  uint16_t newState[4] = {0, 0, 0, 0};
  for (uint8_t tube = 0; tube < 6; tube++) {
    uint8_t d = digits[tube];
    if (d <= 9) {
      const DigitPin &dp = digitPin[tube][d];
      newState[dp.mcp] |= (1u << dp.bit);
    }
  }
  for (uint8_t i = 0; i < 4; i++) {
    if (newState[i] != mcpState[i]) {
      mcpWriteAB(MCP_BASE_ADDR + i, newState[i]);
      mcpState[i] = newState[i];
    }
  }
  xSemaphoreGive(nixieMutex);
}

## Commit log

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2026-04-22 feat: IR remote control with web-based learning mode and power-save toggle
    - VS1838 IR receiver on pin 48 via IRremoteESP8266
    - 7 learnable functions: SET/UP/DOWN/BRIGHTNESS/ANIM_NEXT/SLOT/POWER_SAVE_TOGGLE
    - IR codes (uint64_t) persisted in NVS (Preferences)
    - strip.show() wrapped with irrecv.pause()/resume() to prevent timing conflicts
    - portMUX critical sections protect irCodes[] and irLearnTarget across WiFi/loop tasks
    - Power-save can be permanently disabled via IR or web toggle (psEnabled in NVS)
    - New web card with per-function learn/clear UI and 500ms polling during learn mode
    - XSS-safe DOM construction for IR code display (textContent instead of innerHTML)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
    [NixieClockUltra.ino]
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2026-04-22 docs: add modularization design spec
    Spec für die Aufteilung der monolithischen NixieClockUltra.ino in 8
    thematisch abgegrenzte .ino-Dateien (reines Refactoring, kein inhaltlicher
    Code-Change).
2026-04-22 refactor: extract display + slot animation into display.ino
    Move setDisplayTime(), startSlotAnimation(), and updateSlotAnimation()
    functions from main NixieClockUltra.ino into dedicated display.ino file.
    Call sites remain in main file unchanged.
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2026-04-23 fix: add forward declarations for IRAM_ATTR and web_server functions
    Arduino IDE's preprocessor fails to auto-generate prototypes for:
    - onMuxTimer (IRAM_ATTR attribute confuses the scanner)
    - setupWifi / setupWebServer (raw string literal in web_server.ino
    causes the scanner to lose track of function definitions after it)
    [NixieClockUltra.ino]
2026-05-03 fix: ISR-Refactor, Kathoden-Mapping, NeoPixel RGB-Swap
    - mux_timer: ISR auf Tick-Zähler + auto-reload umgestellt (kein timerAlarm()
    im ISR mehr → IRAM_ATTR-sicher); Blank-Phase 5 Ticks vor Röhrenwechsel
    - NixieClockUltra: CATHODE_PIN-Reihenfolge korrigiert (IO17=1 … IO47=0),
    DRAM_ATTR auf CATHODE_PIN + ANODE_PIN, Timer-Start nach WiFi
    - neo_animation: rgbSwap() für THT WS2812 Pixel 6–9 (RGB statt GRB)
    - MUX_DIGIT_US 1800→2800, neoBright 80→30
    [NixieClockUltra.ino, display.ino, neo_animation.ino]
2026-05-03 refactor: PowerSave-Funktion vollständig entfernt
    Entfernt: powerSaveEnabled, powerSaveActive, lastInteractionMs,
    POWER_SAVE_TIMEOUT_S, handlePowerSave(), IR_ACTION_POWER_SAVE_TOGGLE,
    /api/powersave Endpoint, Web-UI Toggle und alle zugehörigen NVS-Zugriffe.
    IR_ACTION_COUNT von 7 auf 6 reduziert.
2026-05-03 feat: colonAlwaysOn per Taster (langer Druck) und IR steuerbar
    - buttons: langer Druck auf BTN_LIGHT togglet colonAlwaysOn (einmalig
    per Druck via colonToggleDone-Flag, kurzer Druck bleibt Helligkeit)
    - ir_remote: neuer Case IR_ACTION_COLON_TOGGLE
    - NixieClockUltra: IR_ACTION_COLON_TOGGLE=6, IR_ACTION_COUNT=7,
    NVS-Key "ir_COLTOGGLE", Label "COLON_TOGGLE"
    - web_server: COLON_TOGGLE in IR-Tabelle anlernbar
2026-05-03 docs: Bedienungsanleitung aktualisiert
    - LIGHT: langer Druck für Trennpunkt-Toggle ergänzt
    - IR: POWER_SAVE_TOGGLE → COLON_TOGGLE ersetzt
    - Web-UI: Power-Save entfernt, Trennpunkte-Toggle eingetragen
    - Abschnitt Power-Save entfernt
    - Persistenz-Liste aktualisiert
2026-05-03 fix: Label-Korrektur Helligkeit – NeoPixel statt Nixie
    Die 4-Stufen-Auswahl steuert neoBright (NeoPixel), nicht die Nixie-Röhren.
    Betrifft Web-UI-Label und Bedienungsanleitung.
2026-05-03 feat: getrennte Helligkeit für Hintergrund- und Trennpunkt-LEDs
    - neo_animation: strip.setBrightness() entfernt, stattdessen
    scaleColor() pro Pixel-Gruppe (neoBright für Pixel 0-5,
    colonBright für Pixel 6-9)
    - NixieClockUltra: colonBright Variable (default 15), NVS-Key
    "colonBright", strip.setBrightness(255) in setup()
    - web_server: Hue-Slider entfernt (/api/neohue), neuer
    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
2026-05-03 fix: Helligkeits-Slider-Bereiche korrigiert
    NeoPixel-Helligkeit (Hintergrund) max 100→255,
    Trennpunkt-Helligkeit max 60→100, API-Constraints angepasst.
2026-05-03 feat: Trennpunkte statisch-Modus (colonStatic)
    Neuer bool colonStatic (NVS-Key "colonStatic", default false):
    - neo_animation: nach dem Switch-Block werden Colon-Pixel bei
    colonStatic=true mit Warmweiß überschrieben, unabhängig von
    Animationsfarbe und colonAlwaysOn
    - Web-UI: Toggle "Trennpunkte statisch (Warmweiß)"
    - API: POST /api/colonstatic {enabled}, GET /api/status liefert colonStatic
2026-05-03 fix: Anti-Ghost – Anode vor Kathode (dV/dt-Transiente)
    Ursache: dV/dt-Sprung beim Anode-Einschalten (0V→170V) koppelt
    kapazitiv auf alle anderen Anodenleitungen. War Cathode[0] in
    diesem Moment HIGH, zündeten alle Röhren kurz mit "0".
    Fix: Anode tick 0 (alle Kathoden noch LOW → harmlose Transiente),
    Kathode erst tick 1 (Spannung stabil). Blank weiterhin bei tick 7.
    Timing (MUX_DIGIT_US=4400, MUX_BLANK_US=400, 12 Ticks):
    Anode-Vorlauf: 1 × 400 µs = 0,4 ms
    Display: 6 × 400 µs = 2,4 ms (35 Hz Refresh)
    Blank: 5 × 400 µs = 2,0 ms
    [NixieClockUltra.ino]
2026-05-03 Revert "fix: Anti-Ghost – Anode vor Kathode (dV/dt-Transiente)"
    This reverts commit ad6eb0b5d1befa4e79aba8ecf4cbb915cdd3c8fb.
    [NixieClockUltra.ino]
2026-05-03 fix: extend blank phase to reduce Nixie ghosting
    Replaces hardcoded blank-tick count (5) with MUX_BLANK_TICKS define (8),
    extending the blank phase from 1.0 ms to 1.6 ms per tube while keeping
    refresh rate at ~55 Hz. Digit phase reduces from 2.0 ms to 1.4 ms.
    MUX_BLANK_TICKS can be tuned further (up to ~11) if ghosting persists.
    [NixieClockUltra.ino]
2026-05-09 fix: nixieInit vor setDisplayTime; I2C-Mutex fuer nixieWrite
    [NixieClockUltra.ino, nixie_driver.ino]
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2026-06-15 fix: CSS-Korrekturen – print min-height, Custom Properties bereinigt
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2026-06-15 docs: Systemdokumentation als ODT mit eingebetteten Schaltplänen
    16-seitige LibreOffice-Writer-Systemdokumentation generiert mit
    Python-Zipfile-basiertem ODT-Generator. Enthält alle 4 KiCAD-Grafiken
    (Schaltpläne + PCB-Layouts beider Platinen) als eingebettete PNGs,
    formatierte Tabellen mit blauem Header, Code-Blöcke, Hochspannungswarnung
    sowie vollständige Hardware- und Firmware-Architektur-Dokumentation.
2026-06-16 docs: PCB-Unterseiten und NeoPixel-Korrektur in Systemdokumentation
    - gen_sysdoc.py: PCB-Layout-Sektion zeigt jetzt Ober- und Unterseite
    (logic_pcb-1/2.png, nixie_pcb-1/2.png), Unterseiten optional per
    Dateiexistenz-Prüfung
    - NeoPixel-Einleitungstext korrigiert: 6 SMD-LEDs Hintergrund,
    4 THT-LEDs Trennpunkte (war: "Zehn LEDs liefern die Hintergrundbeleuchtung")
    - Komponenten-Tabelle: D1–D6 (6×SMD GRB) + D7–D10 (4×THT RGB)
    statt falsche D1/D2–D6/D7–D9-Aufteilung
    - NixieClockUltra.ino: #define I2C_SDA/I2C_SCL ergänzt
    - nixie_driver.ino: Wire.begin() nutzt jetzt die neuen Defines
    - Assets: logic_pcb-2.png, nixie_pcb-2.png hinzugefügt
    - ODT neu generiert (551 KB)
    Co-Authore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
    [NixieClockUltra.ino, gen_sysdoc.py, nixie_driver.ino]
2026-06-17 docs: Design-Spec Slot-Intervall-Redesign und Animationstrennung
2026-06-17 docs: Implementierungsplan Slot-Intervall-Redesign
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2026-06-17 fix: bounds check slotInterval NVS load, colonBright global default 80
    [NixieClockUltra.ino]
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2026-06-17 fix: colonStatic skipped during slot animation, colonBright HTML default 80
    [neo_animation.ino]
2026-06-17 fix: irrecv.pause/resume um strip.show() entfernt — ESP32-S3 RMT braucht das nicht, resets blockierten IR-Empfang
    [neo_animation.ino]
2026-06-17 fix: colonStatic respektiert colonAlwaysOn – Blinken unabh. von Farbmodus
    [neo_animation.ino]
2026-06-17 fix: Taster-Entprellung – debounced-Flag verhindert dass pressed nie true wird
    [NixieClockUltra.ino, buttons.ino]
2026-06-17 fix: Taster-Pins korrigiert – UP=IO12, DOWN=IO11, LIGHT=IO10
    [NixieClockUltra.ino]
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2026-06-21 feat: night_mode.ino – NightState, LDR-Abtastung, updateNightMode()
    - night_mode.ino: NightState-Variable, LDR-Sampling (GPIO6, 4x Mittelwert),
    Zeitbereichs- und LDR-Logik in updateNightMode()
    - NixieClockUltra.ino: NightState-Enum, Forward-Deklaration, NVS-Ladeblock
    (ntEn/ntFrom/ntTo/ntMode/ldrEn/ldrThr), updateNightMode()-Aufruf in loop()
    - web_server.ino: nightState-Platzhalter durch (int)nightState ersetzt
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2026-06-21 fix: mDNS-Hostname-Kommentar nixieclock.local → nixieclockcs.local
    [NixieClockUltra.ino]
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2026-06-21 fix: Night-Mode-Globals nach NixieClockUltra.ino – Arduino-Kompilierungsreihenfolge
    [NixieClockUltra.ino, night_mode.ino]
2026-06-21 feat: Datum-IR-Taste, Datumsanzeige NeoPixel, LDR-Refresh, Web-UI-Fixes, Anleitung v2.1
    - IR_ACTION_DATE (DATUM): 5s Datumsanzeige per Fernbedienung auslösbar
    - neo_animation: Datumsanzeige zeigt nur untere Trennpunkte (Pixel 7+9)
    - display.ino: nixieWriteSafe() verhindert Aufblitzer in PWM-Off-Phase
    - night_mode: LDR wird immer gelesen (unabhängig von ldrEnabled)
    - web_server: IR_ACTIONS/IR_LABELS um DATUM erweitert, innerHTML fix für Sonderzeichen
    - web_server: Labels LDR-Sensor→Lichtsensor aktiv, LDR-Rohwert→Umgebungshelligkeit
    - Bedienungsanleitung v2.1: Kapitel X, Nacht-Modus-Kapitel VIII, Datum-Einstellung,
    IR DATUM-Funktion, korrekte Taster-Pins, mDNS, WLAN-Scan-Entfernung do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
    [NixieClockUltra.ino, display.ino, ir_remote.ino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]
2026-06-21 docs: Systemdokumentation auf aktuellen Firmware-Stand gebracht
    firmware.md: Pin-Korrekturen (BTN_UP=12, DOWN=11, LIGHT=10, LDR_PIN=6),
    night_mode.ino-Modul ergänzt, alle Enums aktualisiert (EditState um
    EDIT_DAY/MONTH/YEAR, IrAction um IR_ACTION_DATE, NightState-Enum neu,
    AnimMode bereinigt), Globals-Tabelle (Datum- und Nacht-Modus-Variablen,
    nixiePwmOn), Web-API-Tabelle (/api/nightmode, /api/slotinterval, 8 IR-
    Einträge), NVS-Tabelle (Nacht-Modus-Schlüssel, ir_DATE), nixieWriteSafe()
    und Datumsanzeige-Logik beschrieben.
    hardware.md: GPIO-Tabelle korrigiert (GPIO10/11/12 statt 14/15/16), GPIO6
    LDR-ADC ergänzt, J5 als bestückt gekennzeichnet.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
2026-07-07 fix: NeoPixel-Helligkeit reagiert nicht mehr auf Web-UI-Änderungen
    strip.setBrightness() im Boot-Fade-In friert die interne NeoPixel-
    Skalierung dauerhaft auf den Boot-Wert von neoBright ein, obwohl seit
    der Umstellung auf Pro-Pixel-Skalierung (scaleColor()) in setup()
    bereits strip.setBrightness(255) gesetzt wird, um genau das zu
    verhindern. Dadurch deckelte der eingefrorene Wert jede spätere
    Helligkeitsänderung, sobald sie über den beim letzten Boot
    gespeicherten Wert hinausging – reproduzierbar über den Web-UI-Slider,
    aber kaum über die auf 10–80 begrenzten Taster-/IR-Stufen.
    Fade-In setzt jetzt keine Strip-Skalierung mehr während des Ablaufs
    und stellt sie am Ende explizit au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
    [NixieClockUltra.ino]
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2026-07-07 fix(docs): TLP627 schaltet Anodenspannung direkt, kein zusätzlicher HV-Schalter nötig
    Laut Datenblatt (Recommended Operating Conditions: Supply Voltage max.
    200V) ist der TLP627-Photodarlington-Ausgang für die ~170V-Anoden-
    spannung spannungsfest genug – die ursprüngliche Annahme einer VCEO
    von nur ~55-70V war falsch und stammte nicht aus dem Datenblatt.
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2026-07-07 fix(docs): Plan-Sequenzierung – NIGHT_DIM-Defines bleiben bis Task 2 bestehen
    Task-1-Reviewer fand: Step 2 des ursprünglichen Plans entfernte
    NIGHT_DIM_DUTY_PCT/NIGHT_DIM_PWM_PERIOD, obwohl Task 1 laut Scope den
    loop()-Block, der sie noch nutzt, explizit nicht anfassen sollte –
    macht den Zwischen-Commit von Task 1 nicht kompilierbar. Verschiebt die
    Entfernung dieser Defines nach Task 2, wo auch ihre letzte Verwendung
    entfernt wird.
2026-07-07 fix: NIGHT_DIM_DUTY_PCT/NIGHT_DIM_PWM_PERIOD erst in Task 2 entfernen (kompilierbarer Zwischenstand)
    [NixieClockUltra.ino]
2026-07-07 fix(docs): display.ino::nixieWriteSafe() in Task 2 ergänzt
    Task-2-Implementer fand: display.ino referenziert nixiePwmOn, das
    dieser Task entfernt – Kompilierfehler, da Arduino alle .ino-Dateien
    zu einer Übersetzungseinheit verkettet. Plan hatte display.ino nicht
    in Task 2s Files-Liste. Ergänzt um Step 6 (nixieWriteSafe()
    vereinfachen, da die Anodenspannung jetzt die Dimmung/Dunkelheit
    steuert) und projektweiten Grep-Check in Step 7.
2026-07-07 fix: nixieWriteSafe() vereinfacht — Anodenspannung steuert Dimmung/Dunkelheit, kein Kathoden-Gate mehr nötig
    [display.ino]
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2026-07-10 fix: NeoPixel-Helligkeitsstufen für Taster/IR angepasst (10/40/80/200)
    Vorherige Stufen (10/30/50/80) deckten den nutzbaren Helligkeitsbereich
    nicht ausreichend ab.
    [NixieClockUltra.ino]
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2026-07-10 docs: Systemdokumentation auf HV-Anodendimmung + Rev-2.1-Hardware gebracht
    - hardware.md: TLP627 als Komponente ergänzt (handverdrahtet, noch ohne
    feste Schaltplan-Referenz), GPIO7 (HV_SWITCH) in Pin-Tabelle, Hinweis
    dass Anodenspannung jetzt dimmbar ist statt permanent an
    - firmware.md: hv_dimmer.ino in Modulübersicht + Setup-Ablauf ergänzt,
    BRIGHTNESS_LEVELS und hvDimPct-Range korrigiert, veralteten
    Software-PWM/Blitzschutz-Abschnitt durch tatsächliche HV-Dimmer-Logik
    ersetzt, Web-API-/NVS-Tabellen korrigiert (api/bright entfernt,
    hvDimPct in api/nightmode ergänzt)
    - gen_sysdoc.py: dieselben Korrekturen für den ODT-Export gespiegelt
    - ODT und PDF neu generiert (schließt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
    [gen_sysdoc.py]
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2026-07-11 fix: displayDigits-Sentinel gegen dunkles Display bei RTC-Kaltstart
    Bei ungültiger RTC (leere Batterie) fällt setup() auf 2024-01-01 00:00:00
    zurück, wodurch der erste commitDigits()-Aufruf Zielziffern {0,0,0,0,0,0}
    liefert - byte-identisch zum alten displayDigits-Initialwert. Der memcmp-
    Changed-Check griff dadurch fälschlich, nixieWrite() wurde beim Boot nie
    aufgerufen und die Röhren blieben bis zum nächsten Sekundentakt dunkel.
    displayDigits wird jetzt mit einem 0xFF-Sentinel initialisiert, der nie
    ein gültiger Ziffernwert (0-9 bzw. 10=blank) sein kann, sodass der erste
    commitDigits()-Aufruf immer changed=true erkennt und hart schreibt.
    Zusätzlich: Kommentar in commitDigits() er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
    [NixieClockUltra.ino, display.ino]
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2026-07-11 fix: cancelDigitFade() vor Slot-Animation-Start und Edit-Modus-Eintritt
    Verhindert theoretische Race zwischen laufendem Digit-Fade und neuer
    Display-Aktivität (Slot-Machine-Start bzw. Eintritt in den Einstellmodus).
    Aktuell praktisch nicht erreichbar (Fades ~100-200ms, Trigger liegen
    sekundenweit auseinander), aber günstige Absicherung gegen künftige
    Timing-Änderungen. Aus Code-Review dieses Branches.
    [buttons.ino, display.ino]
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2026-07-12 docs: Doku auf weichen Ziffernwechsel + Slot-Geschwindigkeit aktualisiert
    Bedienungsanleitung, Systemdokumentation (Software-Teil), Marketing-Text
    und Website inkl. Entwicklungshistorie (Phase 9) auf den gemergten
    Branch feature/soft-digit-transitions gebracht. Dabei auch einen
    veralteten Verweis auf das entfernte nixieWriteSafe() in der
    Systemdokumentation korrigiert.
    [gen_sysdoc.py]
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2026-07-13 docs: Gehäuse- und Leiterplatten-Quelldateien ergänzen
    STL/Lasercut-SVGs fürs Gehäuse sowie KiCad-Projekte und Gerber-
    Fertigungsdaten für IN12-Board und Logic-Board V2.1 hinzugefügt.
    [NixieClockUtra.stl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]
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2026-07-16 feat: Logic-Board Rev 2.2 – Leiterplatten-Quelldateien und Website aktualisiert
    Überarbeitete KiCad-Quelldateien und Gerber-Daten für das Logic Board
    (Rev 2.1 → 2.2) ersetzt. Website-Downloads-ZIP neu gepackt und
    Versionsangaben auf Features- und Aufbau-Seite (DE/EN) angepasst.
    [nixieclocklogic_V2-1.kicad_pcb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]
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2026-07-19 fix: Guard night-mode duty-cycle update against tube test
    Prevent night-mode state transitions from overriding the forced
    full-brightness duty cycle during tube test diagnostics. The test's
    own startTubeTest()/stopTubeTest() now retain control for the full ~20s.
    [NixieClockUltra.ino]
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2026-07-25 fix: Ziffernwechsel-Duty-Underflow, hängende Röhren nach cancelDigitFade, offener HV-Schalter im Pro-Röhre-Modus
    [digit_fade.ino, hv_dimmer.ino]
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2026-07-26 docs: Geschichte-Timeline um Phase 10 (Pro-Röhre-HV-Dimmer) ergänzt
    Features- und Aufbau-Seite waren bereits aktualisiert, die
    Entwicklungs-Timeline endete aber noch bei Phase 9. Intro-Zähler
    von acht auf zehn Phasen korrigiert (war zuvor bereits falsch,
    da schon 9 Phasen existierten).
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2026-07-31 Leiterplatten-Revision aktualisiert, Systemdoku/Werbetext neu generiert
    IN12-Board-Quelldateien auf einheitliches _V2-1-Namensschema umbenannt
    und Logic-Board-Revision (Schaltplan/Layout/Gerber) aktualisiert.
    docs/system/assets synchronisiert. Download-ZIP der Leiterplatten neu
    gepackt ohne fp-info-cache-Bloat; Systemdokumentation (ODT/PDF) und
    Werbetext (ODT) neu generiert und in docs/website/downloads gespiegelt.
    [nixieclockin12_V2-1-B_Cu.gbr, nixieclockin12_V2-1-B_Mask.gbr, nixieclockin12_V2-1-B_Paste.gbr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]
2026-10-01 fix: Brownouts beim Start – Anodenwiderstände 22k, Sanftanlauf, Startprotokoll
    Ursache der unsauberen Starts (Blinken, stehende Uhrzeit, Aufblitzen) war
    ein zu hoher Röhrenstrom: Die Anodenwiderstände R65–R70 auf dem Display
    Board hatten 10 kΩ (Referenzuhr: 33 kΩ). Die Uhr zog dadurch mit 6 Röhren
    über 1 A an 5 V, und je nach Netzteil brach die Versorgung ein. Mit 22 kΩ
    sind es ~760 mA, und die Uhr läuft an allen getesteten Netzteilen.
    Firmware:
    - boot_diag.ino/.h: dauerhaftes Startprotokoll im NVS (Reset-Grund,
    zuletzt erreichter Start-Schritt, Laufzeit der letzten 20 Starts),
    Ausgabe beim Booten auf der seriellen Konsole
    - Einschaltlasten entzerrt: Anoden starten geschlos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
    [NixieClockUltra.ino, boot_diag.ino, digit_fade.ino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]
2026-10-01 docs: Anodenwiderstände R65–R70 im Display-Board-Schaltplan auf 22 kΩ
    KiCad-Schaltplan und -Layout (Rev 2.01) auf den neuen Wert der
    Anodenwiderstände angepasst, Leiterplatten-ZIP für die Website neu
    gepackt.
    [nixieclockin12_V2-1.kicad_pcb, nixieclockin12_V2-1.kicad_sch]
2026-10-01 docs: Startprotokoll und echte Startausgabe in Systemdoku ergänzt
    - Abschnitt „Serial Monitor / Debugging“: Beispielausgabe an die
    tatsächlichen Meldungen angepasst, neuer Unterabschnitt zum
    Startprotokoll (boot_diag.ino) mit Lesart und Tabelle der Reset-Gründe
    - Häufige Probleme: Fehlstarts durch Unterspannung (Anodenwiderstände)
    - firmware.md: eigener Abschnitt Startprotokoll, NVS-Namespace „bootlog“
    - Systemdokumentation (ODT/PDF) neu erzeugt
    [gen_sysdoc.py]
2026-10-02 fix: Dimm-Regler wirkungslos – HV-PWM auf 100 Hz / 10 Bit
    Im Nacht-Modus wurden die Röhren zwischen 60 % und 2 % Dimm-Helligkeit
    kaum dunkler. Die Firmware lieferte den richtigen Duty an die Pins (per
    Diagnose-Ausgabe belegt); Ursache ist die Abschaltverzögerung der
    Pro-Röhre-TLP627: Jeder Darlington-Koppler schaltet nur ~1,5 mA Röhren-
    strom bei ~20 mA LED-Strom und ist dadurch tief übersteuert. Die
    Verzögerung verlängert jeden Ein-Puls um einige Millisekunden, bei 200 Hz
    (5 ms Periode) blieb vom Dimmbereich kaum etwas übrig.
    - HV_PWM_FREQ_HZ 200 → 100: Verzögerung wirkt nur noch halb so stark,
    Dimmung auf der Hardware getestet und ausreichend
    - LEDC mit 10 statt 8 Bit, da d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
    [NixieClockUltra.ino, gen_sysdoc.py, hv_dimmer.ino]
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2026-10-13 fix: Startmeldung der HV-PWM-Frequenz zeigte 0 Hz
    ledcReadFreq() liefert 0, solange der Duty 0 ist – die Abfrage stand
    direkt nach dem Initialisieren mit geschlossenen Anoden. Die Meldung
    kommt jetzt am Ende von hvDimmerSoftStart(), wenn die Röhren
    aufgeblendet sind (beide Hardware-Varianten).
2026-10-15 docs: J3 liefert 5 V, keine externen I²C-Pull-ups (Bus nur 100 kHz)
    - hardware.md / Systemdoku: VCC an J3 ist die 5-V-USB-Schiene statt
    3,3 V, Pin-Reihenfolge aus der KiCad-Netzliste
    - Hinweis: SDA/SCL ohne externe Pull-ups, R61–R64 sind Reset-Pull-ups;
    bei 400 kHz/1 MHz scheitert jeder Schreibvorgang (gemessen 2026-10-15)
    - Fehlersuche-Tabelle: nicht existierende Pull-ups R1/R3 ersetzt
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2026-11-10 docs: J5 ist der Anodenschalter-Stecker, LDR ist R6 an +3,3 V
    - J5 (Logic Board) ↔ J3 (Display Board, „AnodeSW“): 8-polig, GPIO 38/47/
    15/16/17/18 + GND – bisher fälschlich als 2-poliger LDR-Stecker geführt
    - LDR = R6 (TKN PGM5637D) nach +3,3 V, R5 100 kΩ nach GND, C6 10 µF,
    über R4 1 kΩ an GPIO6 (laut Netzliste und eBOM); „LDR→VCC“ korrigiert
    - Systemdoku-PDF neu erzeugt
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
